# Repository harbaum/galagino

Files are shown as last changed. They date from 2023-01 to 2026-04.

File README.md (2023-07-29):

# Galagino - ESP32 Arcade Emulator

Play Galaga, Pac-Man, Donkey Kong, Frogger, Digdug and 1942 on the ESP32

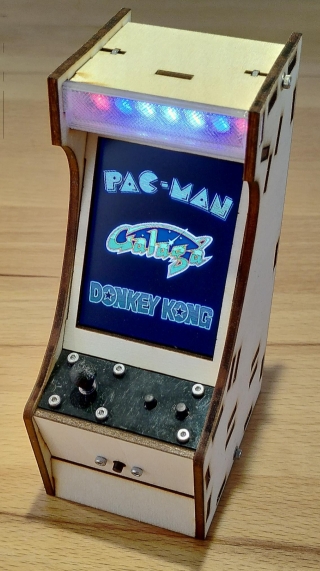
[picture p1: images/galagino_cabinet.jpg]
Cabinet


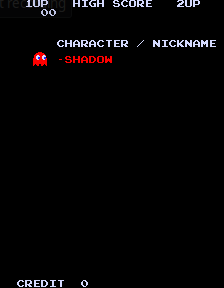
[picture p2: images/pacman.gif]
Pac-Man screenshot

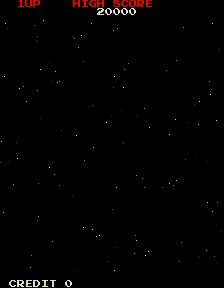
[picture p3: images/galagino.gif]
Galaga screencast

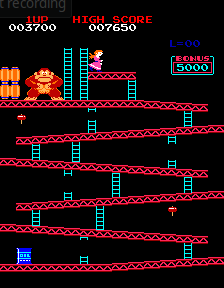
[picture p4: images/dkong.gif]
Donkey Kong screenshot

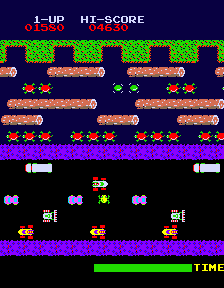
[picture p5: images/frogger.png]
Frogger screenshot

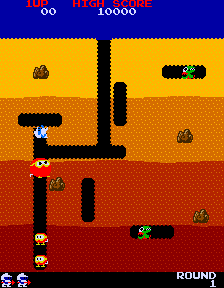
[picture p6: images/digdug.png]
Digdug screenshot

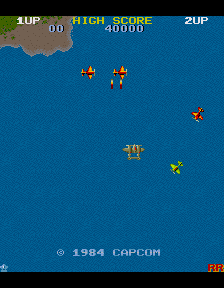
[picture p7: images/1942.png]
1942 screenshot


[Pac-Man](https://en.wikipedia.org/wiki/Pac-Man),
[Galaga](https://en.wikipedia.org/wiki/Galaga) and
[Donkey Kong](https://en.wikipedia.org/wiki/Donkey_Kong_(video_game)) are three of the most
iconic arcade machines of all times and are listed on places #1 to #3
on the [Killer List of Video Games](http://www.klov.net).

Especially Pac-Man and Galaga have been remade and emulated many
times. So far the cheapest and smallest system able to do a faithful
emulation of the original arcade machines was the raspberry pi. But
even the much cheaper ESP32 should be able to easily emulate a machine
from the early ’80s, shouldn't it?

Well, things are not that easy. The Galaga arcade was driven by three
Z80 CPUs, each running at 3Mhz. Additionally the arcade machine
included two more CPUs, one for button and coin handling and one for audio
support. And finally the hardware itself had dedicated support
for simple wavetable audio, tilemap graphics and up to 64 sprites.
The video resultion was 224 by 288 pixels.

The ESP32 on the other hand
comes with two cores running at 240MHz. But it lacks dedicated video
hardware. Emulating the various CPUs as well as the handling of
audio and graphics turned out to be challenging for the ESP32.

Cheap TFT screens with a resolution of 320 by 240 pixels are avaialable
in various sizes from 2.0 inch to 3.2 inch allowing for a very small
and cheap *galagino* setup.

These small displays usually allow for SPI clock rates of up to 40MHz
allowing for a max screen refresh rate of ~30Hz. This is exactly half
the refresh rate of the original arcade machine. 30Hz is sufficient
for a very fluid gameplay. However, with displays coping with 80MHz
SPI clock, Galagino will run at full 60Hz refresh.

## Youtube videos

* [First Galaga Emulation test ](https://www.youtube.com/shorts/LZRI6izM8XM)
* [Sound and Starfield working](https://www.youtube.com/shorts/8uNSv0aRtgY)
* [Galaga is finally playable](https://www.youtube.com/shorts/wqnJzOAAths)
* [Pac-Man on Galagino](https://www.youtube.com/shorts/F4-XiiPwG1c)
* [Donkey Kong on Galagino](https://www.youtube.com/shorts/KROFJ0Rtj0w)
* [Boot menu](https://www.youtube.com/shorts/_PJyn06yrtg)
* [Cardboard cabinet prototype](https://youtube.com/shorts/vverV4NphlQ)
* [Finished plywood cabinet](https://youtube.com/shorts/a3-wctRAIds)
* [John Bradnam's 3D printed case](https://www.youtube.com/watch?v=p29Yvht4jSI)
* [Frogger on Galagino](https://youtube.com/shorts/LrBkN1pu7yE)
* [Digdug on Galagino](https://youtube.com/shorts/fmQmfKEhVy4)

## Hardware

### Original Hardware
The hardware is built around one of those cheap ESP32 development
boards like the ESP32 Devkit V4 depicted in the images below. The
components needed for the breadboard setup are listed below. If you
plan to build the [cabinet](hardware/cabinet) instead you might want
to make sure you [order the exact parts](./hardware) that
aren't only electrically compatible but also mechanically.

* ESP32 development board (e.g. [Devkit V4](https://www.espressif.com/en/products/devkits/esp32-devkitc))
* A 320x240 SPI TFT screen (no touch needed)
  * Either a ILI9341 based screen as depicted, or
  * a ST7789 based screen with 320x240 pixels
* An audio amplifier and speaker
  * e.g. a [PAM8302A](https://www.adafruit.com/product/2130) and a 3W speaker (as seen in the photos), or
  * a [Keyestudio SC8002B](https://www.keyestudio.com/products/keyestudio-sc8002b-audio-power-amplifier-speaker-module-for-arduino-player), or similar 
* five push buttons, or
* one push button and a five way joystick breakout (for Pac-Man and Donkey Kong)
* breadboard and wires

The entire setup should be connected as depicted below. The Devkit is
too wide for the breadboard leaving no space above it to connect
wires. Thus the wires going to the top pin row of the Devkit are
placed underneath the DevKit with the connections done as shown in the
image below. See [galagino/config.h](galagino/config.h) for the button
mappings.

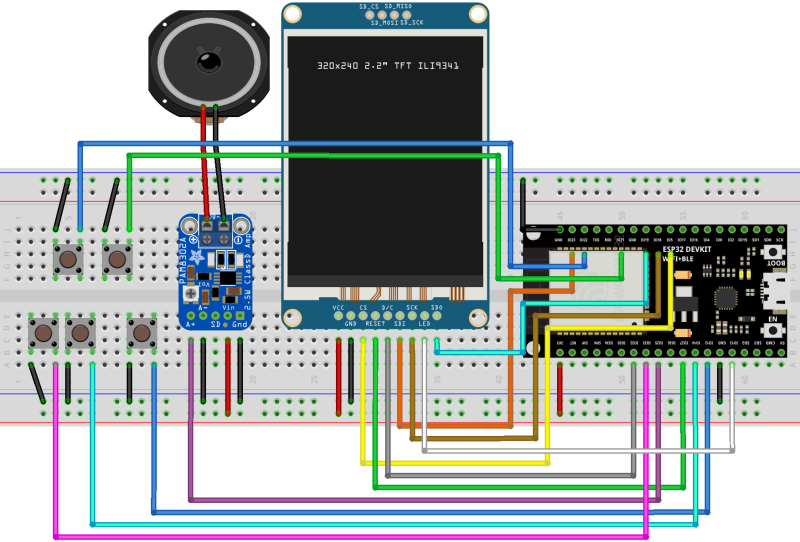
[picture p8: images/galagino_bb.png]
Breadboard scheme


[PDF](images/galagino_bb.pdf)

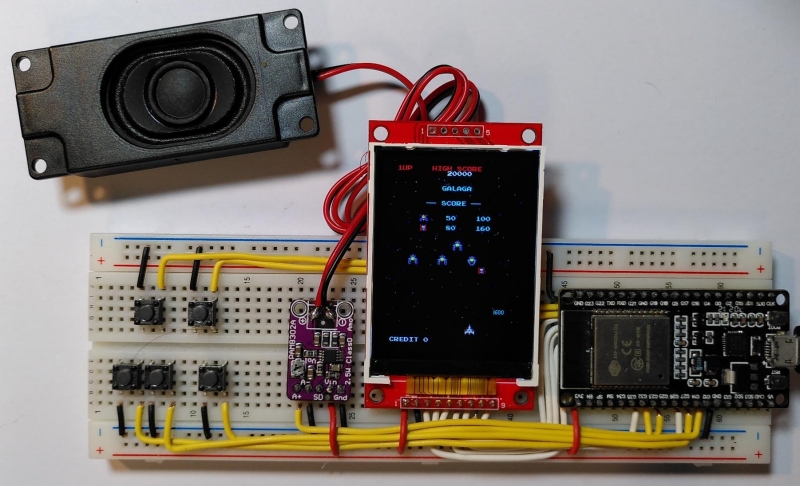
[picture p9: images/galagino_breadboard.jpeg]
Breadboard photo


This setup with five buttons works fine for Galaga since there is no
vertical movement in the game that requires a joystick. A joystick is
needed for Pac-Man and Donkey Kong. The joystick based setup would
then be wired in the following way:

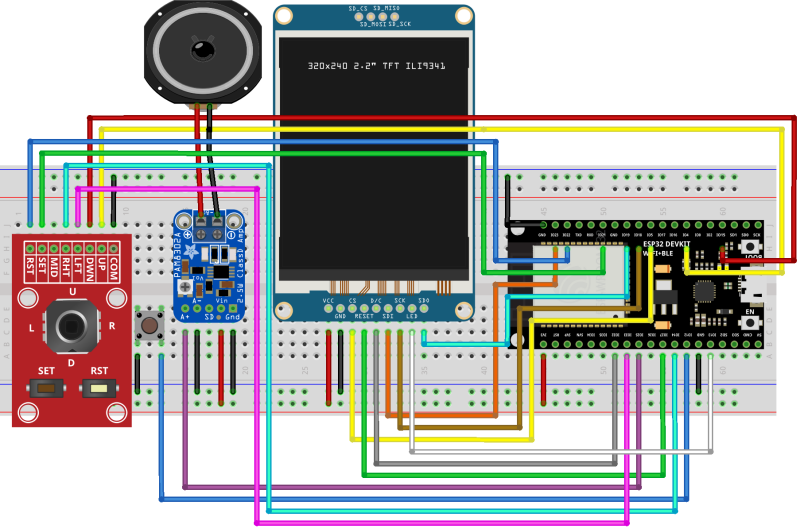
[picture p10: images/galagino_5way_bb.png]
Breadboard scheme with 5 way joystick


[PDF](images/galagino_5way_bb.pdf)

### "Cheap Yellow Display"
The ESP32-2432S028R A.K.A. the [Cheap Yellow Display](https://github.com/witnessmenow/ESP32-Cheap-Yellow-Display) is an ESP32 Board that comes with the majority of hardware required to build a Galagino device.

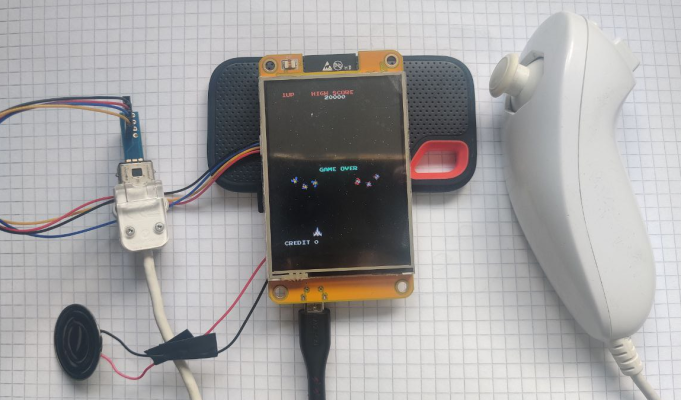
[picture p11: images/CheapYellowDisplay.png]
Cheap Yellow Display


Hardware Needed:
- Cheap Yellow Display
- [A Nintendo Wii nunchuck and adaptor](hardware/NUNCHUCK.MD) - This can be connected to the JST connector labled "CN1" with the cable included with the display
- A speaker - This can be attached to the display with a 1.25mm JST connector to the connector labled "SPEAK" (or soldered)

Note: The `Start` button is connected to the "boot" button on the board.

To get the project working on the Cheap Yellow Display, just uncomment the `#define CHEAP_YELLOW_DISPLAY_CONF` line in [galagino/config.h](galagino/config.h)

## Software

**Important notice 1:** You really need to use the Arduino IDE as it
provides the optimization settings required for sufficient
perfgormance of Galaga and Digdug by default. E.g. PlatformIO doesn't
seem to enable enough optimization.

**Important notice 2:** I2S/DAC support seems to be [broken in the
ESP32 board package version 2.0.10 and
up](https://github.com/espressif/arduino-esp32/issues/8467). Please
use ESP32 board package 2.0.9 or older for a clean sound.

The software consists of three parts:

* The [Galagino specific code](galagino/) contained in this repository
* The orignal ROM files
    * [Galaga (Namco Rev. B ROM)](https://www.bing.com/search?q=galaga+namco+b+rom)
    * [Pac-Man (Midway)](https://www.bing.com/search?q=pacman+midway+arcade+rom)
    * [Donkey Kong (US set 1)](https://www.bing.com/search?q=donkey+kong+arcade+rom)
    * [Frogger](https://www.bing.com/search?q=frogger+arcade+rom)
    * [Digdug](https://www.bing.com/search?q=digdug+arcade+rom)
    * [1942](https://www.bing.com/search?q=1942+arcade+rom)	
* A [Z80 software emulation](https://fms.komkon.org/EMUL8/Z80-081707.zip) by [Marat Fayzullin](https://fms.komkon.org/)

Galagino uses code that is not freely available and thus not included in this
repository. Preparing the firmware thus consists of a few additional steps:

* The ROM files have to be placed in the [roms directory](roms/), together with the ZIP file containing the Z80 emulator.
* A set of [python scripts](romconv/) is then being used to convert and
 patch the ROM data and emulator code and to include the resulting code into the
galagino sketch directory.
* The same scripts are afterwards being used to convert [audio sample files](./samples) into the desired format.

The [ROM conversion](./romconv) as well as the [audio sample
conversion](./samples) create a whole bunch of additional files in the
[galagino directory](./galagino). Please check the README's in the
[romconv](./romconv) and [samples](./samples) directories for further
instructions.

With all these files in place, the galagino.ino sketch can be loaded
into the [Arduino IDE](https://docs.arduino.cc/software/ide-v2). The
Arduino IDE must have the [ESP32 board support](https://docs.espressif.com/projects/arduino-esp32/en/latest/installing.html)
installed and the appropriate board like e.g. the
*ESP32 Dev Module* should be selected. Finally the default core used
by Arduino should be 1 (this is the default) as Galagino will use core 0
for audio and video emulation. Furthermore the FastLED library should
be installed to support the LEDs in the [cabinets marquee](./hardware/cabinet).
LED support can be disabled in the configuration if no LEDs are going to be installed.

## Configuration

The Galagino code can be configured through the [galagino/config.h](galagino/config.h)
file. This is also the place where it's possible to choose between the ILI9341
controller (default) and the ST7789.

Also the pin assignment can be adjusted as well as the TFT SPI clock or the
use of LEDs for the marquee.

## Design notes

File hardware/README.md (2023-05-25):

# Galagino cabinet

This is a list of all parts required to build a complete Galagino
[cabinet from plywood](./cabinet). Further instructions are linked below.

If you don't have access to a laser cutter or prefer a fully 3d
printed case then you should have a look at [John Bradnam's great
Galagino case](https://www.hackster.io/john-bradnam/galagino-esp32-arcade-355dde).

## Electric and electronic parts

* [38 pin ESP32 Devkit](https://www.espressif.com/en/products/devkits/esp32-devkitc)
* 2.8 inch 320x240 ILI9341 display
  * mounted on 50mm x 86mm PCB
  * no touch screen required
* [PAM8302A](https://www.adafruit.com/product/2130) amplifier
* cased 3W / 8 ohms speaker as seen e.g. in the [cabinet photos](./cabinet)
* 7 x WS2812B LED stripe
  * 7 LEDs cut from a 144 LEDs per meter stripe
* four 6mm x 6mm push buttons, through hole, height 4.3mm
* three 6mm x 6mm push buttons, through hole, height 9mm
* ~50 cm 10 wire flat ribbon cable

## Screws and nuts

* 10 pcs M2 x 8mm screws
  * 4 for the [cabinet](./cabinet), 2 for the [coin button](./coinbutton), 4 for the speaker
* 6 pcs M2 x 12mm screws
  * for the 3D printed [control board](./controlboard)
* one M2 x 16mm screw
  * for the 3D printed [control board](./controlboard)
* 14 M2 nuts
  * 6 for the control board, 4 for the cabinet, 4 for the speaker
* 8 M2 washers
  * 4 for the cabinet, 4 for the control board

## Mechanical parts

* [15 lasercut plywood parts](./cabinet)
* [3D printed coin button holder](./coinbutton)
* [3D printed black control board](./controlboard)
* [3D printed transparent marquee](./marquee)

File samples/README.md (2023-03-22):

# Samples

Some arcade machines contained special hardware to generate certain
sounds. Emulating this hardware may be tricky and the flash memory
size of the ESP32 allows to store some of these as digital sound
samples.

This directory contains one sample needed for the explosion sound
in Galaga and three more samples for Donkey Kong.

These have to be converted into C source code using the
[romconv.py](../romconv/romconv.py) tool.

```
../romconv/romconv.py galaga_sample_boom ./galaga_boom.s8 ../galagino/galaga_sample_boom.h
```

Donkey Kong does most audio via its MB8884/I8048 audio CPU. But three
sounds are generated via discrete logic including three variants of
the walk sound. These are still regenerated using samples.

```
../romconv/romconv.py dkong_sample_walk0 ./dkong_walk0.s8 ../galagino/dkong_sample_walk0.h
../romconv/romconv.py dkong_sample_walk1 ./dkong_walk1.s8 ../galagino/dkong_sample_walk1.h
../romconv/romconv.py dkong_sample_walk2 ./dkong_walk2.s8 ../galagino/dkong_sample_walk2.h
../romconv/romconv.py dkong_sample_jump ./dkong_jump.s8 ../galagino/dkong_sample_jump.h
../romconv/romconv.py dkong_sample_stomp ./dkong_stomp.s8 ../galagino/dkong_sample_stomp.h
```

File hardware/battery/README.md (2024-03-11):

# Battery powered Galagino

The Galagino by default runs from USB power supply. The cabinet
has some empty space at its very bottom which can be used to
mount a battery incl. charger and 5V supply. The parts can
be mounted to [part 8 of the cabinet](../cabinbet). 

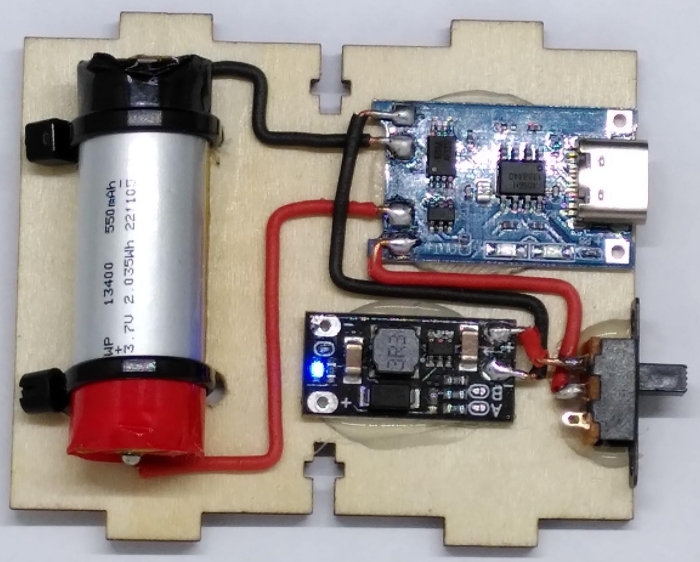
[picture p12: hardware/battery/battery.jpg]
Battery mounted


The battery in this example has been take from a Vape. Although
these are designed to be disposable they contain rechargeable
batteries which can be re-used in projects like this. The one
depicted above is a 550 mAh battery from a vape. These can
be disassembled rather easily and besides the strong sweet smell
these are easy to use.

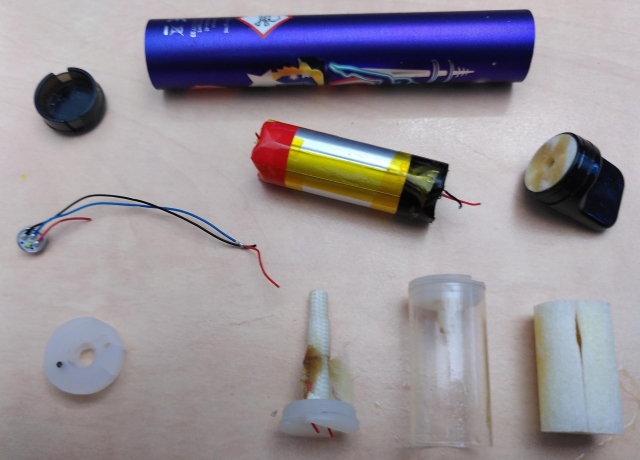
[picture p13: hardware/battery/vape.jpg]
Vape


Only few parts are needed besides the battery itself.

  - A charger board (e.g. powered via USB)
  - A battery protection circuit
  - A DC/DC converter generating 5V from the battery voltage

Various cheap charger boards contain some or all of these parts.
The setup depicted above uses the two board. The top one
combines a USB charger with the battery protection circuit.
The smaller PCB at the bottom is a DC/DC converter generating
5V from the batteries 3.7V.

A toggle switch mounted between the battery and the DC/DC
converter allows to turn the device on and off. The 5V are
then fed into the 5V input of the ESP32 board.

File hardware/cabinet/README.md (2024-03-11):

# Cabinet

The cabinet is built from 15 lasercut 3mm plywood parts and is designed to
house [common off-the-shelf electronic components](../).

## Versions

There are currently two versions of the case. 

- [lasercut_parts.svg](lasercut_parts.svg) is the original version to be
  used with a USB power supply (no battery) and with a wiring directly
  done to the board (no additional PCBs)
  
- [lasercut_parts_with_battery.svg](lasercut_parts_with_battery.svg) is
  a slightly modified version with the following changes:

    - Cutouts in part 8 to allow to mount a [small battery](../battery) using zip ties
    - Cutouts in part 12 for a power switch and the USB connector of a charging board mounted in part 8
    - Cutout in part 1 to give some room to the joystick connector of the [PCB set](../pcbs).
    - Shortended the "arm" of part 10 a little bit to make room for the cable connecting the LED stripe 
    - Cutouts in parts 11 and 13 to allow a power cable to be routed from the battery to the ESP32

The cabinet may have to be modified further if different parts are being used.

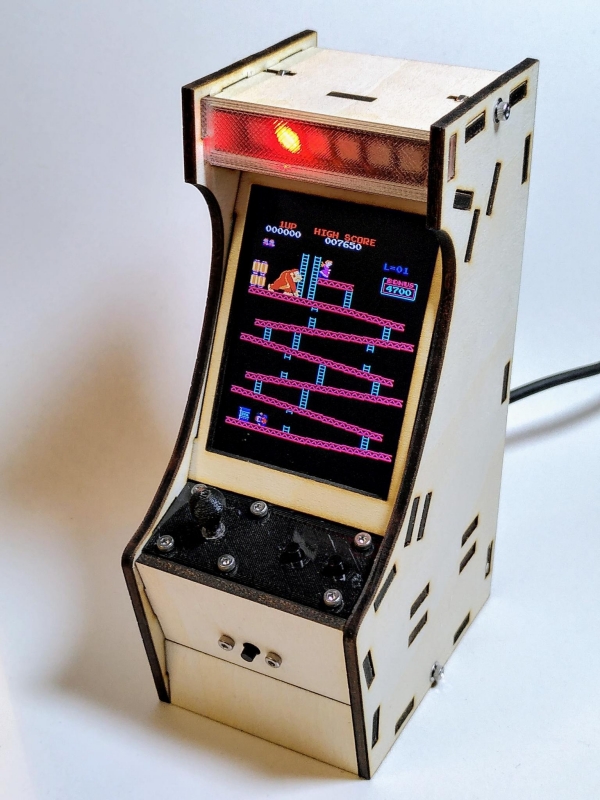
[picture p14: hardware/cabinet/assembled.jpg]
The assembled cabinet


The cabinet consists of two main side sections and 13 parts to be
mounted between both sides. The electronic parts are either secured
between two wooden parts (the display between parts 1, 5 and 10 and
the ESP32 between parts 11 and 13) or screwed to a wooden part (the
speaker to part 12 and the coin button to part 6). The LED stripe
comes with adhesive tape and sticks to its wooden part 9.

The [transparent plastic part for the marquee](../marquee) as well as
the [control board](../controlboard) and the [coin
button](../coinbutton) are 3d printed and are either screwed to the
plywood parts 6 and 12 or use the same 3mm flanges and are inserted
into the side parts just like the other wooden parts are.

If no illuminated marquee is wanted, then the plywood part 2 is used
instead of the 3D printed transparent part and the LED stripe is not
attached to part 9.

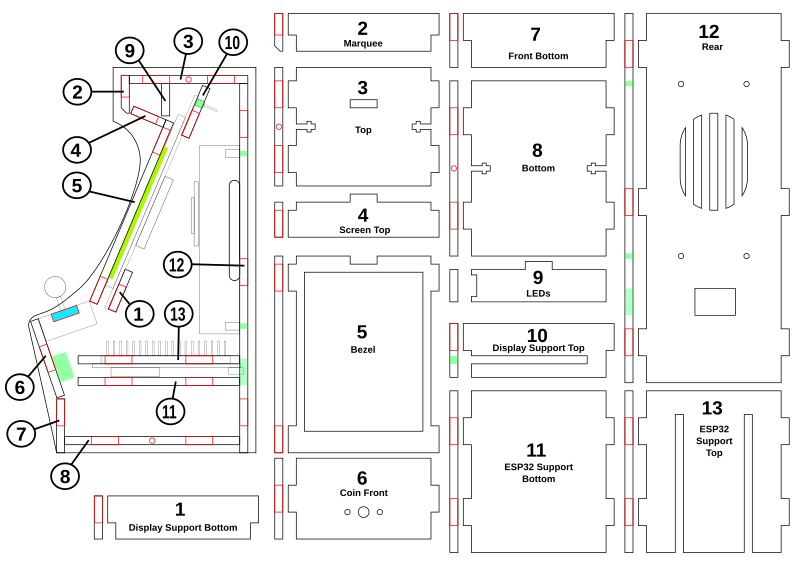
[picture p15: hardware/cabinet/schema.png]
Schema


Also available as [PDF](schema.pdf)

The following files can be used with most laser cutters. All parts fit
onto one single A4 sized piece of 3mm thick plywood.

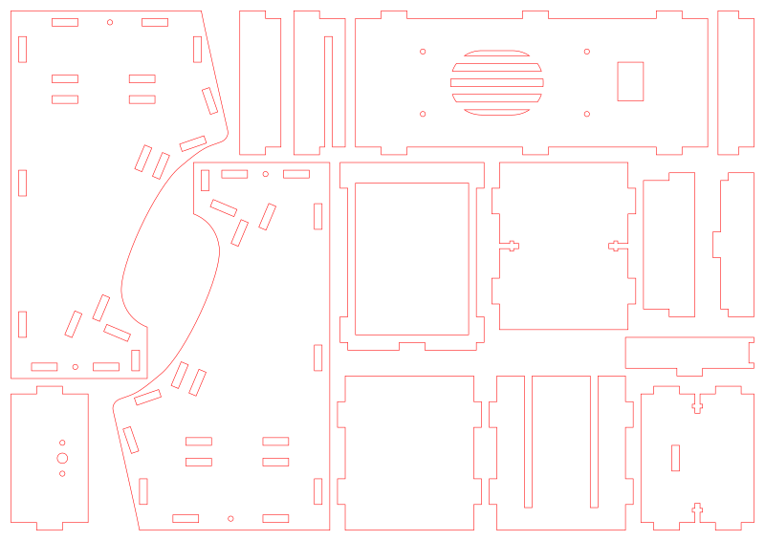
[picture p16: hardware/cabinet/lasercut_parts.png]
Lasercut Parts CAD


Also available as [SVG](lasercut_parts.svg) and [PDF](lasercut_parts.pdf)

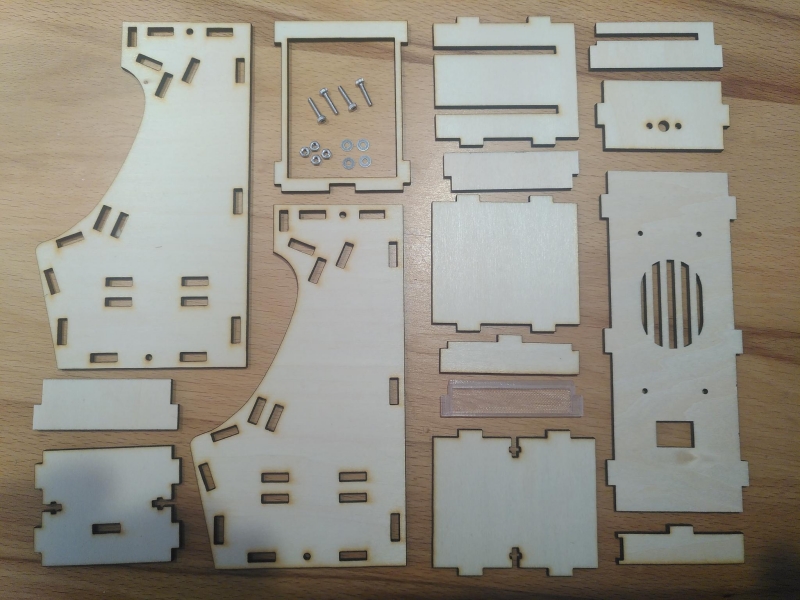
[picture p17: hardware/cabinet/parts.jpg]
Lasercut Parts


Once the electronics are [assembled and tested](../assembly) they are
mounted to their plywood parts.

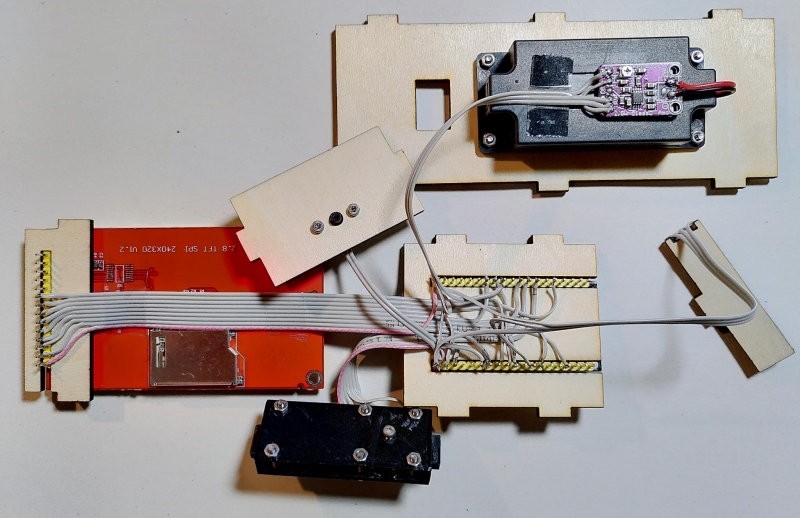
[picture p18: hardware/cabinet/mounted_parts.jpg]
Mounted parts


The LEDs are attached to plywood part 9 and inserted into the top part
3. Once the top part is secured to one side using a M2*8mm screw part
9 attaches quite firmly to the top part 3. Its cable needs to go above
the display and plywood part 10.

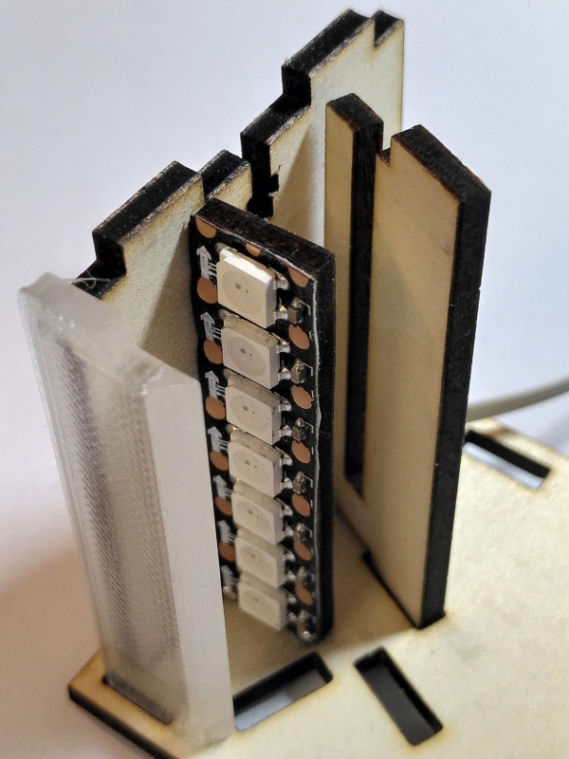
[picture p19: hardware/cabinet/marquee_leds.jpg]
Marquee LEDs detail


All parts are assembled onto one of the two identical side parts. Afterwards the second side is mounted.

It's helpful to leave the rear part 12 open while attaching the second
side. That way the other parts inside can be reached from the rear and be moved to their exact positions until both sides attach firmly.

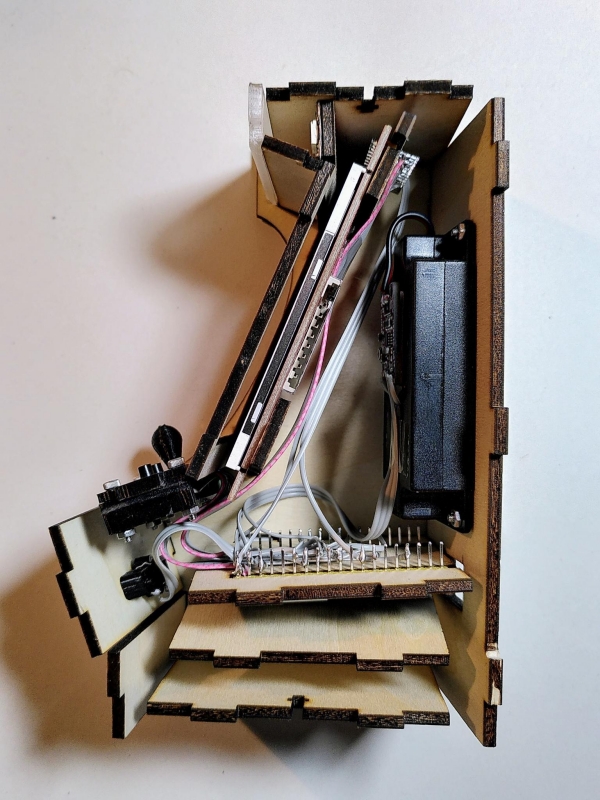
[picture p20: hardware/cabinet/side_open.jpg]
One side open


Once both sides are fully attached the rear part 12 can carefully be
inserted to finish the setup. During assembly the sides may be secured
using e.g. masking tape. Once they are done four M2 * 8mm screws and
four M2 nuts are used to secure the sides to parts 3 and 8.

Be careful not to drop the nuts into the assembled device. A piece of
tape placed at the inside of parts 3 and 8 may help keeping the nuts
from being lost during assembly.

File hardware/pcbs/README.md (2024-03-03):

# Galagino PCB set

The Galagino PCB set is meant to make assembly much easier.
It consists of three PCBs. One is for the display, one for the
ESP32 and one for the joystick. 

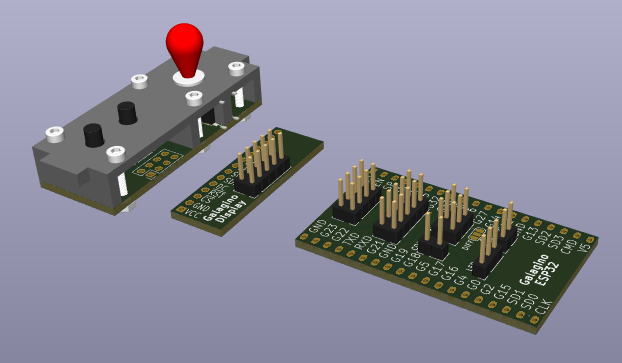
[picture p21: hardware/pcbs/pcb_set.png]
3D rendering of PCB set


The joystick comes with a freecad design for matching plastic parts:

- The main cover [controlboard_base.stl](controlboard_base.stl)
- The actuator that pusges against the direction buttons [controlboard_actuator.stl](controlboard_actuator.stl)
- The joystick control knob [controlboard_knob.stl](controlboard_knob.stl)
- Two raiser to be mounted below the start and fire button [btn_raiser.stl](btn_raiser.stl)

The joystick uses standard 6x6mm through-hole buttons with the legs
bent 90 deg outwards to go through the PCB and the other legs being
cut.

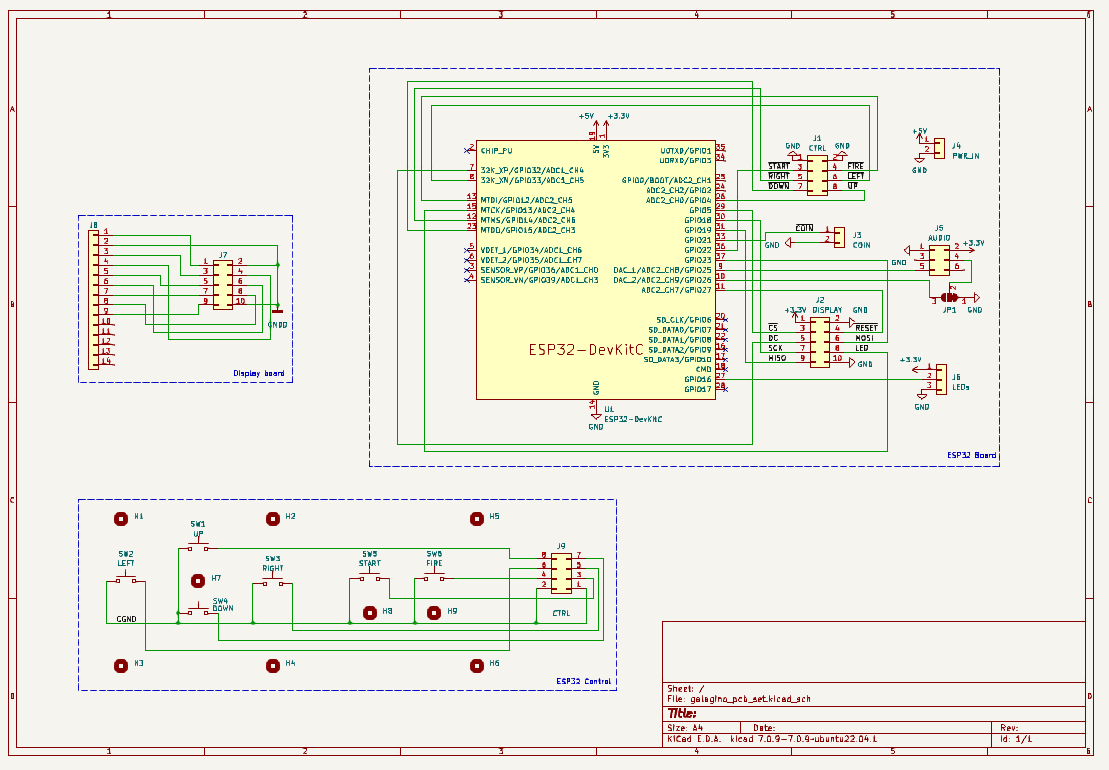
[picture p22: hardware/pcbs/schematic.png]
Schematic
[PDF](schematic.pdf)

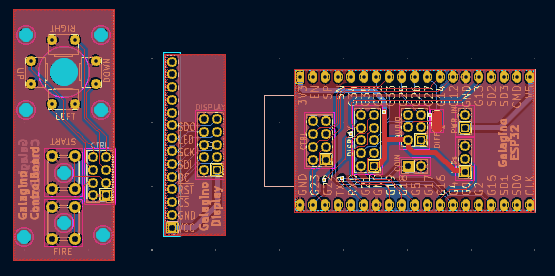
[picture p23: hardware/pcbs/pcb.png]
PCBs


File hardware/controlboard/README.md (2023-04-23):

# Galagino Control Board

The control board is a simple joystick and button compartment for
use with galagino. It consists of four 3d printed parts.

Additionally needed:

- Six screws M2x12mm
- One screw M2x16mm
- Six M2 nuts
- Four M2 washers
- Four 6x6mm push buttons, through hole, height 4.3mm
- Two 6x6mm push buttons, through hole, height 9mm

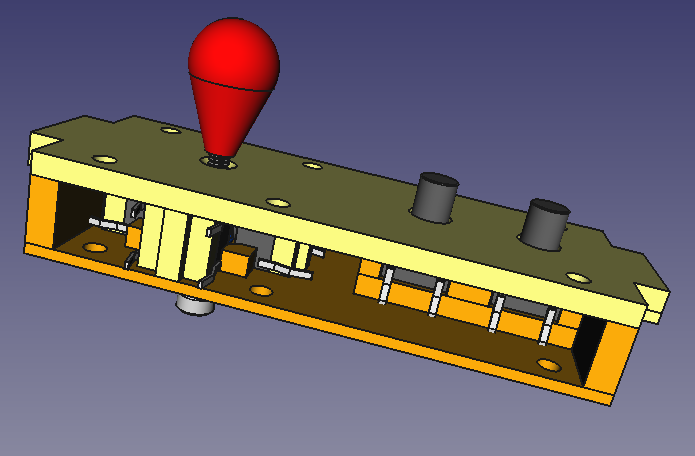
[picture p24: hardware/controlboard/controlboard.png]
CAD screenshot


The control boards surface is 50mm wide and thus matches the width
of a 2.8 inch TFT display. The control board has two 3x10mm flanges
to be used with a small laser cut cabinet.

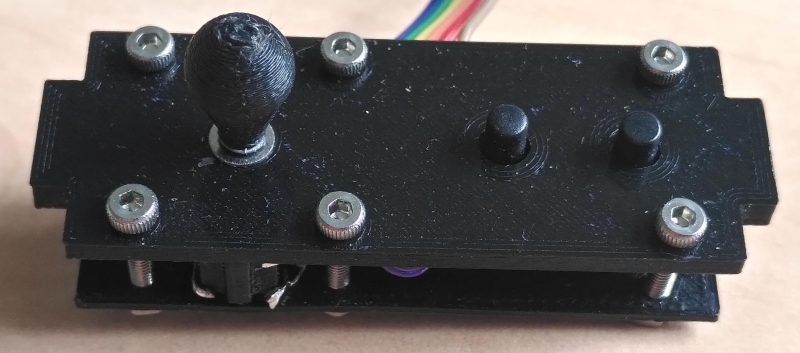
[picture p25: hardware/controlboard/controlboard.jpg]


## Wiring

The colors and order of the wires in the following schema matches the
colors and order of the wires in the [assembly instructions](../assembly).

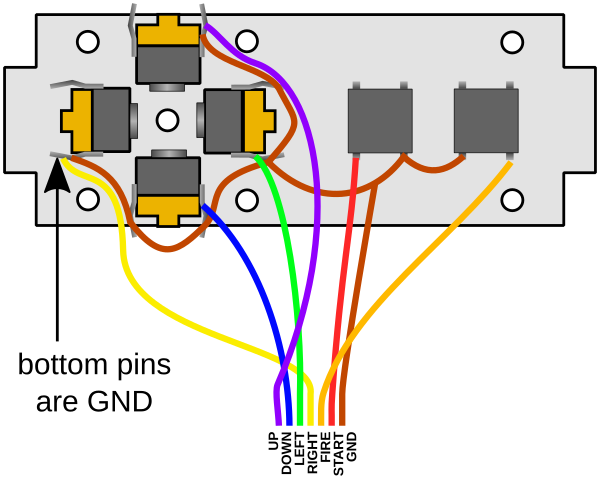
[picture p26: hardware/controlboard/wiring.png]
Wiring


The wiring of the controlboard is a little bit delicate. It starts
with a GND wire connecting one pin of each button. The wires may
protrude to the bottom as this will be inside the final cabinet. But
they must not protrude to the top as this will be the front face which
is convered by a plywood part which won't leave any space for cables.

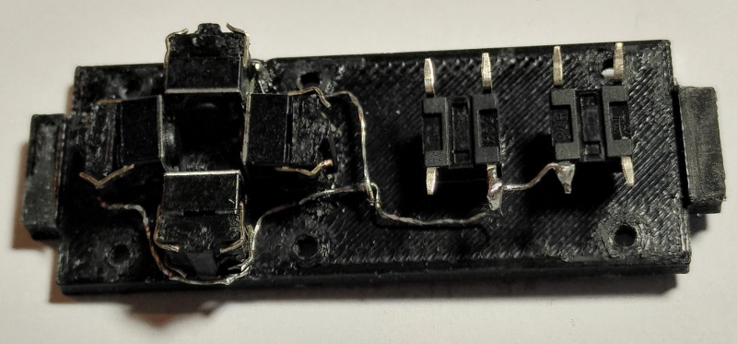
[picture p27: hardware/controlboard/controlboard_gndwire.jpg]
GND wire


Once all ground connections are done, a seven wire ribbon cable is
connected to all buttons and to the GND wire:

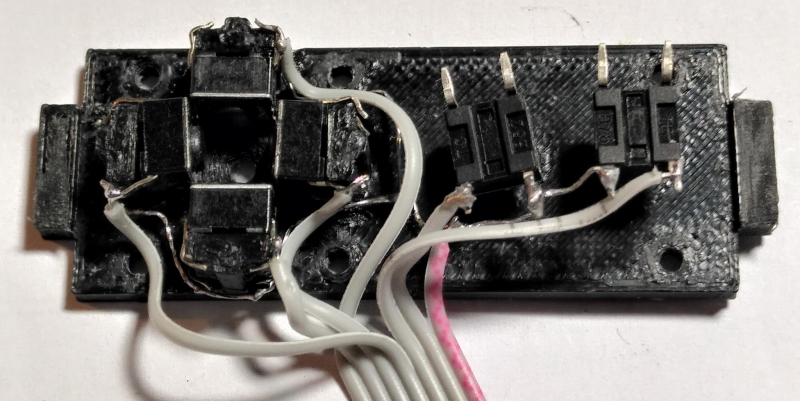
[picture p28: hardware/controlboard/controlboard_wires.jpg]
wires


## Assembly

Assembly starts with the buttons being attached to the base plate and
being soldered to the wires. The limiter and actuator are assembled
with the M2x16mm screw and one M2 washer.

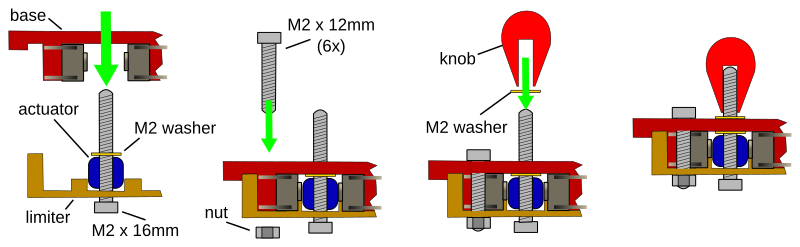
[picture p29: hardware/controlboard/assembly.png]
Assembly


Both parts are then connected using six M2x12mm screws and nuts. And
finally the knob is attached with another M2 washer.

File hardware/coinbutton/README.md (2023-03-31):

# Coin Button

This is a simple bracket needed to mount the coin button to the
[cabinet](../cabinet).

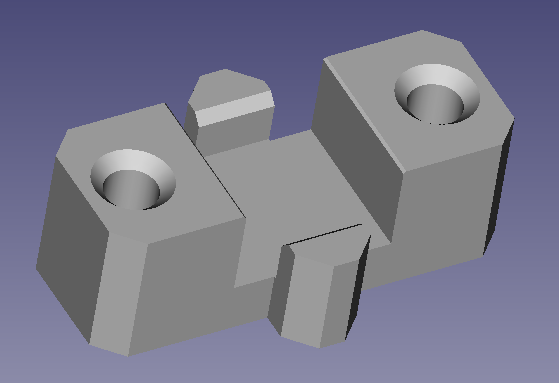
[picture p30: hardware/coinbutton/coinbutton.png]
CAD


Additionally needed:

- Two screws M2 x 8mm
- One 6x6mm push button, through hole, height 9mm

The coinbutton is screwed to part 6 of the [cabinet](../cabinet).

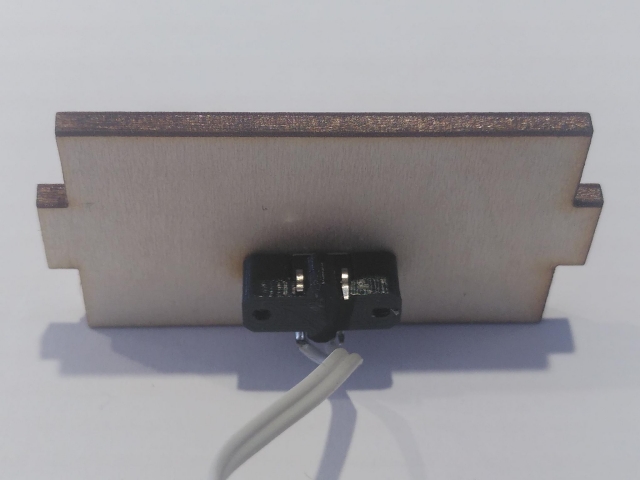
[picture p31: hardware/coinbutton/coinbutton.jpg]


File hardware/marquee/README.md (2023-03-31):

# Marquee

The marquee can optionally be equipped with seven WS2812B LEDs.
The [cabinet](../cabinet) part 2 made of plywood then needs to be
replaced by this transparent 3d printed replacement.

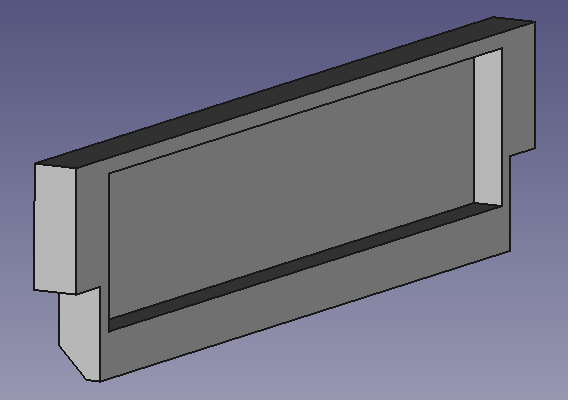
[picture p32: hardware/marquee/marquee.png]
Marquee CAD


[FreeCAD](marquee.FCStd) [STL](marquee.stl)

This part is then mounted at the cabinets top front.

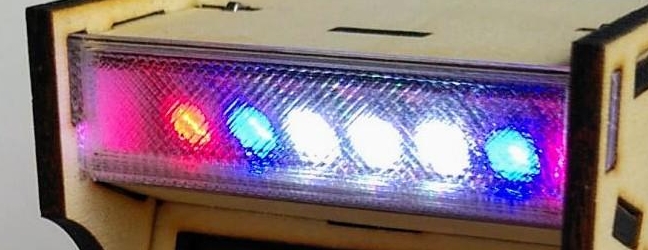
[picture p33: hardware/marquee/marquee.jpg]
Marquee photo


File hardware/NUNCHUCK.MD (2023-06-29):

# Nunchuck

A Nunchuck controller from a Nintendo Wii can be used as input device for Galagino builds. 
They are inexpensive and since they use i2c for communication, they only require 2 GPIO pins to connect them up.

## Hardware Required

- Nunchuck controller - Official Nintendo ones are generally better (maybe try second-hand options), but third-party ones also work fine.
- A Nunchuck adapter - Here is one from [Adafaruit](https://www.adafruit.com/product/4836), but there are many different options available for these, even the cheap ones from Aliexpress work perfectly.

## Wiring

- SDA and SCL of the Nunchuck can be connected to any two GPIO of the ESP32. 
- Power pins of the Nunchuck should be connected to 3.3v and Gnd

Note: I have found pull-ups resistors are not required on SDA and SCL

## Configuration

The nunchuck can be enabled in 'conf.h' as follows

```
#define NUNCHUCK_INPUT

#define NUNCHUCK_SDA 22 // The GPIO pin connected to SDA of the nunchuck
#define NUNCHUCK_SCL 27 // The GPIO pin connected to SCL of the nunchuck

#define NUNCHUCK_MOVE_THRESHOLD 30 // This is the dead-zone for where minor movements on the stick will not be considered valid movements
                                   // Increase this value if you want to increase how far you need to move the nunchuck for a valid movement
```

Note: At time of writing the Start and optional Coin button are not enabled on the nunchuck and will still need to be wired to regular GPIO buttons

## Software

The nunchuck code requires an addtional library to be installed, [NintendoExtensionCtrl](https://github.com/dmadison/NintendoExtensionCtrl). It can be installed from the library manager.

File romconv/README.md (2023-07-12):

# romconv - ROM/bin file conversion

Arcade emulation involves dealing with the original ROM files of the
machines to be emulated. Sometimes the conversion is limited to the
transcription from binary to an equivalent C source file. But in many
cases the conversion includes further data processing. E.g. all color
tables are converted into the 16 bit color format used by the ILI9341
or ST7789 displays. Sprite and tile data is converted into a format
easier to process on the ESP32.

The conversion could be done on the ESP32 target at run time. But in
Galagino it's done beforehand. This offloads these tasks from the
ESP32.

It's possible to implement only one or two of the three arcade
machines. In that case the related ROM conversion can be omitted and
the machine in question has to be disabled in the file
[config.h](../galagino/config.h).

The necessary ROM files need be placed in the [roms
directory](../roms) before these scripts can be run. Once these are
converted the [audio samples](../samples) also need to be converted.

The logo conversion for the game selection menu might require the
seperate installation of the ```imageio python module``` which can
e.g. be done by the following command. This is usually not needed as
the logos are included pre-converted. This is only needed if you intend
the change the logos.

```pip3 install imageio```

## Do-it-all script

A [shell script](conv.sh) is included that does all the conversion.
If you prefer to do everything manually, then use the instructions
below. Otherwise running the script is all you need to do.

## Generic ROM conversion

The tilemap as well as the patched Z80 emulation are need by all three
arcade machines and thus have to be converted regardless which
machines are to be emulated.

```
./tileaddr.py ../galagino/tileaddr.h
./z80patch.py
```

## Pac-Man ROM conversion

Pac-Man comes with code ROMs as well as ROMs containing graphic data,
color tables and audio waveforms. These can be converted using the
following commands:

```
./audioconv.py pacman_wavetable ../roms/82s126.1m ../roms/82s126.3m ../galagino/pacman_wavetable.h
./cmapconv.py pacman_colormap ../roms/82s123.7f 0 ../roms/82s126.4a ../galagino/pacman_cmap.h
./logoconv.py ../logos/pacman.png ../galagino/pacman_logo.h
./romconv.py pacman_rom ../roms/pacman.6e ../roms/pacman.6f ../roms/pacman.6h ../roms/pacman.6j ../galagino/pacman_rom.h
./spriteconv.py pacman_sprites pacman ../roms/pacman.5f ../galagino/pacman_spritemap.h
./tileconv.py ../roms/pacman.5e ../galagino/pacman_tilemap.h
```

## Galaga ROM conversion

Galaga is technically very similar to Pac-Man and needs very similar
files. In this case three code ROMs need to be converted as the Galaga
arcade was driven by three Z80 CPUs.

The Galaga ROM for CPU #1 will be patched when given the ```-p```
option. This will disable the RAM and ROM tests of the Galaga arcade
machine and will speed up the loading of that machine in Galagino:

```
./romconv.py -p galaga_rom_cpu1 ../roms/gg1_1b.3p ../roms/gg1_2b.3m ../roms/gg1_3.2m ../roms/gg1_4b.2l ../galagino/galaga_rom1.h
```

For the full retro-experience simply omit the option and the resulting
Galagino setup will include all the self tests of the original
machine:

```
./romconv.py galaga_rom_cpu1 ../roms/gg1_1b.3p ../roms/gg1_2b.3m ../roms/gg1_3.2m ../roms/gg1_4b.2l ../galagino/galaga_rom1.h
```

The remaining files are just converted without patching.

```
./audioconv.py galaga_wavetable ../roms/prom-1.1d ../galagino/galaga_wavetable.h
./cmapconv.py galaga_colormap_sprites ../roms/prom-5.5n 0 ../roms/prom-3.1c ../galagino/galaga_cmap_sprites.h
./cmapconv.py galaga_colormap_tiles ../roms/prom-5.5n 16 ../roms/prom-4.2n ../galagino/galaga_cmap_tiles.h
./logoconv.py ../logos/galaga.png ../galagino/galaga_logo.h
./romconv.py galaga_rom_cpu2 ../roms/gg1_5b.3f ../galagino/galaga_rom2.h
./romconv.py galaga_rom_cpu3 ../roms/gg1_7b.2c ../galagino/galaga_rom3.h
./spriteconv.py galaga_sprites galaga ../roms/gg1_11.4d ../roms/gg1_10.4f ../galagino/galaga_spritemap.h
./starsets.py ../galagino/galaga_starseed.h
./tileconv.py ../roms/gg1_9.4l ../galagino/galaga_tilemap.h
```

Additionally the sample for the Galaga explosion sound needs to be
converted as described in the [samples](../samples) directory.

## Donkey Kong ROM conversion

Donkey Kong differs slightly from Pac-Man and Galaga but it also
conists code ROMs, graphics and colormaps that need to be converted.

```
./cmapconv.py dkong_colormap ../roms/c-2k.bpr ../roms/c-2j.bpr 0 ../roms/v-5e.bpr ../galagino/dkong_cmap.h
./logoconv.py ../logos/dkong.png ../galagino/dkong_logo.h
./romconv.py dkong_rom_cpu1 ../roms/c_5et_g.bin ../roms/c_5ct_g.bin ../roms/c_5bt_g.bin ../roms/c_5at_g.bin ../galagino/dkong_rom1.h
./romconv.py dkong_rom_cpu2 ../roms/s_3i_b.bin ../roms/s_3j_b.bin ../galagino/dkong_rom2.h
./spriteconv.py dkong_sprites dkong ../roms/l_4m_b.bin  ../roms/l_4n_b.bin  ../roms/l_4r_b.bin  ../roms/l_4s_b.bin ../galagino/dkong_spritemap.h  
./tileconv.py ../roms/v_5h_b.bin ../roms/v_3pt.bin ../galagino/dkong_tilemap.h
```

Sound was implemented in two different ways in Donkey Kong. Some
sounds were generated by the 8048 CPU which is emulated in
Galagino. But some sounds were generated using discrete logic. These
are generated from samples and need to be converted as described in
the [samples](../samples) directory.

## Frogger ROM conversion

Frogger uses the same ROM for tiles and sprites. Sprite and tile
coversion thus operate on the same files using the following commands:

```
./cmapconv.py frogger_colormap ../roms/pr-91.6l ../galagino/frogger_cmap.h
./logoconv.py ../logos/frogger.png ../galagino/frogger_logo.h
./romconv.py frogger_rom_cpu1 ../roms/frogger.26 ../roms/frogger.27 ../roms/frsm3.7 ../galagino/frogger_rom1.h
./romconv.py frogger_rom_cpu2 ../roms/frogger.608 ../roms/frogger.609 ../roms/frogger.610 ../galagino/frogger_rom2.h
./spriteconv.py frogger_sprites frogger ../roms/frogger.606 ../roms/frogger.607 ../galagino/frogger_spritemap.h
./tileconv.py ../roms/frogger.606 ../roms/frogger.607 ../galagino/frogger_tilemap.h
```

## Digdug ROM conversion

The Digdug hardware is very similar to Galaga. The video hardware is slightly more complex and
there are more video related ROMs to be converted.

```
./cmapconv.py digdug_colormap_tiles ../roms/136007.113 0 ../roms/136007.112 ../galagino/digdug_cmap_tiles.h
./cmapconv.py digdug_colormap_sprites ../roms/136007.113 16 ../roms/136007.111 ../galagino/digdug_cmap_sprites.h
./cmapconv.py digdug_colormaps ../roms/136007.113 ../galagino/digdug_cmap.h
./logoconv.py ../logos/digdug.png ../galagino/digdug_logo.h
./audioconv.py digdug_wavetable ../roms/136007.110 ../roms/136007.109 ../galagino/digdug_wavetable.h
./romconv.py digdug_rom_cpu1 ../roms/dd1a.1 ../roms/dd1a.2 ../roms/dd1a.3 ../roms/dd1a.4 ../galagino/digdug_rom1.h
./romconv.py digdug_rom_cpu2 ../roms/dd1a.5 ../roms/dd1a.6 ../galagino/digdug_rom2.h
./romconv.py digdug_rom_cpu3 ../roms/dd1.7 ../galagino/digdug_rom3.h
./romconv.py digdug_playfield ../roms/dd1.10b ../galagino/digdug_playfield.h
./spriteconv.py digdug_sprites digdug ../roms/dd1.15 ../roms/dd1.14 ../roms/dd1.13 ../roms/dd1.12 ../galagino/digdug_spritemap.h
./tileconv.py ../roms/dd1.9 ../galagino/digdug_tilemap.h
./tileconv.py ../roms/dd1.11 ../galagino/digdug_pftiles.h
```

## 1942 ROM conversion

1942 uses more and more colorful graphics than the other systems and thus uses more and bigger graphics ROMs. It#s also the only system on this list using banking techniques to increase the CPU code ROM sizes.

```
./cmapconv.py _1942_colormap_chars ../roms/sb-5.e8,../roms/sb-6.e9,../roms/sb-7.e10 128 ../roms/sb-0.f1 ../galagino/1942_character_cmap.h
./cmapconv.py _1942_colormap_tiles ../roms/sb-5.e8,../roms/sb-6.e9,../roms/sb-7.e10 -1 ../roms/sb-4.d6,../roms/sb-3.d2,../roms/sb-2.d1 ../galagino/1942_tile_cmap.h
./cmapconv.py _1942_colormap_sprites ../roms/sb-5.e8,../roms/sb-6.e9,../roms/sb-7.e10 64 ../roms/sb-8.k3 ../galagino/1942_sprite_cmap.h
./logoconv.py ../logos/1942.png ../galagino/1942_logo.h
./romconv.py _1942_rom_cpu1 ../roms/srb-03.m3 ../roms/srb-04.m4 ../galagino/1942_rom1.h
./romconv.py _1942_rom_cpu1_b0 ../roms/srb-05.m5 ../galagino/1942_rom1_b0.h
./romconv.py _1942_rom_cpu1_b1 ../roms/srb-06.m6 ../galagino/1942_rom1_b1.h
./romconv.py _1942_rom_cpu1_b2 ../roms/srb-07.m7 ../galagino/1942_rom1_b2.h
./romconv.py _1942_rom_cpu2 ../roms/sr-01.c11 ../galagino/1942_rom2.h
./spriteconv.py _1942_sprites 1942 ../roms/sr-14.l1 ../roms/sr-15.l2 ../roms/sr-16.n1 ../roms/sr-17.n2 ../galagino/1942_spritemap.h
./tileconv.py ../roms/sr-02.f2 ../galagino/1942_charmap.h
./tileconv.py ../roms/sr-08.a1 ../roms/sr-09.a2 ../roms/sr-10.a3 ../roms/sr-11.a4 ../roms/sr-12.a5 ../roms/sr-13.a6 ../galagino/1942_tilemap.h
```

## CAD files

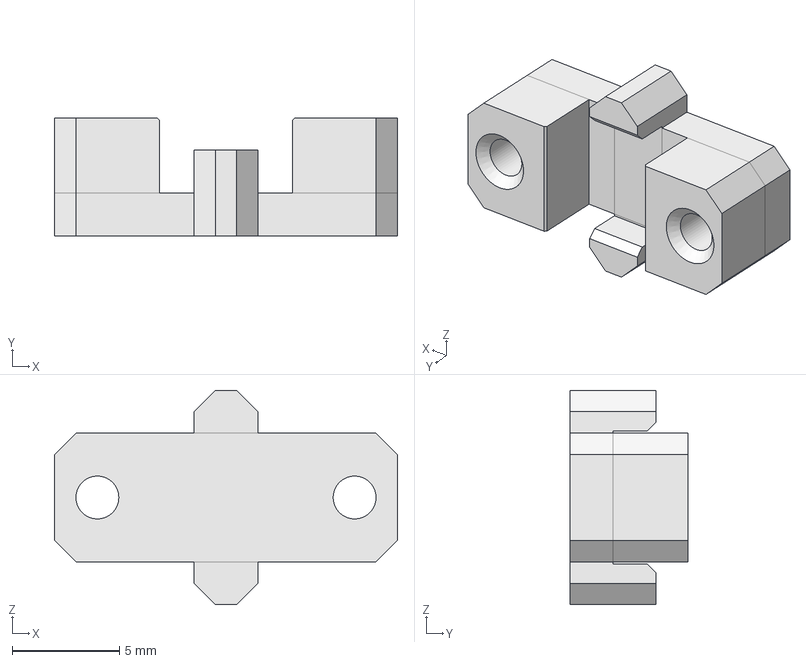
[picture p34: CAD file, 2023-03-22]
hardware/coinbutton/coinbutton.FCStd
16.0 x 5.50 x 10.0 mm

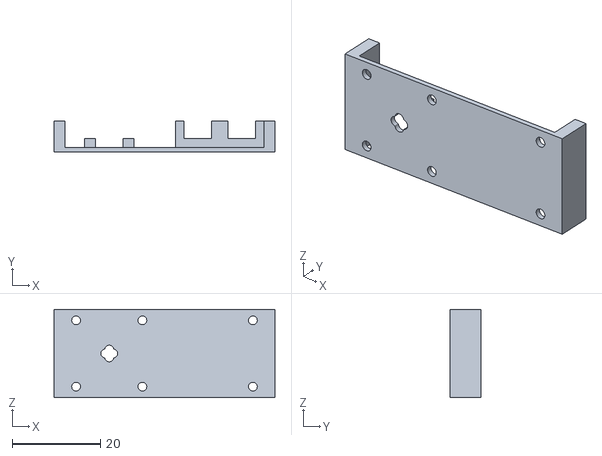
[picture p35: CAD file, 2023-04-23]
hardware/controlboard/galagino_controlboard-limiter.stl
50.0 x 7.00 x 20.0

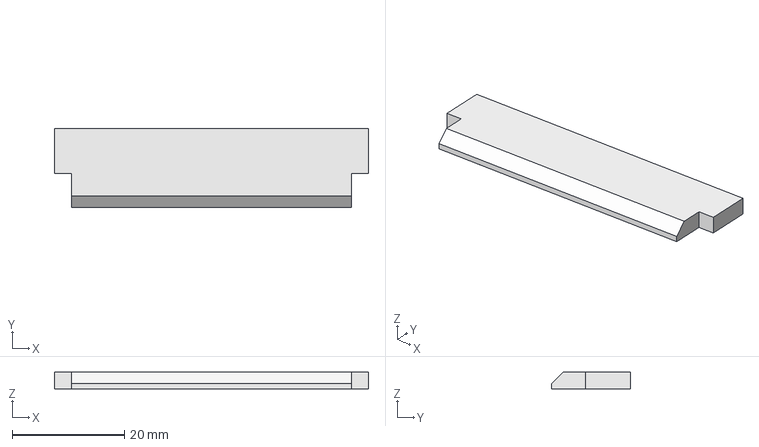
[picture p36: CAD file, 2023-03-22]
hardware/marquee/marquee.FCStd
56.0 x 14.0 x 3.00 mm

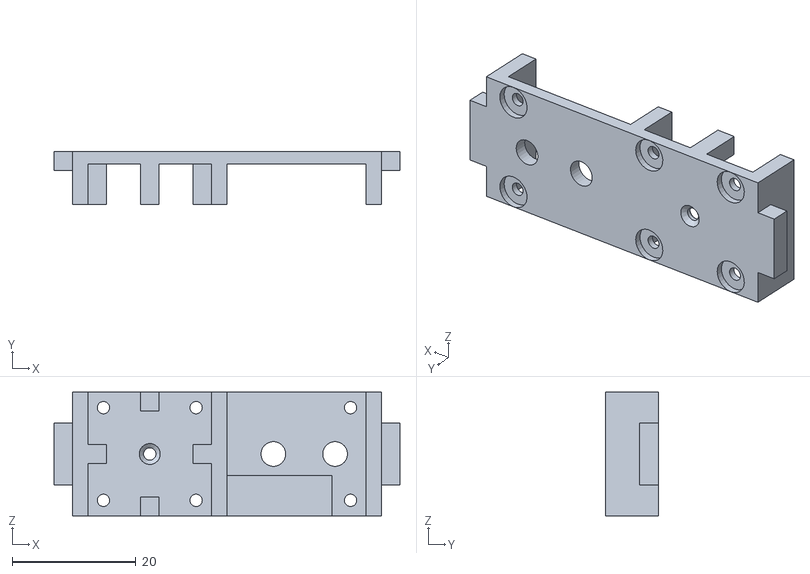
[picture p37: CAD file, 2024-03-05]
hardware/pcbs/controlboard_base.stl
56.0 x 8.50 x 20.0

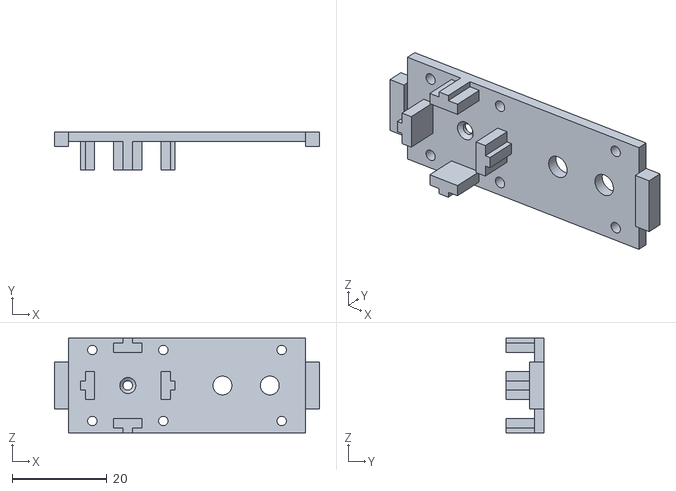
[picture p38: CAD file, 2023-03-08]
hardware/controlboard/galagino_controlboard-base.stl
56.0 x 8.00 x 20.0

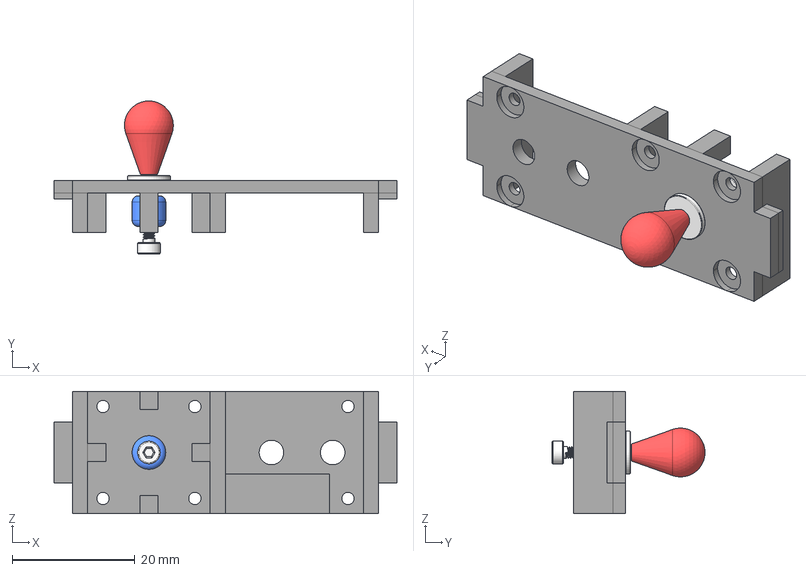
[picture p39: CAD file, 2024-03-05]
hardware/pcbs/controlboard.FCStd
56.0 x 25.0 x 20.0 mm
base
actuator
knob
screw
washer

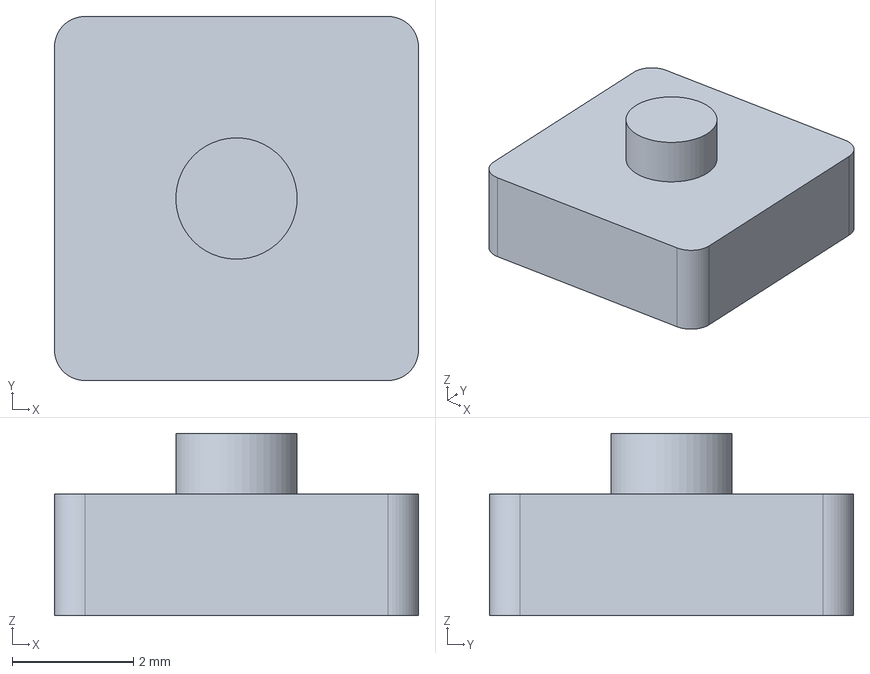
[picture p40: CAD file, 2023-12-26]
hardware/pcbs/btn_raiser.FCStd
6.00 x 6.00 x 3.00 mm

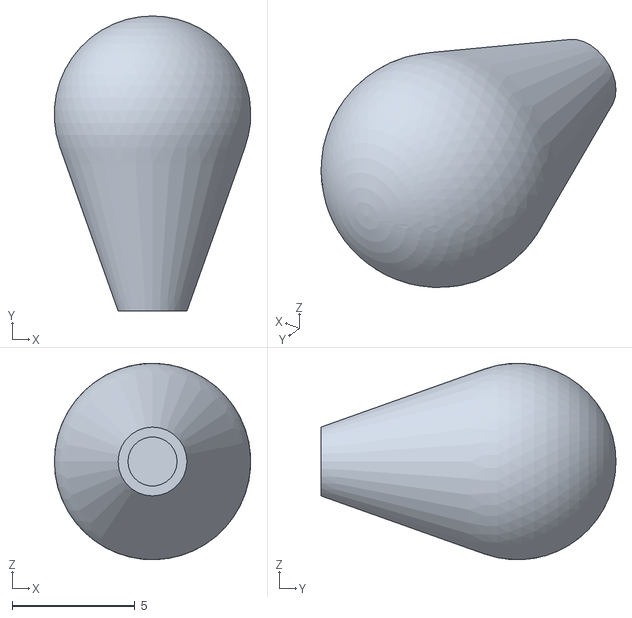
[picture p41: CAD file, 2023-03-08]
hardware/pcbs/controlboard_knob.stl
7.98 x 12.0 x 7.99

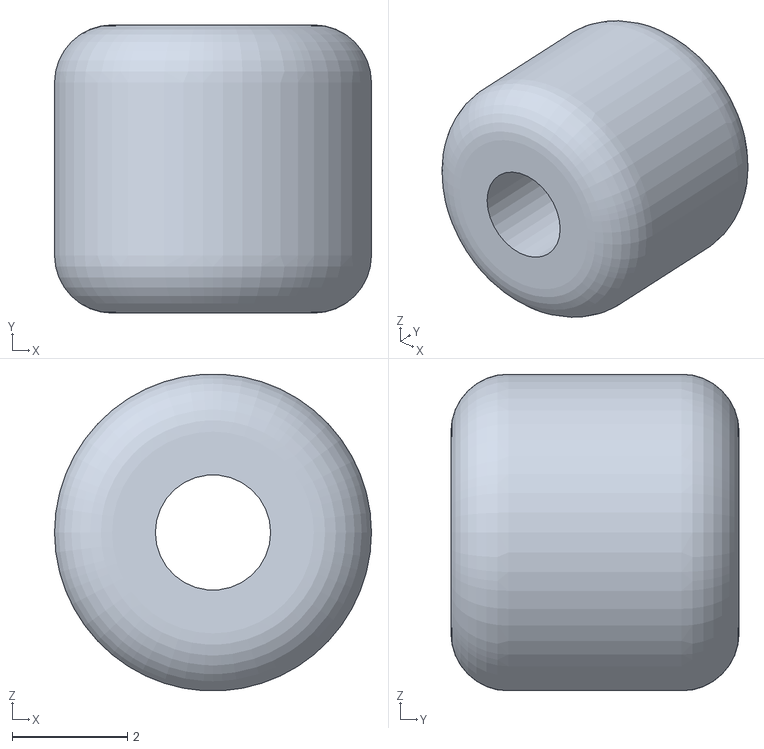
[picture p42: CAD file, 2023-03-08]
hardware/pcbs/controlboard_actuator.stl
5.50 x 5.00 x 5.49

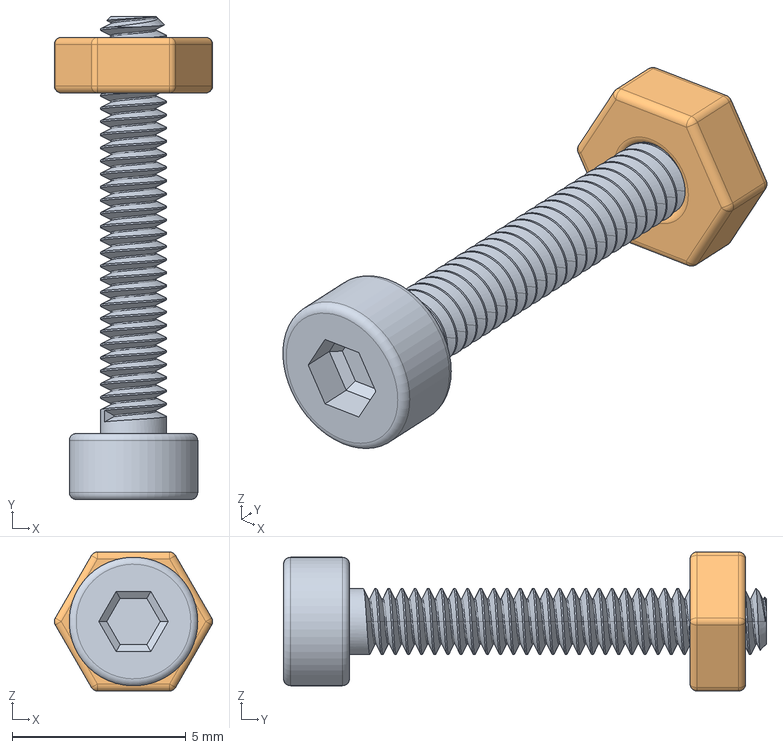
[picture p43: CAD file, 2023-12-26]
hardware/pcbs/screw_m2x12mm.FCStd
4.56 x 13.9 x 4.00 mm
screw
nut

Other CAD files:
hardware/coinbutton/coinbutton.stl
hardware/marquee/marquee.stl
hardware/pcbs/btn_raiser.stl

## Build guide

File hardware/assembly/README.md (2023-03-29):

# Electronics Assembly

If the hardware is to be placed inside a [tiny arcade cabinet](../cabinet), then it needs to be assembled more
compact than the breadboard allows.

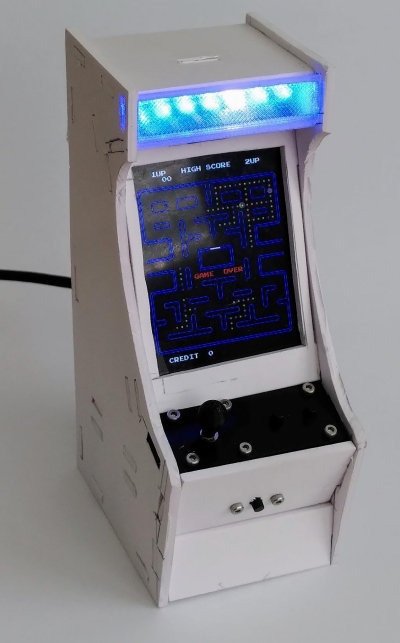
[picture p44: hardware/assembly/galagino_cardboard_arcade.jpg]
Cardboard arcade


[Video](https://youtube.com/shorts/vverV4NphlQ)

## Wiring 

Wiring takes place in a certain order and arrangement to be able to place the result nicely inside [the cabinet](../cabinet).

### Buttons

First the buttons have to be connected. These need to be wired
first as they are located right beside the ESP32 board and their wires
would interfere with the display wiring afterwards.

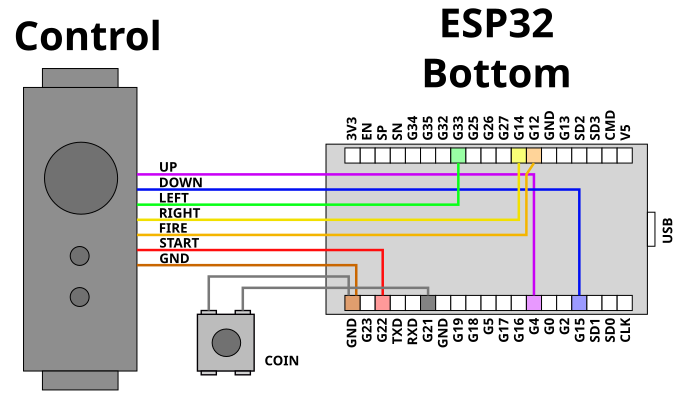
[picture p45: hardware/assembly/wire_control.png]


[PDF](wire_control.pdf)

This step connects the [controlboard](../controlboard/) and the
[coin button](../coinbutton) to the ESP32 board. You can solder the wires
directly to the ESP32 board or use female pin headers if you want to
be able to easily replace the ESP32.

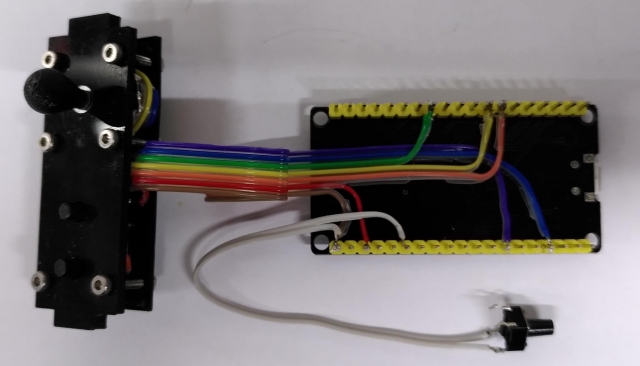
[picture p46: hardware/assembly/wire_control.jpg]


### Display

The next to wire up is the display.

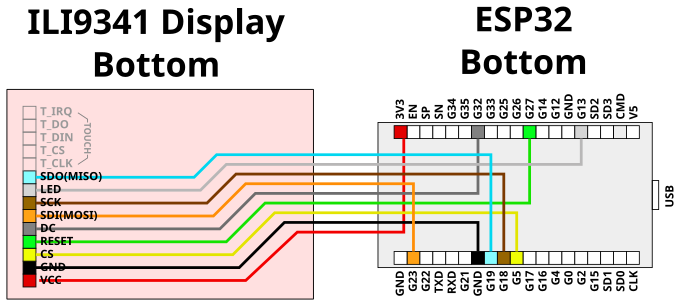
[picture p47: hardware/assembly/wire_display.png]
Display


[PDF](wire_display.pdf)

Arranging all wires in a neat way makes the soldering much easier
and robust and will later ease assembly.

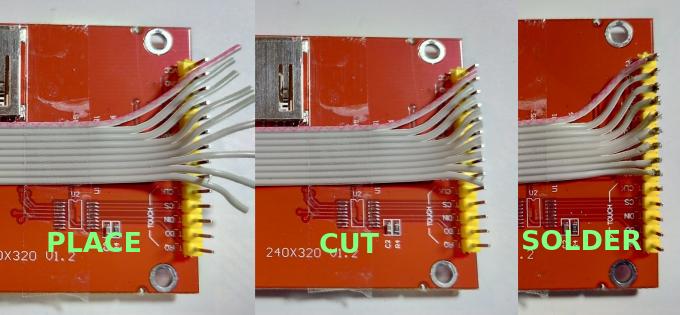
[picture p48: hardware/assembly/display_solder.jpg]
Solder


The displays connections are placed on top of the control wires so the
display can later be mounted directly above the controls.

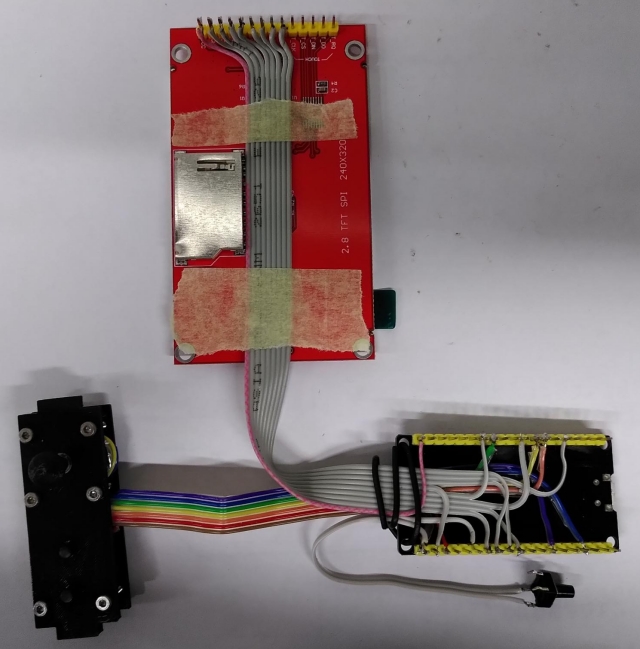
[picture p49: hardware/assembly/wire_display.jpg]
displays


The display is mounted 180° rotated compared to the breadboard setup.
This can be adjusted for in the [config.h](../../galagino/config.h) file.

The setup should be working at this point:

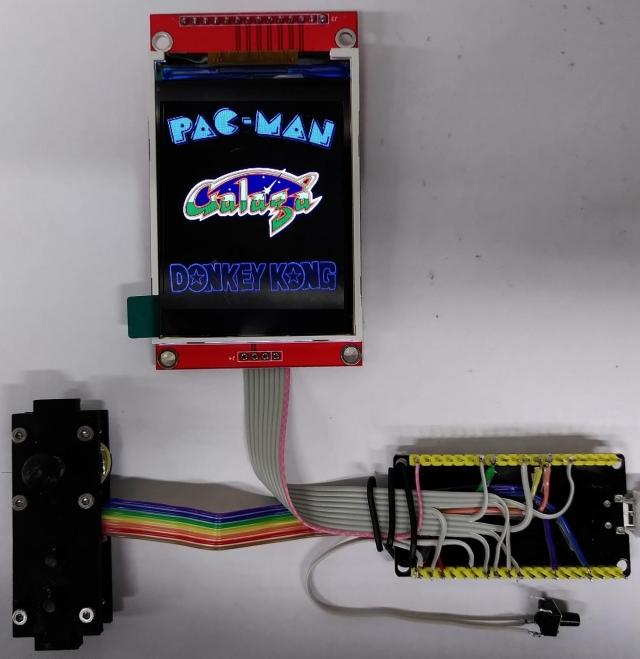
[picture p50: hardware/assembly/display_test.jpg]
test


Finally the speaker and the optional LED stripe are attached. Each of
them requires only three wires:

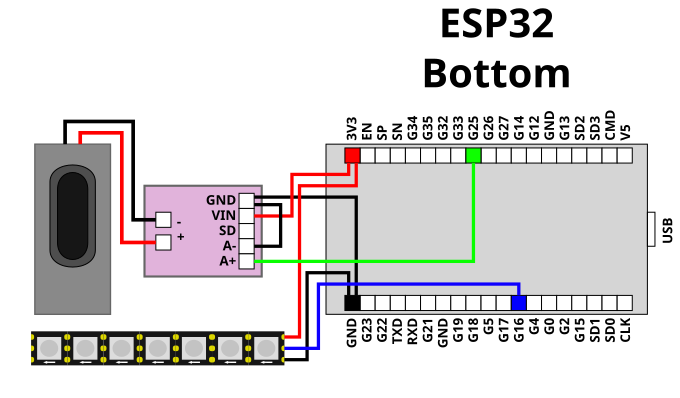
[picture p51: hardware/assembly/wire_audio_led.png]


[PDF](wire_audio_led.pdf)

The final assembly should then look like this:

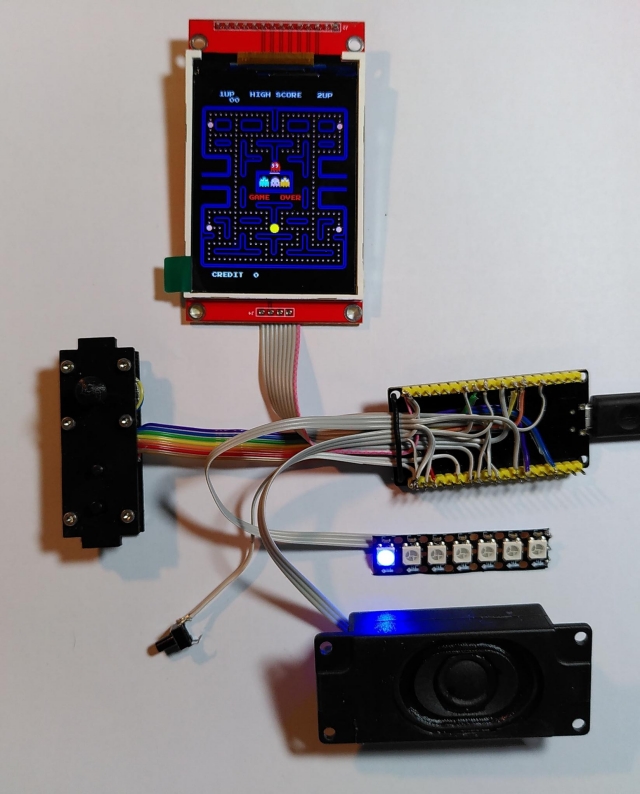
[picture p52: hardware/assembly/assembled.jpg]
assembled


The amplifier board cannot be seen as it's taped to the back of the speaker
compartment using double sided tape.

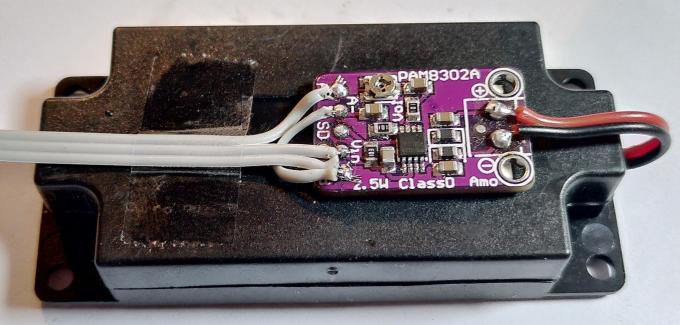
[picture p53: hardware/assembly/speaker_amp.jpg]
Speaker


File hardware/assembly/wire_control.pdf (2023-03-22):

# ESP32 Control

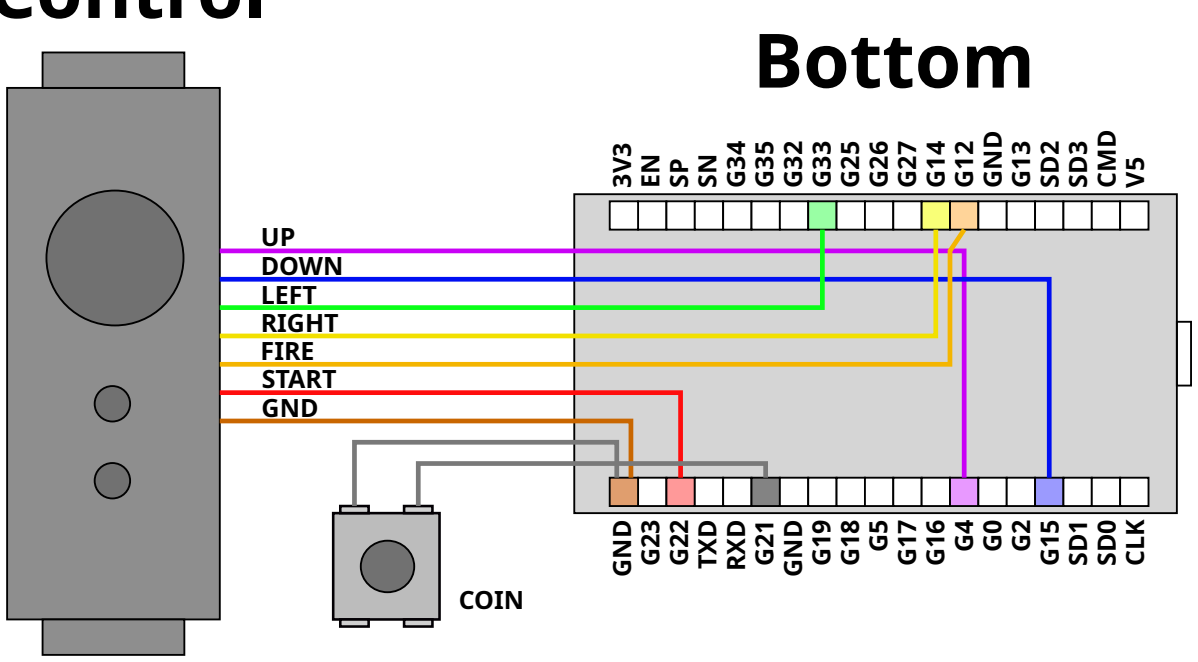
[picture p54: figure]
Bottom; GND G13 SD2; CMD; GND; G22 TXD RXD; G21 GND; CLK; UP DOWN LEFT RIGHT FIRE START GND; COIN

## USB

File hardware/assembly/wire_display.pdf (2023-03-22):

# ESP32 Bottom

# ILI9341 Display Bottom

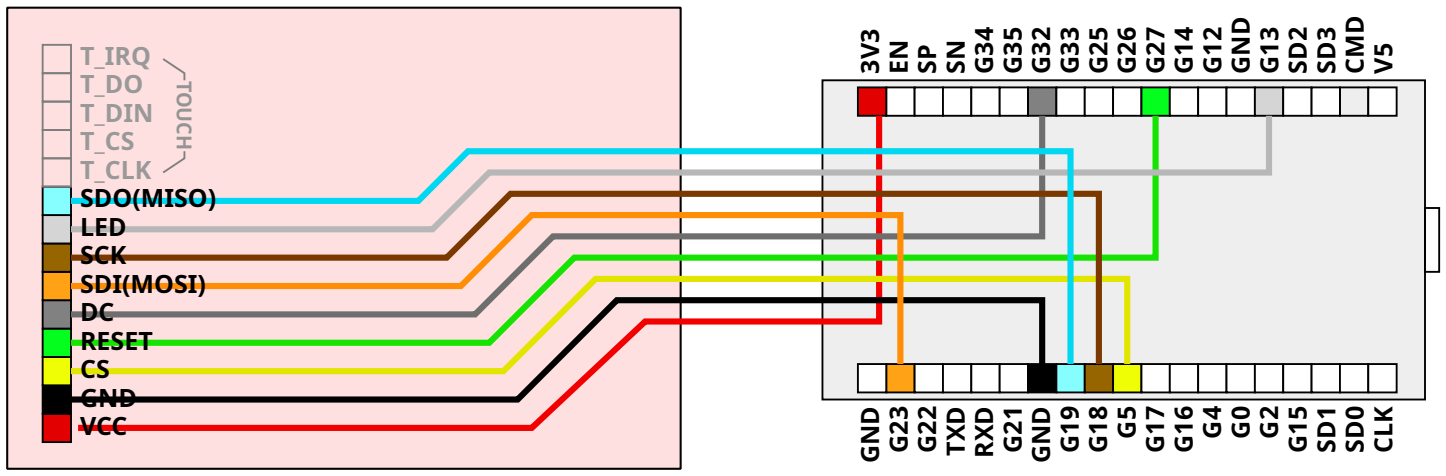
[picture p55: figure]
GND G13 SD2; CMD; GND; G22 TXD RXD; G21 GND; CLK; T_IRQ T_DO T_DIN T_CS T_CLK SDO(MISO) LED SCK SDI(MOSI) DC RESET CS GND VCC; TOUCH

## USB

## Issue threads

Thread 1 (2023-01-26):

Did you ever see these failures?

danjulio, 2023-01-26:
Hi Till,

First, thanks for this wonderful project.  I have ported it to my board with a WROVER and 320x480 pixel ILI9488 display.  It works but with a few failures I am wondering if you can shed some light on (for example you saw this during your development).

1. I get no sound.  Nothing coming out of the DAC pins (25 & 26) even when viewed with an oscilloscope.
2. The emulator (or at least parts of it) seem to freeze on occasion.
  - If I press COIN after it has displayed the attract screen for a while movement of the sprites stops and I can add no more coins but the starry background keeps moving.  However if I hold COIN down through the startup then I immediate get a coin and can others and can start the play.
  - After a game it freezes after displaying the statistics.  The statistics go away and the the entire game freezes (starry background freezes too).

I am compiling on Arduino 1.8.19 (Mac) with ESP Arduino package 2.0.6.  I downloaded my ROMs from https://wowroms.com/en/roms/mame-0.139u1/download-galaga-namco-rev.-b/3699.html.  All your python scripts seemed to work just fine on the Mac.  Board is https://github.com/danjulio/gCore.

  Changes I made include
  1. I display a background image instead of blanking the LCD as you can see to make use of the extra LCD real-estate (seems to work fine).
  2. I used different IO pins for the buttons (33, 34, 35, 36, 39) and used external 10k-ohm pull-ups (seems to work fine).
  3. I used the TFT_eSPI library to drive the LCD (80 MHz VSPI native pins).  Seems to work fine and I did  a little playing with your code to try out 60 Hz.  Seems to work - starry background scrolls a lot faster - but didn't get an actual FPS yet.

I realize it is really hard to debug someone else's setup but just curious if you had seen any of these issues or had a pointer where I might go debugging.

 Thanks, Dan

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

harbaum, 2023-01-26:
Great that you are having fun with it.

And no, I have not seen any of these issues. Actually my kids just yesterday stress tested the current version for over an hour with no complaints at all.

I would suggest that you go step-by-step from my hw setup to yours to see where things start to break. But I assume you already had your setup lying around. Interestingly your button layout matches the one required for Galaga. What was you board designed for?

One thing that comes to mind the the WROVER. Do you select a WROVER board in the Arduino IDE? If yes, the code may actually use the external RAM instead of the internal one. As the external RAM is much slower this may be related to your problems. Try to select a WROOM based board which should make the code just ignore the extra RAM of the WROVER.

I have done some major modifications in the meantime and in a few days I'll release a new version with options to include *PACMAN* and *Donkey Kong* as together with a game select screen. This is optional. If you prefer a bare Galaga you can still set it up as a single machine.

danjulio, 2023-01-26:
Thank you for your quick response!  I got it running.  And as we all know that kids are the perfect stress test for anything, I'm sure it's golden now :-)

1. You were right, it has to be compiled for WROOM.  Something must have been getting malloc'd in PSRAM.
2. I replaced your call to i2s_set_pin() with i2s_set_dac_mode(I2S_DAC_CHANNEL_BOTH_EN) to get audio working.  I also found that i2s_driver_install() starts the driver as well so technically the i2s_start() call is not needed.  The only thing I can think is that we're using different versions of the ESP32 Arduino package and Espressif changed something in between.

Thank you again.  I look forward to your updates.  I spent some time researching how the galaga console worked and how you implemented the emulation.  Don't understand it all but I think it is very cool.

Regards, Dan

harbaum, 2023-01-30:
> The only thing I can think is that we're using different versions of the ESP32 Arduino package and Espressif changed something in between.

I am running ESP32 board package 1.0.6 on a windows box as well as a linux box and it compiles with that.

danjulio, 2023-01-30:
It's all good!  I got it running.  And I see you're making progress with the other games.  Very cool.  Thanks again for helping me.

harbaum, 2023-01-31:
I changed to version 2.0.6 as well and lost the audio. Just replacing  i2s_set_pin() with i2s_set_dac_mode(I2S_DAC_CHANNEL_BOTH_EN) does not give me audio back.

harbaum, 2023-01-31:
It seems the magic is not calling ```i2s_set_dac_mode(I2S_DAC_CHANNEL_BOTH_EN)``` but removing the setting of ```.communication_format = (i2s_comm_format_t)I2S_COMM_FORMAT_I2S_MSB``` from ```i2s_config```.

danjulio, 2023-01-31:
Interesting.  And I have to apologize.  In fact I changed that too but forgot to mention it.  I saw there was an incorrect cast after looking at the driver code.  Here's my setup that's working.  I set ```.communication_format = I2S_COMM_FORMAT_STAND_MSB,```  without the cast, but as you found out, it isn't necessary.

```
// init audio
  // 24 kHz @ 16 bit = 48000 bytes/sec = 800 bytes per 60hz game frame =
  // 1600 bytes per 30hz screen update = ~177 bytes every four tile rows
  static const i2s_config_t i2s_config = {
    .mode = (i2s_mode_t)(I2S_MODE_MASTER | I2S_MODE_TX | I2S_MODE_DAC_BUILT_IN),
    .sample_rate = 24000,
    .bits_per_sample = I2S_BITS_PER_SAMPLE_16BIT,
#ifdef SND_DIFF
    .channel_format = I2S_CHANNEL_FMT_RIGHT_LEFT,
#else
    .channel_format = I2S_CHANNEL_FMT_ONLY_LEFT,
#endif
//    .communication_format = (i2s_comm_format_t)I2S_COMM_FORMAT_I2S_MSB,
    .communication_format = I2S_COMM_FORMAT_STAND_MSB,
    .intr_alloc_flags = 0,
    .dma_buf_count = 4,
    .dma_buf_len = 64,   // 64 samples
    .use_apll = false
  };

  snd_prepare();
  snd_render_buffer();
  i2s_driver_install(I2S_NUM_0, &i2s_config, 0, NULL);
  // use dac on default gpio25/26
//  i2s_set_pin(I2S_NUM_0, NULL);
  i2s_set_dac_mode(I2S_DAC_CHANNEL_BOTH_EN);
//  i2s_start(I2S_NUM_0);
```

harbaum, 2023-01-31:
I just checked in an updated version after I updated to 2.0.6 as well. This should now work for you as well.

harbaum, 2023-02-04:
FYI: The latest code runs the video at full 60Hz if SPI clock is configured to 80Mhz. This might also work with your display.

danjulio, 2023-02-04:
Thanks Till!  I gotta make a new button board now :-)

Closed 2023-01-30.

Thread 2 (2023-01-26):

80Hz SPI on ILI9341

gingerbeardman, 2023-01-26:
I read 80Hz SPI is possible on ILI9341:

https://www.esp32.com/viewtopic.php?t=6627

harbaum, 2023-01-27:
Some display do. But in general they don't. But there's imho no visible benefit, anyways. The video is very fluid at 30Hz.

gingerbeardman, 2023-01-27:
Appreciate your reply.

My goal would be the same refresh rate as the original arcade hardware. I'll keep looking!

harbaum, 2023-01-27:
The st7789 displays I have tested work fine at 80Mhz and one of my ili9143 also copes with that.

Just give it a try. You'll have to do some minor adjustments in the rest of the code as well to e.g. make sure that the code execution will still get 60 VBL interrupts per second to make the game run at the correct speed.

Also be aware that being able to write data at the full rate into the display controller doesn't guarantee that the display is actually refreshed at that rate. You'll probably need to study the data sheets of the display controllers in more detail to verify that these refresh those small screens at the desired rate.

However, why don't you just give it a try?

gingerbeardman, 2023-01-27:
Thanks again.

Oh, also, I added this to Hacker News and there's some discussion there: https://news.ycombinator.com/item?id=34539811

harbaum, 2023-01-27:
Regarding that discussion: Doing partial screen updates for Galaga is difficult as the starfield background basically affects the entire screen the whole time. That combined with the three z80 utilizes the ESP32 to ~90%. At least with my C code. Using assembly would sure relax things.

Pacman and Donkey Kong are a different thing. They are both single Z80 machines and the screen content is rather static. So yes, these run easily on the ESP32 and may even be possible with the ESP8266.

Closed 2023-02-04.

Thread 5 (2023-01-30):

I2S_MODE_DAC_BUILT_IN was not declared in void audio_init

famiclone6502, 2023-01-30:
I've been trying/failing to compile/verify the .ino while I am waiting for my ESP32 to arrive.

Right now I've got an error in void audio_init() that I2S_MODE_DAC_BUILT_IN was not declared. Do I need a specific version of the ESP32 libraries? Can you provide which versions you are using?

On another note, I saw that the readme is now missing the section for using the other .py scripts, which I was able to find to get past the tileaddr.h error. While it did not mention the game logo python script, I was able to figure out the usage and run that command too.

Thank you and I look forward to building this project!

harbaum, 2023-01-31:
Issues with I2S have also been reported in #1. I'll check that. I am using ESP32 board support 1.0.6 which comes from https://dl.espressif.com/dl/package_esp32_index.json . Where does 2.06 come from?

The main [README.md](README.md) now has links to the romconv and samples directory. These now have their own [romconv/README.md](romconv/README.md) [samples/README.md](samples/README.md). But I have added another sentence to the main README which points to these. This should be more obvious now.

harbaum, 2023-01-31:
It seems 2.0.6 comes from [here](https://docs.espressif.com/projects/arduino-esp32/en/latest/installing.html). I'll have a look at that.

harbaum, 2023-01-31:
You need the latest 2.0.6 ESP32 board support as described e.g. here: https://docs.espressif.com/projects/arduino-esp32/en/latest/installing.html

famiclone6502, 2023-01-31:
I was able to downgrade to 1.0.6 and successfully verify the build. I don't have the board yet so I can't check if everything else went correctly. Thanks for updating the readme and letting me know which version to try. I recommend adding which libraries have been tested with the project to the readme, as even future updates could break compatibility further. Are you planning on updating it to work with the current latest version?

harbaum, 2023-01-31:
I just updated it to work with 2.0.6 which is the latest. I actually haven't tested if this still works with 1.0.6 but I don't expect it to work. So you might have to update to 2.0.6

famiclone6502, 2023-01-31:
Thank you for clarifying, I was able to start from scratch and successfully compile using the updated readme instructions and latest versions of your project with the 2.0.6 esp32 library.

I forgot to mention another dependency you may want to add to the readme, which is using "pip3 install imageio" before converting the logos with Python.

Thanks again!

famiclone6502, 2023-02-02:
Thank you for updating the documentation. I was able to complete my project. (The original screen was broken and the board was corroded).
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

The only other documentation issue I had was figuring out the buttons, which is listed in the code but unlabeled on the breadboard schematic. I did end up flipping the screen, so that feature was a perfect inclusion.

But you can close this issue, now. Thank you for making this! It was a very fun and easy project to build! I look forward to any future updates!

Closed 2023-02-02.

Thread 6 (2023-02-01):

Master attract mode

harbaum, 2023-02-01:
All three games come with an "attract mode" where the game runs short game sequences to attract paying users. With the galagino menu these don't show up until one machine is selected in the menu.

Add a timer to implement a "master attract mode" where the esp32 randomly starts machines after some time into attract mode while it sits idle in the menu. This "master attract mode" ends once the user presses a button.

Closed 2023-06-17.

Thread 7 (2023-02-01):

Master reset

harbaum, 2023-02-01:
Currently the only way to "return" to the main menu is to hard reset the esp32. This requires to have the reset pin exposed.

Implement a "master reset" e.g. via pressing "coin" and "start" simultaneously.

harbaum, 2023-02-12:
Implemented by pressing "coin" for > 1 sec. If no coin button is present, then the start button will do.

Closed 2023-02-12.

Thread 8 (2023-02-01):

Combine coin and start button function

harbaum, 2023-02-01:
On a real arcade machine inserting a coin and starting a game are two different things. On the emulator inserting a virtual coin and starting always happen in a sequence.

Implement a automatic that is triggered by the start button and automatically inserts a coin before. The coin button can then be totally omitted.

May collide with #7

famiclone6502, 2023-02-03:
I agree, but also would also like to combine the action button, too. For my project, I used a second joystick for these buttons with left being coin, right as start, and down is action (jump/fire).  It's a little awkward, so I would prefer to remove this joystick and just replace it with a single button if it's feasible.

harbaum, 2023-02-04:
How would this work? Combining coin and start works as the user never uses these buttons for other purposes. But how would you wire the fire button into this? Mapping one single button onto "fire" and "coin" and "start" would cause you to constantly insert coins while playing and hitting fire.

famiclone6502, 2023-02-04:
Sorry, I meant more of a freeplay mode where you only need one button to start the game, and use the same button for action.

harbaum, 2023-02-04:
Freeplay can already be enabled in the config. That reminds me that I have only implemented that for galaga and Pacman. Does the Donkey Kong allow for Freeplay as well? I need to check that.

However, you can enable this and this should remove the need for the coin button. Then you can simply wire fire and start to one single button. That should already allow you to do a single button setup.

famiclone6502, 2023-02-06:
I do think this is an interesting way to add freeplay to combine the buttons, but like you said it still adds coins while playing. This is more scalable than finding patches for each individual game (if you plan on adding more), but if any credits remain after a game, the attract mode won't work.

Patches are out there to give these games better freeplay without disabling the attract mode. I tried one for Pacman (from Cam's Pacman page) that doesn't add credits if you press a button (and says "FREEPLAY"), but randomly it seems to get halfway stuck on the attract screen when starting. Another good page for patches covering the games supported so far would be the ones on SouzaOnline, like the 4-in-1 that lets you choose fast/slow along with adding Ms Pacman. But, I wasn't sure how to incorporate these since they didn't have normal ROM names/sizes.  There's also a freeplay patch for Donkey Kong there, too.

I think most true freeplay patches would allow a single button for action and starting without hearing credits being added, but it's understandable if this does not align with your goals for this project.

Closed 2023-02-05.

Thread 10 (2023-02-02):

Use DMA to transfer data to display

harbaum, 2023-02-02:
The pure data transfer to the display has a theoretical limit of 224*288*16/40000000 = 25,8 ms per frame. In the current implementation the transfer is blocking and all video and audio calculations need to take place in the remaining 7,5ms per 30Hz display frame.

Using DMA for the data transfer would allow to compute video and audio data while video data is being transferred. This would significantly relax the load on the esp32 core responsible for audio and video.

harbaum, 2023-02-04:
Done

Closed 2023-02-04.

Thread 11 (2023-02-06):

Emulate Donkey Kong audio CPU

harbaum, 2023-02-06:
Currently Donkey Kong uses sampled audio and it's an ugly endeavor to find/create/convert matching sound bits . But on the real arcade machine most of the audio is actually generated by a program running in a intel 8049 compatible CPU.

Emulating the audio CPU itself would make Donkey Kong audio be "correct". At least for those sounds generated by the audio CPU. This means we have to implement a 8048 emulator as none matching this project seem to exist.

harbaum, 2023-02-09:
The 8048 derived audio CPU in donkey kong runs at twice the clock as the main z80 cpu. The single main z80 of donkey kong is no problem at all for the esp32. The combination of the main z80 @ 3Mhz together with the 8048 @ 6Mhz is definitely more challenging.

harbaum, 2023-02-11:
Done

Closed 2023-02-11.

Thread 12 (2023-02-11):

driver/spi_master.h

sandorkrisz, 2023-02-11:
Please upload the sound driver library.

galagino:12:10: fatal error: driver/i2s.h: No such file or directory
 #include "driver/i2s.h"
          ^~~~~~~~~~~~~~
compilation terminated.
exit status 1

In file included from D:\galagino\galagino-main\galagino\galagino.ino:13:0:
video.h:7:10: fatal error: driver/spi_master.h: No such file or directory
 #include <driver/spi_master.h>
          ^~~~~~~~~~~~~~~~~~~~~
compilation terminated.
exit status 1
driver/spi_master.h: No such file or directory

harbaum, 2023-02-11:
These files are part of the ESP32 board package. What board do you have selected? And what ESP32 board support do you have installed?

Closed 2023-03-08.

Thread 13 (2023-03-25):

missing tileaddr.h: No such file

C64fan, 2023-03-25:
Hi,
great project, respect.
I cannot find tileaddr.h , where to get this file ?

harbaum, 2023-03-25:
You generate it together with many other files using the python scripts in  the romconv directory.

There's a readme that should give you all the details.

C64fan, 2023-03-25:
My bad,
Ordered hardware and will build this project.
Indeed very detailed manual, very appreciated.

harbaum, 2023-03-25:
This is still a work in progress and the next will be a laser cut plywood case.

And the instructions will get a major update then to include the mechanical, electrical and programming related tasks in one consistent document.

Do you plan to put everthing into a case?

Closed 2023-03-25.

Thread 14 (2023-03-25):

galaga_starseed.h

C64fan, 2023-03-25:
Hi,
progressing on the project.
All the python scripts succeeded on the roms but with compile of the project the galaga_starseed.h is throwing struct errors.
I read the how-to, do i fail with this file ?
Thanks in advance

harbaum, 2023-03-25:
What are those errors?

C64fan, 2023-03-25:
<!--
/* Font Definitions */
@font-face
	{font-family:"Cambria Math";
	panose-1:2 4 5 3 5 4 6 3 2 4;}
@font-face
	{font-family:Calibri;
	panose-1:2 15 5 2 2 2 4 3 2 4;}
/* Style Definitions */
p.MsoNormal, li.MsoNormal, div.MsoNormal
	{margin:0cm;
	margin-bottom:.0001pt;
	font-size:11.0pt;
	font-family:"Calibri",sans-serif;}
a:link, span.MsoHyperlink
	{mso-style-priority:99;
	color:blue;
	text-decoration:underline;}
.MsoChpDefault
	{mso-style-type:export-only;}
@page WordSection1
	{size:612.0pt 792.0pt;
	margin:70.85pt 70.85pt 70.85pt 70.85pt;}
div.WordSection1
	{page:WordSection1;}
-->Hi Till,  In file galagino\galagino.ino:41:galagino\galaga_starseed.h:1:1: error: expected primary-expression before 'struct' struct galaga_star { unsigned char x, y; unsigned short col; }; ^~~~~~galagino\galaga_starseed.h:1:1: error: expected '}' before 'struct'In file galagino\galagino.ino:40:galagino\galaga_sample_boom.h:1:44: note: to match this '{' const unsigned char galaga_sample_boom[] = {                                            ^In file galagino\galagino.ino:41:galagino\galaga_starseed.h:2:26: error: elements of array 'const galaga_star galaga_star_set [][63]' have incomplete type const struct galaga_star galaga_star_set[][63] = {                          ^~~~~~~~~~~~~~~galagino\galaga_starseed.h:2:26: error: storage size of 'galaga_star_set' isn't knowngalagino\galagino.ino: In function 'void render_stars_set(short int, const galaga_star*)':galagino\galagino.ino:218:38: error: invalid use of incomplete type 'struct galaga_star'     const struct galaga_star *s = set+star_cntr;                                   ~~~^~~~~~~~~~In file galagino\galagino.ino:41:galagino\galaga_starseed.h:2:14: note: forward declaration of 'struct galaga_star' const struct galaga_star galaga_star_set[][63] = {              ^~~~~~~~~~~\galagino.ino:220:32: error: invalid use of incomplete type 'const struct galaga_star'     unsigned short x = (244 - s->x) & 0xff;                                ^~In file galagino\galagino.ino:41:galagino\galaga_starseed.h:2:14: note: forward declaration of 'struct galaga_star' const struct galaga_star galaga_star_set[][63] = {              ^~~~~~~~~~~galagino\galagino.ino:221:27: error: invalid use of incomplete type 'const struct galaga_star'     unsigned short y = ((s->y + stars_scroll_y) & 0xff) + 16 - row * 8;                           ^~In file galagino\galagino.ino:41:galagino\galaga_starseed.h:2:14: note: forward declaration of 'struct galaga_star' const struct galaga_star galaga_star_set[][63] = {              ^~~~~~~~~~~galagino\galagino.ino:224:34: error: invalid use of incomplete type 'const struct galaga_star'       frame_buffer[224*y + x] = s->col;                                  ^~In file galagino\galagino.ino:41:galagino\galaga_starseed.h:2:14: note: forward declaration of 'struct galaga_star' const struct galaga_star galaga_star_set[][63] = {              ^~~~~~~~~~~ Compilation error: expected primary-expression before 'struct' A snip of the file  Thank you for your help and time, really nice project. GreetsC64fan Van: Till HarbaumVerzonden: zaterdag 25 maart 2023 21:21Aan: harbaum/galaginoCC: C64fan; AuthorOnderwerp: Re: [harbaum/galagino] galaga_starseed.h (Issue #14) What are those errors? 

C64fan, 2023-03-26:
Hi,
I will close this question to not "spoil" this great project, really great effort.
Question is still open, i will wait for your answer or tip to solve the scruct error.
It can be related to Arduino Ide, or library or used setting only galaga in config.
Thank you Till for this nice project.
C64fan

harbaum, 2023-03-26:
I just did a build from scratch and it worked as it should. So there's something different in your setup.

My assumption is that one of the files was not created properly. It seems the first line if `galaga_starseed.h` is not parsed properly and thus the following second line in `galaga_starseed` fails.

My guess is that the file `galaga_sample_boom.h` is broken as it's included right before `galaga_starseed.h` . Can you have a look at that file? It shouls start with `const unsigned char galaga_sample_boom[] = {` and end with `};` in the last line.

BTW: Where and how did you run the python scripts? Under Linux or Windows?

If everything else fails, please zip your entire galagino directory containing the sketch and send it to me via email, so i can have a look and try to figure out which file differs and why.

C64fan, 2023-03-26:
<!--
/* Font Definitions */
@font-face
	{font-family:"Cambria Math";
	panose-1:2 4 5 3 5 4 6 3 2 4;}
@font-face
	{font-family:Calibri;
	panose-1:2 15 5 2 2 2 4 3 2 4;}
/* Style Definitions */
p.MsoNormal, li.MsoNormal, div.MsoNormal
	{margin:0cm;
	margin-bottom:.0001pt;
	font-size:11.0pt;
	font-family:"Calibri",sans-serif;}
a:link, span.MsoHyperlink
	{mso-style-priority:99;
	color:#0563C1;
	text-decoration:underline;}
.MsoChpDefault
	{mso-style-type:export-only;}
@page WordSection1
	{size:612.0pt 792.0pt;
	margin:70.85pt 70.85pt 70.85pt 70.85pt;}
div.WordSection1
	{page:WordSection1;}
-->Hi Till, Thank you, i have succeeded.Rebuild whole sketch and run the scripts 2nd time and it worked, the sampe_boom was indeed the culprit. I ordered a LiliGo T4 esp with 2.2 inch display for this project, it will be in a arcade casing, like Atari mini cabinet. On my YouTube channel I have some of my little projects, Mame Arcade cabinet with leds in the buttons.LiliGo Esp display with clock feed by ntp over wifi and ghost and pacman sprite running on background.Video and shorts ,  ***@***.*** I am interested in running 6502, z80 and 8088 games running natively in emulators, like, https://paoloseverini.wordpress.com/2016/02/13/galaga-an-arcade-machine-emulator-for-windows-and-html5/ and https://github.com/djyt/cannonball/wiki Thanks for this wonderfull project, a masterpiece. C64Fan

C64fan, 2023-03-31:
Hi Till,
Little progress, the project compliles but the display stays dark/gray.
Are you happy with sharing your TFT_eSPI User_Setup.h and User_Setup_Select.h config files ?
Greets,

harbaum, 2023-03-31:
I am not using any TFT library and thus no config files like that.

If you apply power and have the LED pin connected correctly then the ili9341 based display will light up bright white. If you have VCC (3.3V), GND and LED connected correctly then the screen should be white.

If that doesn't work and you are using a different setup than mine then you need to figure out how to configure Galagino for that specific board. You need to control the Backlight, drive the displays reset line correctly and finally setup the correct SPI pins.

I don't own one of the boards you use and can't easily help you with that.

C64fan, 2023-04-05:
Hi Till,
your answer was magic, many thanks.
Managed to resolve the pinning, all working ok.
#define TFT_CS  27, #define TFT_DC  32, #define TFT_RST 5, #define TFT_BL  4 for LilyGO TTGO T4 V1.3 ESP32.

harbaum, 2023-04-05:
Great. How about audio and the controls? How did you solve that?

I'll add your findings to the repository somehow so other TTGO T4 users can find tem.

C64fan, 2023-04-07:
Hi Till,
making the cabinet out of thin wood with smd audio amplifier, it will be only attraction mode in a pacman collection.
I tested the new attraction mode, splashscreen Pacman/Galaga  was ok, but the games give disturbed video on my Liligo T4.
The old project files function ok for the display.  (noticed the display rotation was changed in the new config file)
I will follow the progress.
Greets,

C64fan, 2023-04-07:
Pinned it down to the led routine, pin 16 on Liligo T4 needs to be disabled.
Master attrack only shows Pacman and splashscreen, not Galaga in next sequence.

C64fan, 2023-04-08:
Hi Till,
the define MASTER_ATTRACT_GAME_TIMEOUT  works fine for pacman, but not for galaga.
With define MASTER_ATTRACT_GAME_TIMEOUT  95000 , pacman is indeed 95 secondes but galaga only 37 seconds.
I will sent a picture when the mini cabinet is ready, will take some weeks to finish.

harbaum, 2023-04-08:
The game timeout part is not finished yet. This needs some major changes as the current solution of resetting the ESP32 in order to return to the main menu causes some crackling noise which I'd like to avoid if the system is supposed to be sitting quietly in master attract mode without bothering anyone.

Closed 2023-03-26.

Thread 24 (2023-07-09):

redefinition of 'OpZ80_INL'

jf1452, 2023-07-09:
Apologies, I seem to be finding a few today.

When converting the galagino.ino into VSCode, then trying to compile, I get the message:

redefinition of 'OpZ80_INL'

Looking at the code, it's defined in emulation.h:

static inline byte OpZ80_INL(register word Addr) {
#ifndef SINGLE_MACHINE
  static const unsigned char *rom_table[][3] = {
    { NONE, NONE, NONE },
#define ROM_ENDL ,
#else
  static const unsigned char *rom_table[3] =
#define ROM_ENDL ;
#endif
#ifdef ENABLE_PACMAN
    { pacman_rom, NONE, NONE } ROM_ENDL
#endif
#ifdef ENABLE_GALAGA
    { galaga_rom_cpu1, galaga_rom_cpu2, galaga_rom_cpu3 } ROM_ENDL
#endif
#ifdef ENABLE_DKONG
    { dkong_rom_cpu1, NONE, NONE } ROM_ENDL
#endif
#ifdef ENABLE_FROGGER
    { frogger_rom_cpu1, frogger_rom_cpu2, NONE } ROM_ENDL
#endif
#ifdef ENABLE_DIGDUG
    { digdug_rom_cpu1, digdug_rom_cpu2, digdug_rom_cpu3 } ROM_ENDL
#endif
#ifndef SINGLE_MACHINE
  };
  return rom_table[machine][current_cpu][Addr];
#else
  return rom_table[current_cpu][Addr];
#endif
}

and in z80.h:

static inline byte OpZ80_INL(register word Addr) {
#ifdef ENABLE_PACMAN
PACMAN_BEGIN
    return pacman_rom[Addr];
PACMAN_END
#endif

#ifdef ENABLE_GALAGA
GALAGA_BEGIN
    if(current_cpu == 1)       return galaga_rom_cpu2[Addr];
    else if(current_cpu == 2)  return galaga_rom_cpu3[Addr];
    return galaga_rom_cpu1[Addr];
GALAGA_END
#endif

#ifdef ENABLE_DKONG
DKONG_BEGIN
    return dkong_rom_cpu1[Addr];
DKONG_END
#endif

#ifdef ENABLE_FROGGER
FROGGER_BEGIN
   if(current_cpu == 0) return frogger_rom_cpu1[Addr];
   else                 return frogger_rom_cpu2[Addr];
FROGGER_END
#endif
}

If I delete the version in z80.h (because it seems the less complete version, all games run except DigDug which starts playing and digs halfway through the screen, then crashes.

harbaum, 2023-07-09:
Please re-run the z80 patch python script. If this shows up in two places then you probably updated your source tree from an older version but did not run these python scripts again.

I also encountered the digdug lockup during development. These were performance issues but they have been addressed.

Please make sure you have all files updated.

Did you try the using the Arduino IDE? If the problems only show up with Vscode, you may need to figure out the differences like e.g.compiler options or the like.

jf1452, 2023-07-09:
Thank you, running the scripts again fixed the duplicated definition... My bad!

DigDug still crashes just before Player 1 start. I installed Arduino 2.1.1 and can't get it to compile at all...

C:\Software\Arcade\galagino-main\galagino\video.cpp:52:1: sorry, unimplemented: non-trivial designated initializers not supported
 };
 ^
C:\Software\Arcade\galagino-main\galagino\video.cpp:52:1: sorry, unimplemented: non-trivial designated initializers not supported
C:\Software\Arcade\galagino-main\galagino\video.cpp: In constructor 'Video::Video()':
C:\Software\Arcade\galagino-main\galagino\video.cpp:127:43: error: 'SPI_DMA_CH_AUTO' was not declared in this scope
   spi_bus_initialize(VSPI_HOST, &bus_cfg, SPI_DMA_CH_AUTO);
                                           ^
In file included from c:\Users\jonfu\Documents\Arduino\libraries\FastLED\src/FastLED.h:75:0,
                 from C:\Software\Arcade\galagino-main\galagino\leds.h:8,
                 from C:\Software\Arcade\galagino-main\galagino\galagino.ino:14:
c:\Users\jonfu\Documents\Arduino\libraries\FastLED\src/fastspi.h:157:23: note: #pragma message: No hardware SPI pins defined.  All SPI access will default to bitbanged output
 #      pragma message "No hardware SPI pins defined.  All SPI access will default to bitbanged output"
                       ^
C:\Software\Arcade\galagino-main\galagino\galagino.ino: In function 'void dkong_trigger_sound(char)':
C:\Software\Arcade\galagino-main\galagino\galagino.ino:488:23: error: no matching function for call to 'random()'
     char rnd = random() % 3;
                       ^
In file included from C:\Users\jonfu\AppData\Local\Temp\arduino\sketches\8B6F6113B00CD58F3E8954C7FE93A26A\sketch\galagino.ino.cpp:1:0:
C:\Users\jonfu\AppData\Local\Arduino15\packages\esp32\hardware\esp32\1.0.6\cores\esp32/Arduino.h:121:6: note: candidate: long int random(long int, long int)
 long random(long, long);
      ^
C:\Users\jonfu\AppData\Local\Arduino15\packages\esp32\hardware\esp32\1.0.6\cores\esp32/Arduino.h:121:6: note:   candidate expects 2 arguments, 0 provided
In file included from C:\Users\jonfu\AppData\Local\Temp\arduino\sketches\8B6F6113B00CD58F3E8954C7FE93A26A\sketch\galagino.ino.cpp:1:0:
C:\Users\jonfu\AppData\Local\Arduino15\packages\esp32\hardware\esp32\1.0.6\cores\esp32/Arduino.h:179:6: note: candidate: long int random(long int)
 long random(long);
      ^
C:\Users\jonfu\AppData\Local\Arduino15\packages\esp32\hardware\esp32\1.0.6\cores\esp32/Arduino.h:179:6: note:   candidate expects 1 argument, 0 provided
C:\Software\Arcade\galagino-main\galagino\galagino.ino: In function 'void audio_init()':
C:\Software\Arcade\galagino-main\galagino\galagino.ino:551:3: sorry, unimplemented: non-trivial designated initializers not supported
   };
   ^
C:\Software\Arcade\galagino-main\galagino\galagino.ino:551:3: sorry, unimplemented: non-trivial designated initializers not supported
C:\Software\Arcade\galagino-main\galagino\galagino.ino:551:3: sorry, unimplemented: non-trivial designated initializers not supported
C:\Software\Arcade\galagino-main\galagino\galagino.ino:551:3: sorry, unimplemented: non-trivial designated initializers not supported

exit status 1

Compilation error: 'SPI_DMA_CH_AUTO' was not declared in this scope

Should I be using the legacy Arduino?

harbaum, 2023-07-09:
I  just checked and everything still works fine for me.

Are you sure you selected the correct esp32-dev board?

jf1452, 2023-07-10:
Thank you, your last message pointed me in the direction which allowed me to ask Google the right questions.

It turned out that Additional Boards Manager URLs picked up my config from when I last used it (years ago before I switched to VSCode). The Espressif links have been updated since then and now needs to point to https://espressif.github.io/arduino-esp32/package_esp32_index.json That done, it now compiles.

And the cherry on the top is that DigDug now runs. What the difference is, that will take a lot more investigation.

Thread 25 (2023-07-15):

Feature request

snakebyte69, 2023-07-15:
Versions that run on
- Agon Light
https://www.olimex.com/Products/Retro-Computers/AgonLight2/open-source-hardware
- ESP32-SBC-fabGL
https://www.olimex.com/Products/Retro-Computers/AgonLight2/open-source-hardware
- TTGO VGA
https://www.tindie.com/products/lilygo/lilygo-ttgo-vga-v14-controller/

harbaum, 2023-07-15:
These are all devices with VGA out. I don't think a ESP32 can handle VGA _and_ Galagino at the time.

snakebyte69, 2023-07-16:
Check out our Discord we have a channel for Galagino
https://discord.gg/yZXPAF56kX
I will send you each of those ESP32 SBCs

harbaum, 2023-07-16:
As I said, I am not sure the ESP32 can handle VGA and all the emulation stuff at the same time. So I am not even sure it's possible at all.

Thanks for the offer, but there's no need to send me anything. If I decide to give it a go, I'll just order some board that seems to fit the bill.

snakebyte69, 2023-07-17:
It wouldn't have to be full VGA resolution

snakebyte69, 2023-07-17:
https://github.com/rpsubc8/ESP32TinyPAC/tree/main/esp32/TinyPACttgovga32
This is a MAME PacMan port with VGA 6 bit colour

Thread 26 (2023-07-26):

Watchdog reboots DigDug and Galaga

KlausMu, 2023-07-26:
In "Dig Dug" and "Galaga" I get after some seconds:

`E (45312) task_wdt: Task watchdog got triggered. The following tasks did not reset the watchdog in time:
E (45312) task_wdt:  - IDLE (CPU 0)
E (45312) task_wdt: Tasks currently running:
E (45312) task_wdt: CPU 0: emulation task
E (45312) task_wdt: CPU 1: IDLE
E (45312) task_wdt: Aborting.

abort() was called at PC 0x400f1021 on core 0
Backtrace:0x40083aed:0x3ffbe8ec |<-CORRUPTED
ELF file SHA256: 0000000000000000
Rebooting...
`
The other games work great.

harbaum, 2023-07-26:
Works here. Which version of the Arduino IDE do you use? Which version of the ESP32 board support? Are you using a ESP32 with or without PSRAM?

KlausMu, 2023-07-26:
I gave PlatformIO in Visual Studio Code a try. To me PlatformIO has a lot of advantages compared to the ArduinoIDE.
But as advised I also tried with the ArduinoIDE. Here all the games work (including DigDug and Galaga) - but unfortunately without sound.

Here the setup:

ArduinoIDE:
  IDE version 2.1.1
  ESP32 board support: esp32 [v 2.0.11]
  selected board: ESP32 dev board

PlatformIO:
  PlatformIO version 6.1.9
  PLATFORM: Espressif 32 (5.2.0) > Espressif ESP32 Dev Module
    framework-arduinoespressif32 @ 3.20005.220925 (2.0.5)
  board = esp32dev

ESP32 hardware:
HARDWARE: ESP32 240MHz, 320KB RAM, 4MB Flash

harbaum, 2023-07-26:
It seems platformio produces slower code. Galagino really needs all performance for Galaga and Digdug. You might want to compare the compiler optimization settings both setups use.

With platformio you had sound? At least on the games that were working?

KlausMu, 2023-07-26:
Yes, with PlatformIO I had sound.

I will try to compare the compiler settings and see if I can finetune them. I will come back here and let you know if I was successfull.

KlausMu, 2023-07-27:
Ok, it really seems to be related to the ESP32 arduino version.
First I used v2.0.5 in PlatformIO. But there was an update available to version 2.0.9. With that it is running better, Galaga is running at least for lets say 10 seconds, but then it crashes again.
The arduino IDE is using v 2.0.11

I also tried some additional build flags seen in the Arduino IDE when having verbose output, but with no effect:
    -DHAVE_CONFIG_H
    -DUNITY_INCLUDE_CONFIG_H
    -DWITH_POSIX
    -D_GNU_SOURCE
    -DESP_PLATFORM
    -D_POSIX_READER_WRITER_LOCKS

I would use the Arduino IDE for compiling and flashing if I had sound there ...

harbaum, 2023-07-27:
I had the esp32 support version 2.0.6 installed in the Arduino IDE. I have now upgraded to 2.0.11 and indeed I only get what sounds like static noise and no game sound at all. Unfortunately, the 2.0.6 is not available, anymore. So I need to figure out what's the problem and try to fix that.

harbaum, 2023-07-27:
Edit: 2.0.10 is still available but has the same crackling noise ... annoying ...

KlausMu, 2023-07-27:
As a workaround, you can make 2.0.6 available again:
File - preferences - Additional boards managers URLs - add
https://espressif.github.io/arduino-esp32/package_esp32_index.json

Then
Tools - Board - Boards Manager
Now you can select version 2.0.6 for "esp32 by Espressif Systems"

No I have sound and Galaga running.

Good luck for finding the issue and thanks a lot for this amazing project.

harbaum, 2023-07-29:
Please use the Arduino IDE

rlueckl, 2023-10-20:
Had the same crashing issue with VS Code **and** Arduino IDE with 2.0.11.

Downgrading Arduino IDE esp32 Espressif to 2.0.6 fixed it for me also.

Closed 2023-07-29.

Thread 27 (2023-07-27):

Crackling sound with ESP32 board support >= 2.0.10

harbaum, 2023-07-27:
While sound was working fine with ESP board support 2.0.6 it only gives a crackling noise in the 2.0.10 and the latest 2.0.11

harbaum, 2023-07-27:
Works up to 2.0.9 and is broken since 2.0.10

The following sketch gives a clean rectangular signal up to 2.0.9 and the crackling noise on later versions.

```
#include "driver/i2s.h"

unsigned short snd_buffer[64];

void setup() {
  // put your setup code here, to run once:

  static const i2s_config_t i2s_config = {
    .mode = (i2s_mode_t)(I2S_MODE_MASTER | I2S_MODE_TX | I2S_MODE_DAC_BUILT_IN),
    .sample_rate = 24000,
…  printf("BytesOut: %d\n", bytesOut);
}

```

harbaum, 2023-07-27:
See https://github.com/espressif/arduino-esp32/issues/8467

harbaum, 2023-07-29:
Please try the latest commit. The donkey kong sounds are the most critical ones and may be affected most by the implemented work around.

Still unclear what's causing the apll to generate the crackling noise.

bjotos, 2023-08-01:
I started with this project after reading about it in the latest Make and ran in exact the issue with crackling noise from the speakers w/o this fix (cloned repo last week). And this commit solved it.

But I was getting this noise also in game select screen where it should be silent, which makes me wonder if that's because I'm using single-wire SC8002B, while PAM8302A uses differential audio signal, or some other difference with these solutions (different amps, different filters, ...)

P.S.: Thanks for the great work, love it ;)

harbaum, 2023-08-02:
The crackling sound even happens when there's silence at a signal level != zero. So yes, it was expected to happen in the menu as well.

Closed 2023-08-02.

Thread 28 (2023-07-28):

upload is not executed

Moritz24503, 2023-07-28:
Hey, when I want to upload the code via the Arduino IDE, the following error message always comes up. What can I do about it?`

`/Users/benutzer/Desktop/galagino-main3/galagino/video.cpp:52:1: sorry, nicht implementiert: nicht-triviale designierte Initialisierer werden nicht unterstützt }; ^ /Users/benutzer/Desktop/galagino-main3/galagino/video.cpp:52:1: sorry, nicht implementiert: nicht-triviale designierte Initialisierer werden nicht unterstützt /Users/benutzer/Desktop/galagino-main3/galagino/video.cpp: Im Konstruktor 'Video::Video()': video.cpp:131:22: Fehler: 'SPI1_HOST' wurde in diesem Bereich nicht deklariert spi_bus_initialize(SPI1_HOST, &bus_cfg, SPI_DMA_CH_AUTO); ^ video.cpp:131:43: Fehler: 'SPI_DMA_CH_AUTO' wurde in diesem Bereich nicht deklariert spi_bus_initialize(SPI1_HOST, &bus_cfg, SPI_DMA_CH_AUTO); ^ In der Datei enthalten von /Users/benutzer/Documents/Arduino/libraries/FastLED/src/FastLED.h:75:0, von /Users/benutzer/Desktop/galagino-main3/galagino/leds.h:8, von /Users/benutzer/Desktop/galagino-main3/galagino/leds.cpp:7: /Users/benutzer/Documents/Arduino/libraries/FastLED/src/fastspi.h:157:23: Hinweis: #pragma-Nachricht: Keine Hardware-SPI-Pins definiert. Alle SPI-Zugriffe werden standardmäßig auf Bitbang-Ausgaben gesetzt # pragma-Nachricht "Keine Hardware-SPI-Pins definiert. Alle SPI-Zugriffe werden standardmäßig auf bitbanged-Ausgaben gesetzt" ^ In der Datei enthalten von /Users/benutzer/Documents/Arduino/libraries/FastLED/src/FastLED.h:75:0, von /Users/benutzer/Desktop/galagino-main3/galagino/leds.h:8, von /Users/benutzer/Desktop/galagino-main3/galagino/galagino.ino:14: /Users/benutzer/Documents/Arduino/libraries/FastLED/src/fastspi.h:157:23: Hinweis: #pragma-Nachricht: Keine Hardware-SPI-Pins definiert. Alle SPI-Zugriffe werden standardmäßig auf Bitbang-Ausgaben gesetzt # pragma-Nachricht "Keine Hardware-SPI-Pins definiert. Alle SPI-Zugriffe werden standardmäßig auf bitbanged-Ausgaben gesetzt" ^ /Users/benutzer/Desktop/galagino-main3/galagino/galagino.ino: In der Funktion 'void dkong_trigger_sound(char)': galagino:555:23: Fehler: keine Matching-Funktion für den Aufruf von 'random()' char rnd = random() % 3; ^ In der Datei enthalten von /var/folders/6c/04z3f_2j7kvd7nx0xxnjn3g40000gn/T/arduino_build_284766/sketch/galagino.ino.cpp:1:0: /Users/benutzer/Library/Arduino15/packages/esp32/hardware/esp32/1.0.6/cores/esp32/Arduino.h:121:6: Hinweis: Kandidat: long int random(long int, long int) lang zufällig (lang, lang); ^ /Users/benutzer/Library/Arduino15/packages/esp32/hardware/esp32/1.0.6/cores/esp32/Arduino.h:121:6: Hinweis: Der Kandidat erwartet 2 Argumente, 0 zur Verfügung gestellt In der Datei enthalten von /var/folders/6c/04z3f_2j7kvd7nx0xxnjn3g40000gn/T/arduino_build_284766/sketch/galagino.ino.cpp:1:0: /Users/benutzer/Library/Arduino15/packages/esp32/hardware/esp32/1.0.6/cores/esp32/Arduino.h:179:6: Hinweis: Kandidat: long int random(long int) lang zufällig (lang); ^ /Users/benutzer/Library/Arduino15/packages/esp32/hardware/esp32/1.0.6/cores/esp32/Arduino.h:179:6: Hinweis: Kandidat erwartet 1 Argument, 0 zur Verfügung gestellt /Users/benutzer/Desktop/galagino-main3/galagino/galagino.ino: In der Funktion 'void audio_init()': /Users/benutzer/Desktop/galagino-main3/galagino/galagino.ino:618:3: sorry, nicht implementiert: nicht-triviale designierte Initialisierer nicht unterstützt }; ^ /Users/benutzer/Desktop/galagino-main3/galagino/galagino.ino:618:3: sorry, nicht implementiert: nicht-triviale designierte Initialisierer nicht unterstützt /Users/benutzer/Desktop/galagino-main3/galagino/galagino.ino:618:3: sorry, nicht implementiert: nicht-triviale designierte Initialisierer nicht unterstützt /Users/benutzer/Desktop/galagino-main3/galagino/galagino.ino:618:3: sorry, nicht implementiert: nicht-triviale designierte Initialisierer nicht unterstützt Bibliothek FastLED in Version 3.6.0 im Ordner: /Users/benutzer/Documents/Arduino/libraries/FastLED wird verwendet Ausstiegsstatus 1 'SPI1_HOST' wurde in diesem Bereich nicht deklariert`

harbaum, 2023-07-29:
What version of the Arduino IDE are you using? Which version of the ESP32 board package? What board type did you select?

Moritz24503, 2023-07-31:
Arduino Ide: 1.8.19
ESP32 Package: 1.0.6
Board Type: ESP32 Wrover Module

harbaum, 2023-07-31:
Please use esp32 bosrd support 2.0.9

And don't enable the PSRAM of the wrover.

harbaum, 2023-08-14:
Does it work now?

Moritz24503, 2023-08-15:
Yes, thanks.

Closed 2023-08-15.

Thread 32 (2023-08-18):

Feature Request: Bluetooth Gamepad support

OHacks, 2023-08-18:
The ESP32 supports bluetooth.
May be it is possible to add bluetooth gamepad support, that would keep the device as cool as it is and would improve the playability a lot.

harbaum, 2023-10-02:
I am afraid Bluetooth (and also WLAN) Support will generate frequent Background processing load. This may interfere with the pretty tight performance demands of the emulation itself.

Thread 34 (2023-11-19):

Feature request - Use c button on nunchuck for coin/start

mothra78, 2023-11-19:
Thanks for this great project. I have compiled and installed on CYD and works great.
It seems I have an extra "c" button on the nintendo wii nunchuck which does not seem to be used.

I would love for it to allow to start the game and avoid using the boot button on the back of the board.

I will see if I can implement this feature...

mothra78, 2023-11-19:
Made a quick an dirty implementation  by updating nunchuck.h with :

    return ((joyX < 127 - NUNCHUCK_MOVE_THRESHOLD) ? BUTTON_LEFT : 0) | //Move Left
           ((joyX > 127 + NUNCHUCK_MOVE_THRESHOLD) ? BUTTON_RIGHT : 0) | //Move Right
           ((joyY > 127 + NUNCHUCK_MOVE_THRESHOLD) ? BUTTON_UP : 0) | //Move Up
           ((joyY < 127 - NUNCHUCK_MOVE_THRESHOLD) ? BUTTON_DOWN : 0) | //Move Down
           (nchuk.buttonZ() ? BUTTON_FIRE : 0) | // Fire
           (nchuk.buttonZ() ? BUTTON_START : 0) | // Start
           (nchuk.buttonC() ? BUTTON_COIN : 0); // Coin

and  galagino.ino with buttons_get(void) {:

#ifdef NUNCHUCK_INPUT
      return getNunchuckInput();
#else

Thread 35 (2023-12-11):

Missing i2s libs in the sources

purehunter1, 2023-12-11:
When trying to compile the galagino.ino I encounter an error message, that the file "driver/i2s.h" is missing. Due to the statement
#include "driver/i2s.h"
it has to be part of the project-files, but it isn't.

I tried to collect this and other missing files from espressif and place it in the respective subdirectory of the sourcefiles but this is a never-ending story.
Is there a simpler and safe soution in place?

Regards purehunter

purehunter1, 2023-12-12:
It seems, it has to do with the actual ESP32 Board Manager 2.0.11. After downgrading to Rev. 2.0.10 and modification of the #include statement to
`#include <driver/i2s.h>`
I got the compilation completed.
But I'm waiting for the display, so I cannot test it right now.

I don't want to miss to say: Absolutely great project! I'm really happy that I found it. Thanks for all the work!

Regards purehunter

harbaum, 2023-12-26:
If you figure out how to use this with the newer versions, then please feel free to open a PR.

purehunter1, 2024-01-04:
I just tried to reproduce this problem, but after upgrading the board-manager to 2.0.11 again, it still worked.
But only with the modification mentioned above: replace `#include "driver/i2s.h"` by `#include <driver/i2s.h>`

As I got some questionable error-messages and warnings (only) at the first compilation after upgrading, I think it is a kind of instability of the IDE.

harbaum, 2024-01-04:
Thanks. Please open a PR for this.

Closed 2024-01-04.

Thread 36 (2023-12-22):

Gerber Files for cabling

AxelAhlborn, 2023-12-22:
Hello Mr. Harbaum, in your YouTube video https://www.youtube.com/watch?v=s7kZmB4fsLA you show circuit boards for the cabling from 42:30 onwards. I'm very interested in this. Prototype on breadboard is already running, joystick is also ready. Housing parts created with the 3D printer. The wiring is a horror because I'm currently unable to keep my hand as steady as I should for soldering. Can you please include the Gerber files in the project. Thank you ! Many greetings from the Wolfenbüttel district. Axel Ahlborn

harbaum, 2023-12-22:
Indeed, I never uploaded these. I have to admit that I also never tested them as I had enough devices built the ordinary way. Will upload them asap ...

AxelAhlborn, 2023-12-23:
Hello Mr. Harbaum, I would be happy to support you with the tests. Even if I have to place further orders with JLCPCB, it won't be a big hassle.

AxelAhlborn, 2023-12-23:
axel.ahlborn@googlemail.com

harbaum, 2023-12-26:
Added: https://github.com/harbaum/galagino/tree/main/hardware/pcbs

Closed 2023-12-26.

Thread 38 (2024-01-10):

Feature request: more ROM options

giobbino, 2024-01-10:
Absolutely amazing! Awesome! I was looking for some fun projects with ESP32, and after some failures with other projects, I found this one, that works like a charm with great and very complete instructions. Instead of a cabinet, I 3D printed a console for it (I will release it on thingiverse as soon as I will reach the final version (no issues).

I was wondering: can you release other ROM packs with different games of the era? I wish make other consoles using the same hardware; actually I looked at the source code, but building a new ROM pack is beyond my skills, unfortunately.

I would love to see Gyruss in this pack, that was quite famous (at least in some part of Europe) and has an amazing music.
Other classic ROMs of the era with vertical display (IIRC), just as suggestion/example, could be Space Invaders, Phoenix, Xevious, Time Pilot, Quix, Q-Bert, Bomb Jack...

harbaum, 2024-01-11:
Great that you are having fun with it.

There's a general issue with adding more games. Currently, there's one CPU emulation code which decides for every instruction for which machine this is to be emulated. This gets slightly slower with every machine added and affects emulation speed of the existing machines. But this can sure be optimized with some effort.

Regarding the games you are suggesting:
- Gyruss has four CPUs of three different types and five audio chips. That's simply beyond what the ESP32 or at least my solution for it is able to handle
- Space invaders is IMHO to close to Galaga. So is Phoenix. Both are nice but "yet another old space shooter" doesn't motivate me enough to spend the time
- xevious may work and even runs on the same hardware as 1942. So that's an option
- Time Pilot may also work. But is yet another shooter like Galaga and 1942
- Quix looks "different" which is fine. But it's based on the 6809 CPU which I don't have an emulation for
- Q-Bert also is nice and also has a CPU which I don't emulate (yet): a 8086 CPU
- Bomb Jack seems to fit the bill quite well. Two Z80 CPUs and three AY sound chips are e.g. what 1942 also uses

To summarize: I have no immediate plans to work on this. But if I had to choose one game it would probably be Bomb Jack. It differs enough from the games already implemented to add something. And its hardware seems to be pretty close to what Galagino already supports. Still it's some days work to implement.

This is a nice description how Bomb Jack works: https://floooh.github.io/2018/10/06/bombjack.html

giobbino, 2024-01-11:
Hi, thanks for your prompt answer!

too bad Gyruss isn't an option, but okay, I can play it on my PC, so not a big issue  :-)

Of course all the games I mentioned were just suggestions/examples, not a real requirement; I just cited the ones that was really cool in the '80s, based on my memory.

A note about Space Invaders: I friendly disagree with you; yes it's another space shooter and it's close to Galaga, but it's an icon, so it would be really nice because of its historical relevance. Just a personal opinion, of course.

Time Pilot is actually another shoot game, but IMO it's quite different from the others because you don't move your ship from the center of the screen, so the player experience is really different and not comparable with 1942, I believe.

Other titles I didn't mentioned (yet) because I was not even sure you could be some way interested to spend more time on this project (of course I'm strongly hoping you will do LOL). I would say "Tetris" but I'm afraid it would be too much for the ESP32 too.

Maybe Burger Time? Tapper?

Bomb Jack would be awesome! I'm reading the page you cited, absolutely amazing! I've never think about what was hard for the programmers of that era to fit some incredible games in a tight hardware!

gilmod714, 2024-09-28:
I'm surprised nobody mentioned "Horizontal space shooters" like Defender and Gradius ! .. how about adding this variety to the mix ;)

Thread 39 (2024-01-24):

Constant buzzing from speaker on GPIO26 (CYD). Can an external I2S amp be used?

pinter75, 2024-01-24:
HI,

Steller work on this, it's faultless!!

Except for the sound on my CYD display. It has an amp on pin 26, but all I hear is a buzzing sound?

To be honest I have not really ever had much luck with the sound on these boards.

So can an external I2S amp (MAX98357) be used, probably overkill for the sounds generated, but a least I will hear something less annoying than a buzzing!

:-)

pinter75, 2024-01-25:
Seems I have a broken amp IC.

not-surt, 2024-01-25:
There's a known design defect with the CYD amp: https://github.com/witnessmenow/ESP32-Cheap-Yellow-Display/blob/main/Mods/README.md#audio-amp-gain-mod

harbaum, 2024-01-25:
It should be possible to use an external i2s amp with minimal changes. But I never tried that.

Closed 2024-01-25.

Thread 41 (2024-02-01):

error: 'I2S_MODE_DAC_BUILT_IN' was not declared in this scope

amishrabbit, 2024-02-01:
While attempting to compile and build the Galagino package for a ESP32-2432S028R (aka, CYD or "Cheap Yellow Display") using the Arduino IDE under Windows 10, the following error appears.

```
<path-to-repo>\galagino-main\galagino\galagino.ino: In function 'void audio_init()':
<path-to-repo>\galagino-main\galagino\galagino.ino:636:58: error: 'I2S_MODE_DAC_BUILT_IN' was not declared in this scope
     .mode = (i2s_mode_t)(I2S_MODE_MASTER | I2S_MODE_TX | I2S_MODE_DAC_BUILT_IN),
                                                          ^~~~~~~~~~~~~~~~~~~~~
<path-to-repo>\galagino-main\galagino\galagino.ino:636:58: note: suggested alternative: 'I2S_MODE_MASTER'
     .mode = (i2s_mode_t)(I2S_MODE_MASTER | I2S_MODE_TX | I2S_MODE_DAC_BUILT_IN),
                                                          ^~~~~~~~~~~~~~~~~~~~~
                                                          I2S_MODE_MASTER
<path-to-repo>\galagino-main\galagino\galagino.ino:669:20: error: 'I2S_DAC_CHANNEL_RIGHT_EN' was not declared in this scope
   i2s_set_dac_mode(I2S_DAC_CHANNEL_RIGHT_EN);
                    ^~~~~~~~~~~~~~~~~~~~~~~~
<path-to-repo>\galagino-main\galagino\galagino.ino:669:20: note: suggested alternative: 'I2S_CHANNEL_FMT_RIGHT_LEFT'
   i2s_set_dac_mode(I2S_DAC_CHANNEL_RIGHT_EN);
                    ^~~~~~~~~~~~~~~~~~~~~~~~
                    I2S_CHANNEL_FMT_RIGHT_LEFT
<path-to-repo>\galagino-main\galagino\galagino.ino:669:3: error: 'i2s_set_dac_mode' was not declared in this scope
   i2s_set_dac_mode(I2S_DAC_CHANNEL_RIGHT_EN);
   ^~~~~~~~~~~~~~~~
<path-to-repo>\galagino-main\galagino\galagino.ino:669:3: note: suggested alternative: 'i2s_set_clk'
   i2s_set_dac_mode(I2S_DAC_CHANNEL_RIGHT_EN);
   ^~~~~~~~~~~~~~~~
   i2s_set_clk

exit status 1

Compilation error: 'I2S_MODE_DAC_BUILT_IN' was not declared in this scope
```

Attempting these changes trigger additional errors to appear in the compiler log.

Is there a workaround for this issue on this model of device?

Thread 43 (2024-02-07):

Higher quality reference image?

GMDSulky, 2024-02-07:
Hey there! I just found this project and it's REALLY cool! I can't wait to make little tiny arcade machines in my own home!

I was just wondering if you had a higher quality image of the reference breadboard, I'm having trouble figuring out what wires go where as I think the pins on my ESP32 are laid out differently compared to the example. Here is the ESP32 I'm using for reference.

https://www.aliexpress.us/item/3256805517875317.html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

Thanks in advance!

- Sulky

harbaum, 2024-02-07:
There's a PDF link right below the image. This will give you a much higher resolution.

GMDSulky, 2024-02-07:
Ah. Didn't see the hyperlink. My bad. Thanks.

Closed 2024-02-07.

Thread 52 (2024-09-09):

ST7735 ?!

gilmod714, 2024-09-09:
Hello,
is it possible to add support for TFT st7735  (128x160) ?!

I know it is smaller than the recommended display, but that's what I have at the moment ;)

btw .. I was able to compile and upload the sketch fully to ESP32-dev board .. I looked at the config.h file but couldn't figure out if st7735 is supported or not ..

thank you!

harbaum, 2024-09-10:
The contents won't fit. I am sure you could add that. But I don't see the point if part of the game area will be missing.

Closed 2024-09-23.

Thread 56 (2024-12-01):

Help with a custom controller implementation on CYD.

aedile, 2024-12-01:
Greetings,

I have things working on a CYD, but I don't want to use a Wii nunchuck.  CYD doesn't have adequate GPIO pins for a proper controller, so I've worked on making my own i2c device using an Seeeduino Xiao.  I tested this i2c device using an ESP32 and it seems to work just fine when using the default i2c pins on the esp32.  Here is the slave sketch:

```
#include <Arduino.h>
#include <Wire.h>

// Define Slave I2C Address
#define SLAVE_ADDR 9

#define XPIN  0 // Arduino pin connected to VRX pin
#define YPIN  1 // Arduino pin connected to VRY pin
#define ZPIN  2  // Arduino pin connected to VRZ pin

#define APIN 3 // Arduino pin connected to button A pin
#define BPIN 6 // Arduino pin connected to button A pin

// Input values
int joystick_calibration_x = -3;
int joystick_calibration_y = 6;
int xValue = 0; // To store value of the X axis
int yValue = 0; // To store value of the Y axis
int xPinValue = 0;
int yPinValue = 0;
bool zButton = 0; // To store value of the Z button
bool aButton = 0; // To store value of the A button
bool bButton = 0; // To store value of the B button

// Banger
int bcount = 0;

// I2C Communication
void requestEvent() {
  // Define a byte to hold data
  byte bval = 0;

  // Cycle through data
  // First response is always 255 to mark beginning
  switch (bcount) {
    case 0:
      bval = 255;
      break;
    case 1:
      bval = xValue;
      break;
    case 2:
      bval = yValue;
      break;
    // Note: Buttons read high normally, so we invert them
    case 3:
      bval = zButton;
      break;
    case 4:
      bval = aButton;
      break;
    case 5:
      bval = bButton;
      break;
  }

  // Send response back to Master
  Wire.write(bval);
  Serial.printf("Sent: %d\n", bval);
  // Increment byte counter
  bcount++;
  if (bcount > 5) bcount = 0;
}

void setup() {
  Serial.begin(115200) ;
  // Joystick X and Y pins are analog
  pinMode(XPIN, INPUT);
  pinMode(YPIN, INPUT);
  pinMode(ZPIN, INPUT_PULLUP);

  // Button A and B pins are digital
  pinMode(APIN, INPUT_PULLUP);
  pinMode(BPIN, INPUT_PULLUP);

    // Initialize I2C communications as Slave
  Wire.begin(SLAVE_ADDR);

   // Function to run when data requested from master
  Wire.onRequest(requestEvent);
}

void loop() {
  // read analog X and Y analog values
  xPinValue = analogRead(XPIN) + joystick_calibration_x;
  yPinValue = analogRead(YPIN) + joystick_calibration_y;

  // Convert analog values to 8-bit values
  float xpct = (xPinValue / 1024.0);
  float ypct = (yPinValue / 1024.0);
  xValue = (floor(xpct*255)>255)?255:floor(xpct*255);
  yValue = (floor(ypct*255)>255)?255:floor(ypct*255);

  // read digital Z button value
  zButton = digitalRead(ZPIN);
  // read digital A button value
  aButton = digitalRead(APIN);
  // read digital B button value
  bButton = digitalRead(BPIN);

  // print data to Serial Monitor on Arduino IDE
  Serial.printf("x = %d, y = %d, z = %d, a = %d, b = %d   \n", xValue, yValue, zButton, aButton, bButton);
  delay(10);
}

```

And here is the master sketch:
```
#include <Arduino.h>
#include <Wire.h>
#include <vector>

// Define Slave I2C Address
#define SLAVE_ADDR 9

// Define counter to count bytes in response
int bcount;

// Define array for return data
byte controller[5];

void setup()
{
  Wire.begin();
  Serial.begin(9600);
}

byte readI2C(int address) {
  // Define a variable to hold byte of data
  byte bval ;
  long entry = millis();
  // Read one byte at a time
  Wire.requestFrom(address, 1);
  // Wait 100 ms for data to stabilize
  while (Wire.available() == 0 && (millis() - entry) < 100)  Serial.print("Waiting");
  // Place data into byte
  if  (millis() - entry < 100) bval = Wire.read();
  return bval;
}

void loop()
{

  while (readI2C(SLAVE_ADDR) < 255) {
  // Until first byte has been received print a waiting message
    Serial.print("Waiting");
  }
  for (bcount = 0; bcount < 5; bcount++) {
    controller[bcount] = readI2C(SLAVE_ADDR);
  }

  // Vector of 5 strings
  std::vector<String> labels = {"X: ", "Y: ", "Z: ", "A: ", "B: "};

  for (int i = 0; i < 5; i++) {
    Serial.printf("%s%d ", labels[i].c_str(), controller[i]);
  }
  Serial.println();
  delay(20);
}
```

As I said, this seems to be working just fine.  So I turned my hand toward modifying it to use with Galagino.

I got Galagino compiling and running on my CYD with just a few modifications to `config.h` per the instructions.  The serial is reporting `Nunchuck disconnected!` of course, but the roms load and go through the motions, I can get them to start with the button as you'd expect.

I thought the best way to try to implement my i2c controller was to just overwrite the existing `nunchuck.h` include with my own `i2c.h` include with the same functions implemented for my device.  I updated the main sketch to include my file instead of the original, confirmed it's being loaded, and got it compiling and loading just fine.  So here is my implementation:
```
#ifndef _NUNCHUCK_H_
#define _NUNCHUCK_H_

// ----------------------------
// Standard Libraries
// ----------------------------
#include <Arduino.h>
#include <Wire.h>
#include <vector>

// Define Slave I2C Address
#define SLAVE_ADDR 9

#define CTRL_SDA 22
#define CTRL_SCL 27

// Define counter to count bytes in response
int bcount;

// Define array for return data
byte controller[5];

byte readI2C(int address);

//TwoWire Wire = TwoWire(1);

void nunchuckSetup() {
  //Serial.begin(115200);
  pinMode(CTRL_SDA, INPUT_PULLUP);
  pinMode(CTRL_SCL, INPUT_PULLUP);
  Serial.println("About to begin I2C.");
  Wire.begin(CTRL_SDA, CTRL_SCL,100000);
  Serial.println("I2C begun!");
}

unsigned char getNunchuckInput() {
    //Wire.end();
    //Wire.begin(CTRL_SDA,CTRL_SCL);
    byte test = readI2C(SLAVE_ADDR);
    while (test < 255) {
      Serial.printf("Byte is currently:%d\n",test );
      test = readI2C(SLAVE_ADDR);
    // Until first byte has been received print a waiting message
      Serial.printf("Waiting to end read\n");
    }
    for (bcount = 0; bcount < 5; bcount++) {
      controller[bcount] = readI2C(SLAVE_ADDR);
    }
    //Wire.end();
    // Read a joystick axis (0-255, X and Y)
    // Roughly 127 will be the axis centered
    int joyX = controller[0];
    int joyY = controller[1];
    int joyZ = controller[2];
    int btnA = controller[3];
    int btnB = controller[4];

    Serial.printf("%d, %d, %d, %d, %d\n", joyX, joyY, joyZ, btnA, btnB);

    return ((joyX < 127 - NUNCHUCK_MOVE_THRESHOLD) ? BUTTON_LEFT : 0) | //Move Left
           ((joyX > 127 + NUNCHUCK_MOVE_THRESHOLD) ? BUTTON_RIGHT : 0) | //Move Right
           ((joyY > 127 + NUNCHUCK_MOVE_THRESHOLD) ? BUTTON_UP : 0) | //Move Up
           ((joyY < 127 - NUNCHUCK_MOVE_THRESHOLD) ? BUTTON_DOWN : 0) | //Move Down
           (btnA ? BUTTON_FIRE : 0) |
           (btnB ? BUTTON_EXTRA : 0) ;

}

byte readI2C(int address) {
  // Define a variable to hold byte of data
  byte bval ;
  long entry = millis();
  // Read one byte at a time
  Wire.requestFrom(address, 1);
  // Wait 100 ms for data to stabilize
  //while (Wire.available() == 0)  Serial.printf("Waiting for read\n");
  while (Wire.available() == 0 && (millis() - entry) < 100)  Serial.printf("Waiting for read\n");
  // Place data into byte
  if  (millis() - entry < 100) bval = Wire.read();
  return bval;
}

#endif //_NUNCHUCK_H_
```

For some reason, when I use this implementation, I can see the values I'm expecting via serial print messages, except for the start byte, which is reading as "1073429516" instead of 255.  Here is what I am getting:
```
Waiting to end read
Byte is currently:1
Waiting to end read
Byte is currently:1073429516
Waiting to end read
Byte is currently:127
Waiting to end read
Byte is currently:127
Waiting to end read
Byte is currently:1
Waiting to end read
Byte is currently:1
Waiting to end read
```
This is really strange to me, but I am new to i2c, Arduino IDE (platformio guy), and Galagino.  I have tried the following things:
1. Using TwoWire instead of wire, 0, 1, and 9 as indices for the constructor (9 just for funsies, it compiled and worked the same as 0, and 1 which behaved the same as just plain "Wire".
2. Swapping both the code and the wiring of the SDA and SCL (and NO I didn't pull a two doctors BOTH reversing the polarity when making that test). I got hung up at a different area when I did this and confirmed I am wired correctly for the CYD with my current setup.
3. Initializing the pins with pullup resistors (this seems prudent as I don't know if the Wire library will initialize the pins appropriately, but may not be necessary, I've tried it both ways and left it in for now). I realize this may be part of the issue since I have extended the wires by necessity at this point due to breadboarding needs. I will try adding pullups inline if nothing else works by tomorrow (not in my workshop rn so no resistors on hand).
4. Adding a bunch of serial debugging messages - this helped narrow down where I am going wrong.
5. Reinitializing the wire each time - this adds way too much latency and also doesn't work.

Things I haven't tried:
1. Just setting it to say if the byte is equal to "1073429516" assume it is the start byte. I don't want to do this because I don't understand why I'm getting that number and it seems like cheating. I may try this later just for funsies, but it's NOT a solution.
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
aedile, 2024-12-15:
Sorry, for the above, button presses are detected in the menu and the game, but not directions.

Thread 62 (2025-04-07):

Compilation error: implicit declaration of function 'millis' [-Wimplicit-function-declaration]

fedekrum, 2025-04-07:
Hi
I am on a Mac, using Arduino IDE Version: 2.3.5
Date: 2025-04-02T13:09:23.254Z (4 days ago)
CLI Version: 1.2.0

I am using board "ESP32-2432S028R CYD" in the board menu and have one of those plugged into the USB connector.

I can run other sketches successfully.

This is the error with Galagino.

/Volumes/Development/galagino/galagino/emulation.c: In function 'prepare_emulation':
/Volumes/Development/galagino/galagino/emulation.c:560:28: error: implicit declaration of function 'millis' [-Wimplicit-function-declaration]
  560 |   master_attract_timeout = millis();
      |                            ^~~~~~
/Volumes/Development/galagino/galagino/emulation.c: In function 'emulate_frame':
/Volumes/Development/galagino/galagino/emulation.c:573:23: error: implicit declaration of function 'micros' [-Wimplicit-function-declaration]
  573 |   unsigned long sof = micros();
      |                       ^~~~~~
/Volumes/Development/galagino/galagino/emulation.c:623:37: error: implicit declaration of function 'esp_random'; did you mean 'srandom'? [-Wimplicit-function-declaration]
  623 |       machine = 1 + ((unsigned long)esp_random()) % MACHINES;
      |                                     ^~~~~~~~~~
      |                                     srandom
/Volumes/Development/galagino/galagino/emulation.c:689:5: error: implicit declaration of function 'ulTaskNotifyTake' [-Wimplicit-function-declaration]
  689 |     ulTaskNotifyTake(1, 0xffffffffUL);
      |     ^~~~~~~~~~~~~~~~
/Volumes/Development/galagino/galagino/emulation.c:692:5: error: implicit declaration of function 'vTaskDelay' [-Wimplicit-function-declaration]
  692 |     vTaskDelay(1);
      |     ^~~~~~~~~~
exit status 1

Compilation error: implicit declaration of function 'millis' [-Wimplicit-function-declaration]

elandivar, 2025-04-13:
Include the line:

#include <Arduino.h>

At the top of emulation.c file

elandivar, 2025-04-13:
Downgrade the ESP32 board to 2.0.17. At least, it worked for me.

fedekrum, 2025-04-19:
> Or... downgrade the ESP32 board to 2.0.17. At least, it worked for me.

It compiled with 3.0.7 and 3.1.3 too.
The problem is 3.2.x

harbaum, 2025-04-19:
Thanks for the info. Even if it compiles and runs there may still be timing/performance issues.

Such problems usually manifested in the dig-dug title animation. If that runs then the overall timing and performance should be fine.

Please consider submitting a PR should you fix things for later IDF versions.

fedekrum, 2025-04-19:
> Please consider submitting a PR should you fix things for later IDF versions.

Sorry, but it is probably out of my capabilities.

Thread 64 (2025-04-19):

Audio speed and pitch (tested on frogger)

fedekrum, 2025-04-19:
Hi,
I am using a CYD with a speaker connected to its audio output.
I have noticed that the speed and pitch of the songs are faster and higher than they should be.
I could lower both things by compiling with the 160MHz option, but it is still faster than it should be.
For sure, lowering this value affects performance, so it is not a real option.

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

Has anybody commented on this issue yet?

Thanks

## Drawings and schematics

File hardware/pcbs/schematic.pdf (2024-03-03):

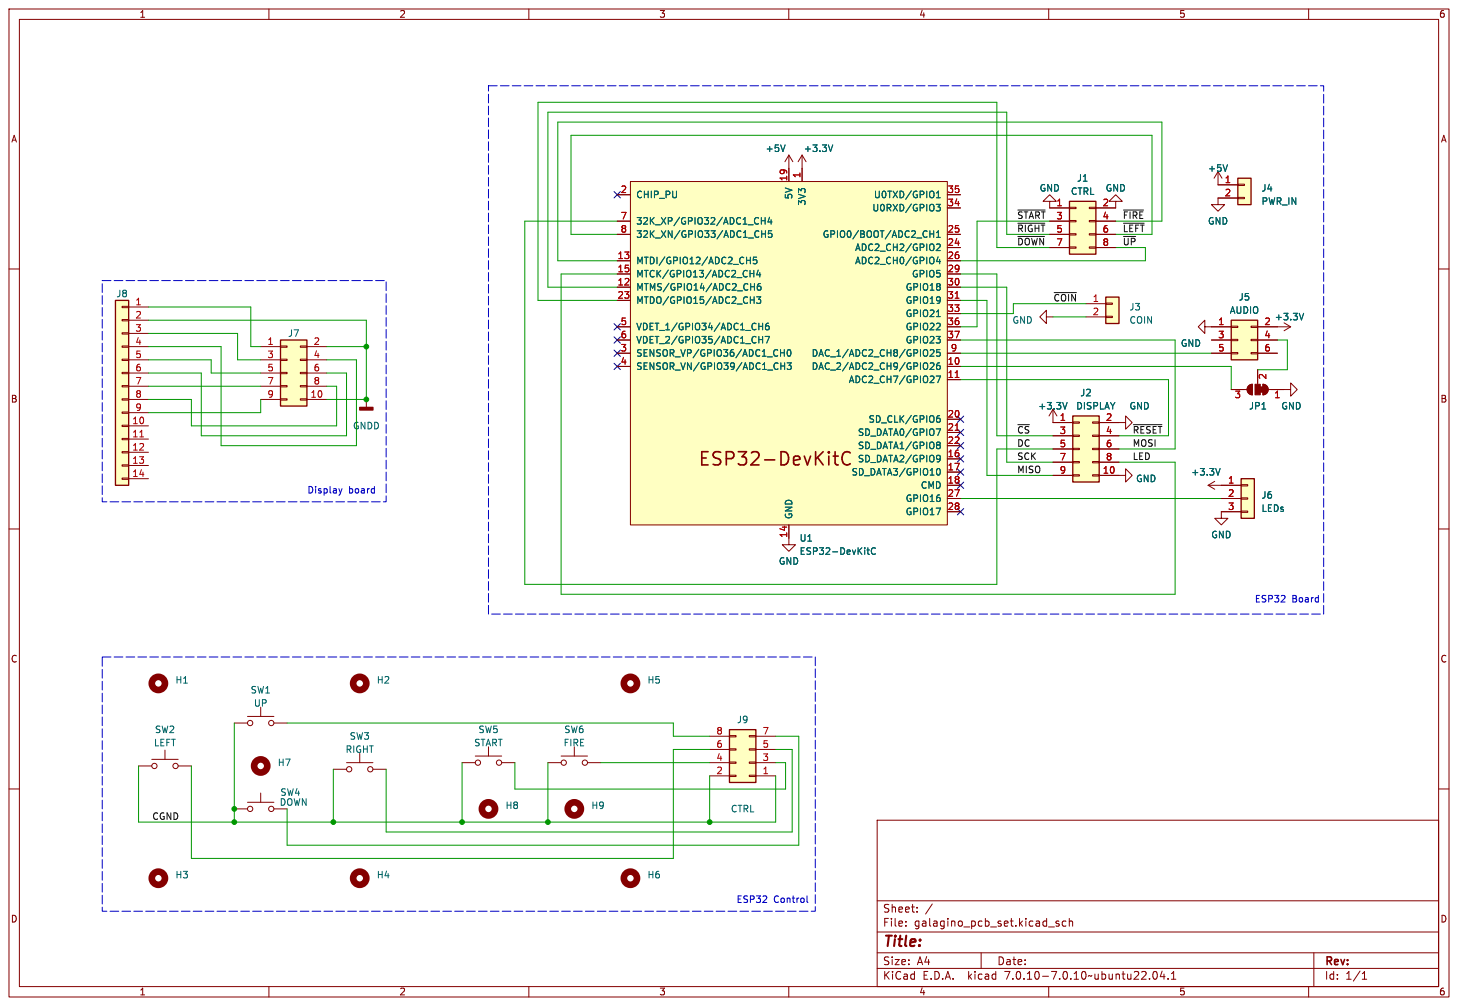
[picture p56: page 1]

1 DAC_2/ADC2_CH9/GPIO26 10 ADC2_CH7/GPIO27 11 MTMS/GPIO14/ADC2_CH6 12 MTDI/GPIO12/ADC2_CH5 13 MTCK/GPIO13/ADC2_CH4 15 SD_DATA2/GPIO9 16 SD_DATA3/GPIO10 17 CMD 18 CHIP_PU 2 SD_CLK/GPIO6 20 SD_DATA0/GPIO7 21 SD_DATA1/GPIO8 22 MTDO/GPIO15/ADC2_CH3 23 ADC2_CH2/GPIO2 24 GPIO0/BOOT/ADC2_CH1 25 ADC2_CH0/GPIO4 26 GPIO16 27 GPIO17 28 GPIO5 29 SENSOR_VP/GPIO36/ADC1_CH0 3 GPIO18 30 GPIO19 31 GPIO21 33 U0RXD/GPIO3 34 U0TXD/GPIO1 35 GPIO22 36 GPIO23 37 SENSOR_VN/GPIO39/ADC1_CH3 4 VDET_1/GPIO34/ADC1_CH6 5 VDET_2/GPIO35/ADC1_CH7 6

Id: 1/1 Title: File: galagino_pcb_set.kicad_sch Sheet: /

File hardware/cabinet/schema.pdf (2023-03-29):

789

12

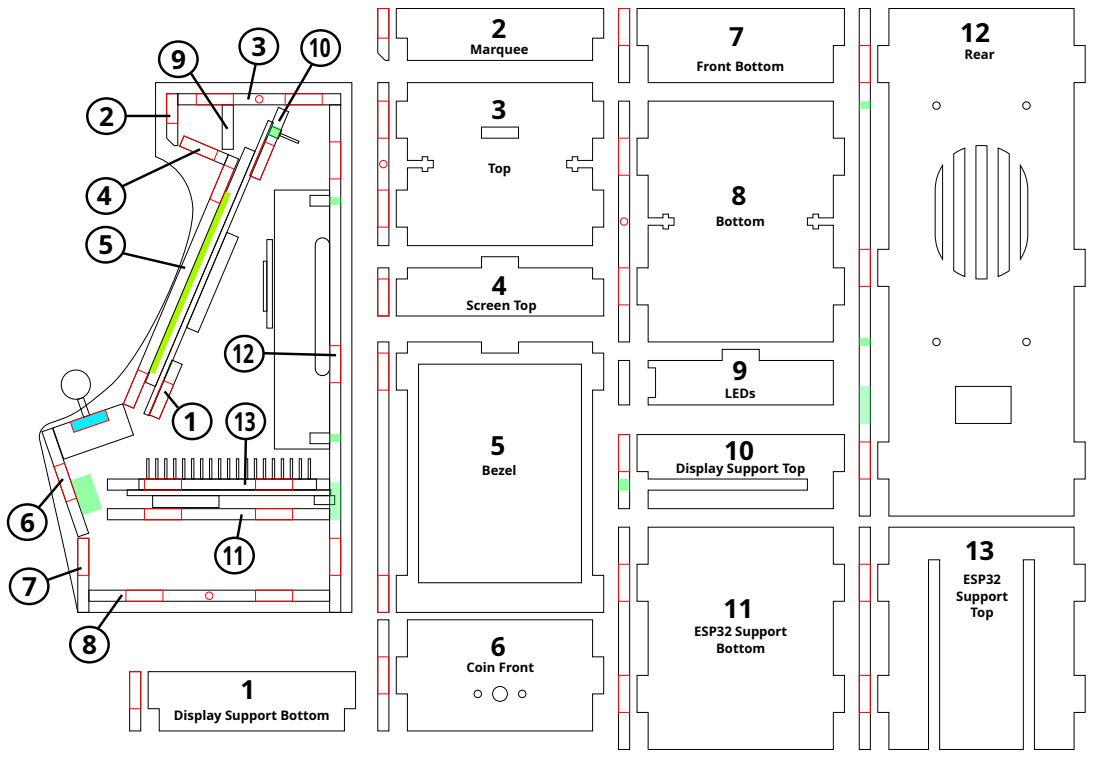
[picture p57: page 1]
Marquee; Top; Screen Top; Bezel; Coin Front; Front Bottom; Bottom; Rear; LEDs; Display Support Top; ESP32 Support Bottom; ESP32 Support Top

Display Support Bottom

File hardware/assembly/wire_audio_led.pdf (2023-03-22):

# ESP32 Bottom

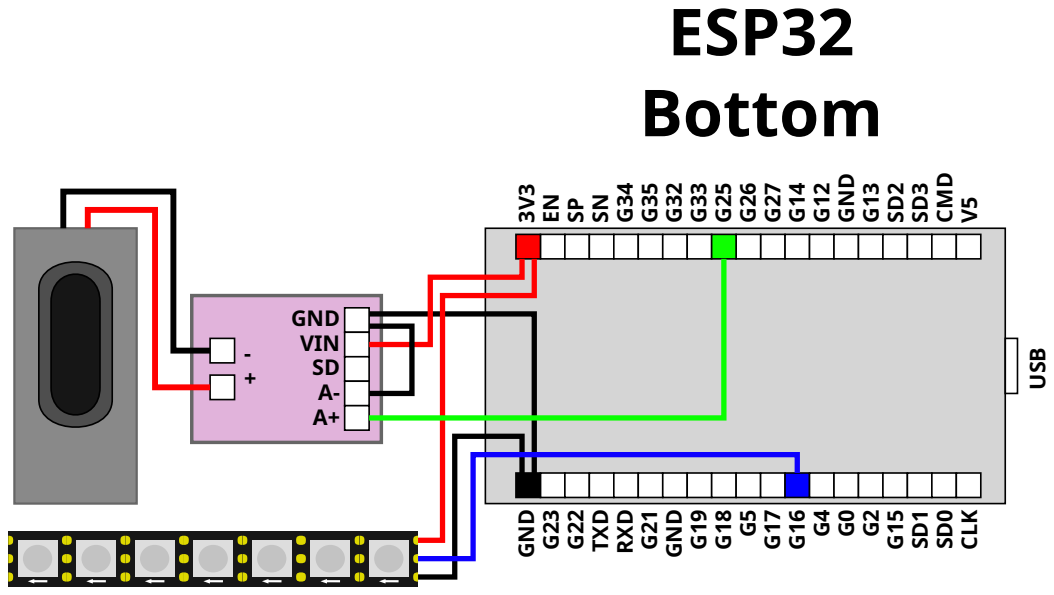
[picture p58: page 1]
GND G13 SD2; CMD; GND; G22 TXD RXD; G21 GND; CLK; USB; GND VIN SD A- A+

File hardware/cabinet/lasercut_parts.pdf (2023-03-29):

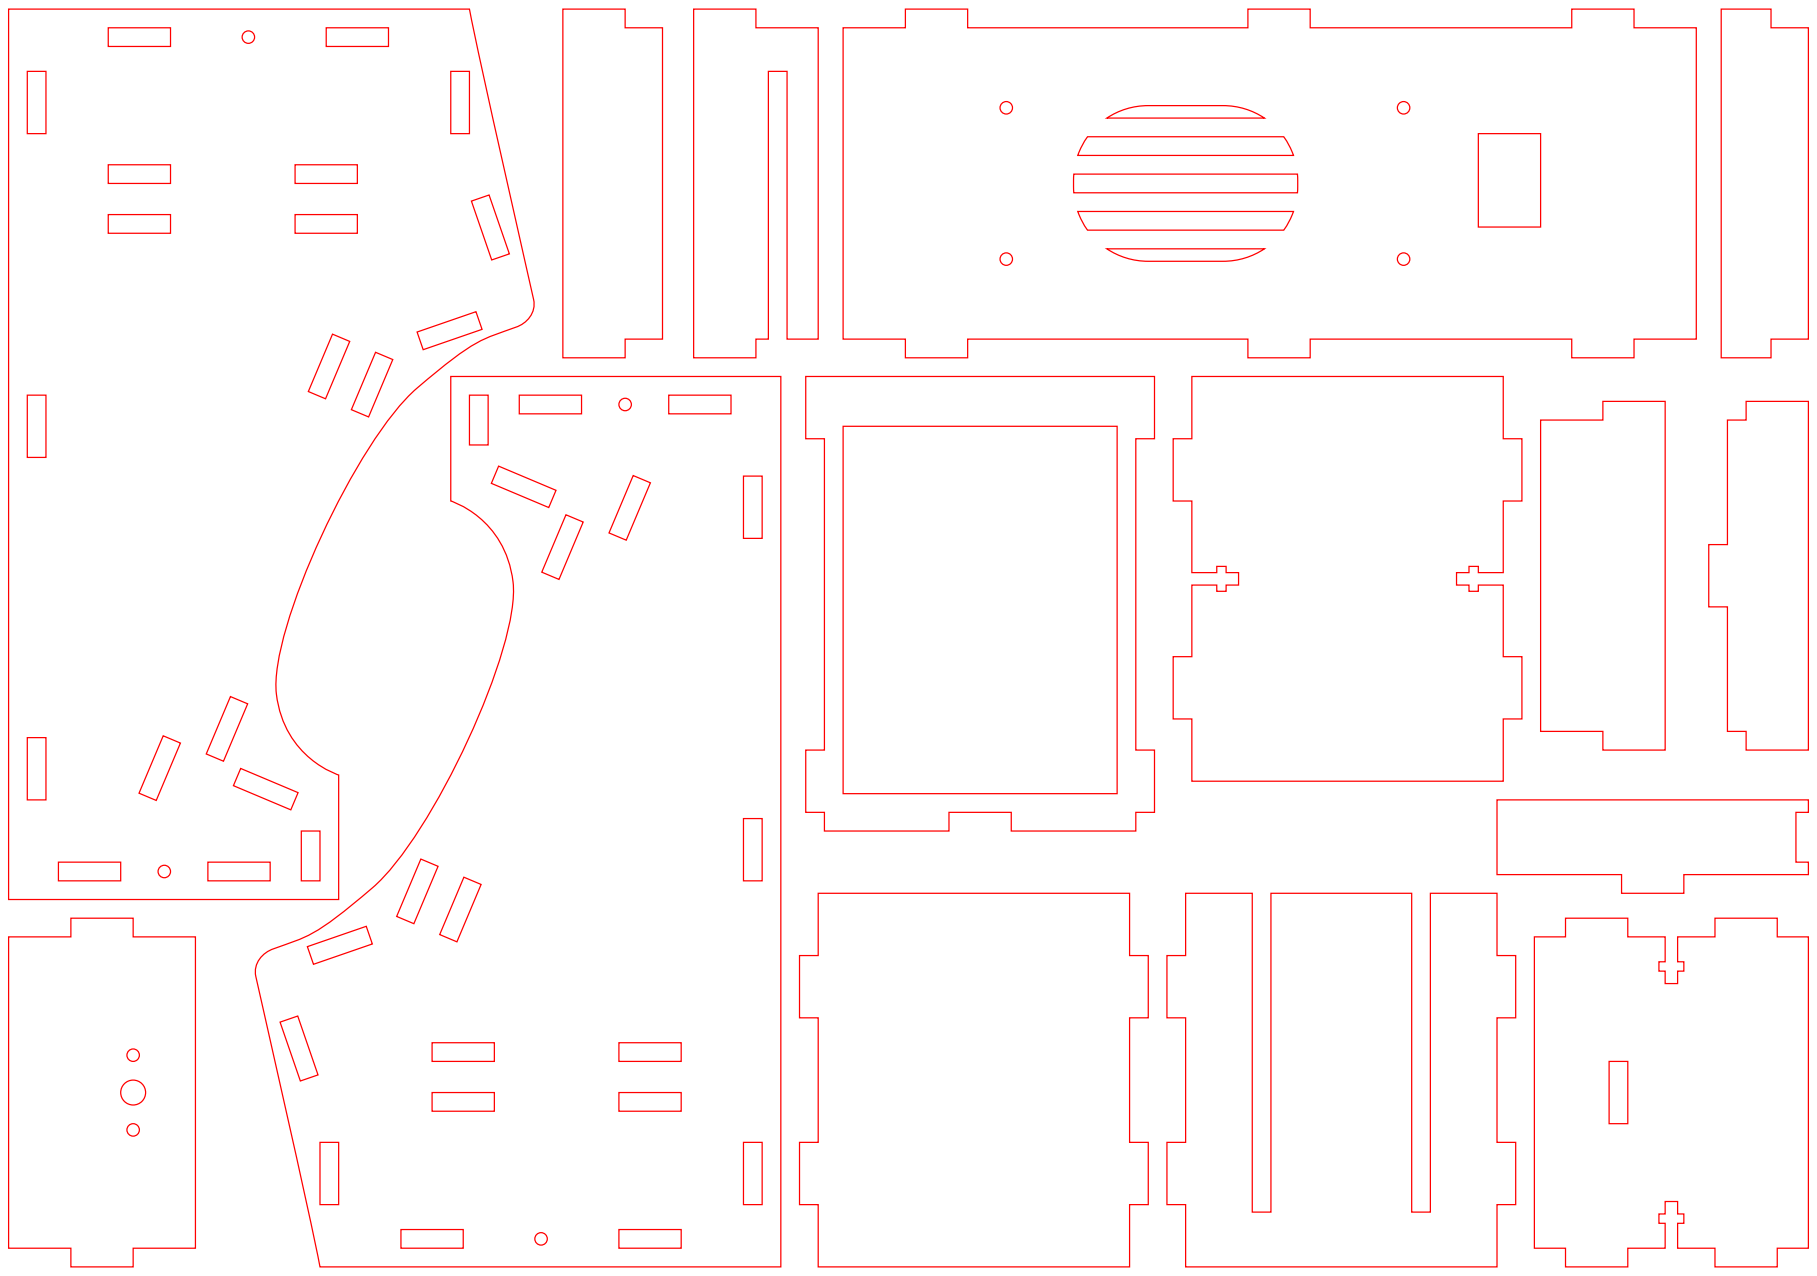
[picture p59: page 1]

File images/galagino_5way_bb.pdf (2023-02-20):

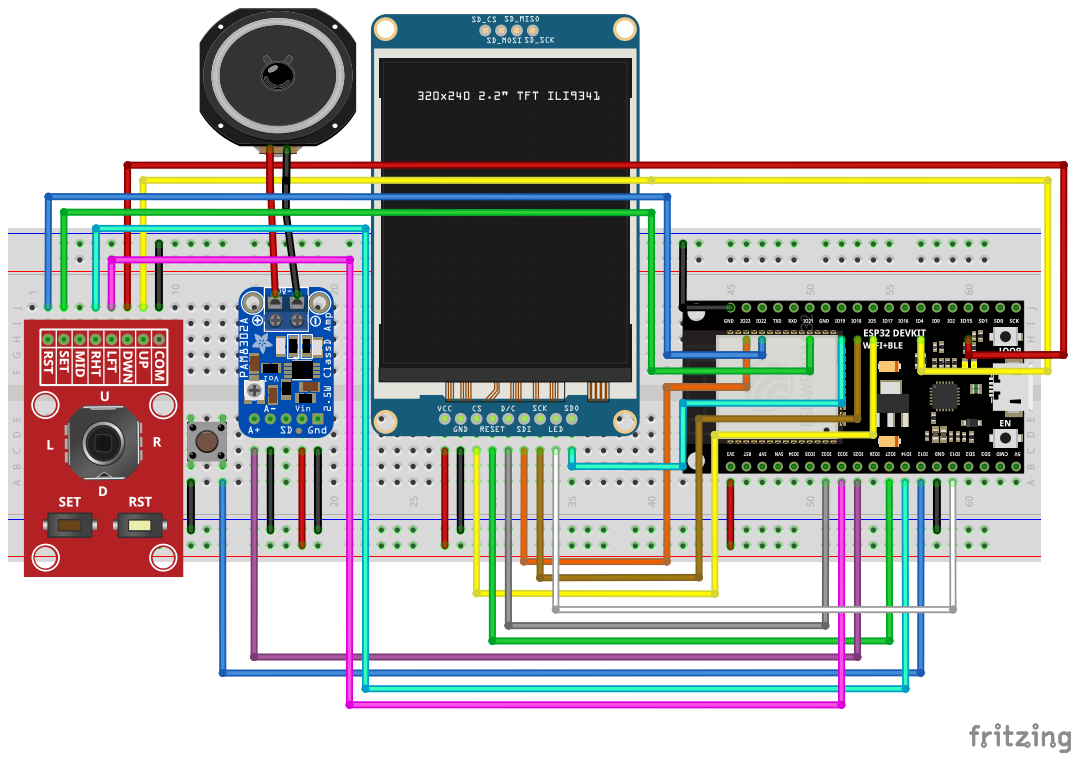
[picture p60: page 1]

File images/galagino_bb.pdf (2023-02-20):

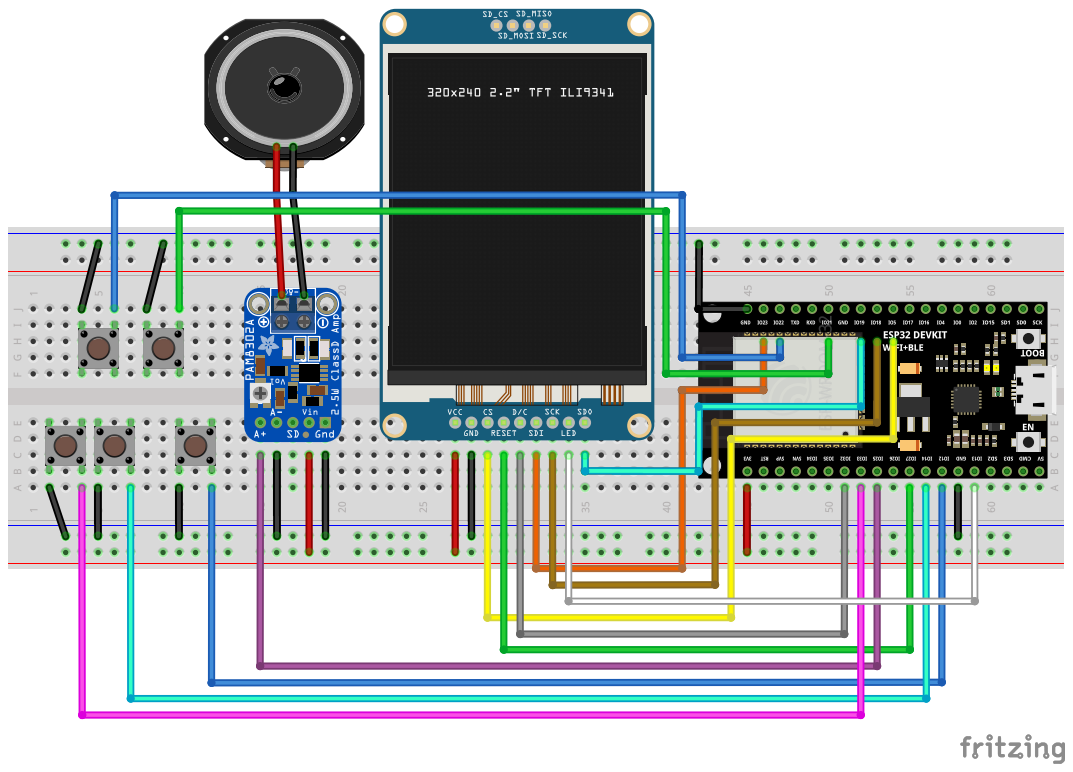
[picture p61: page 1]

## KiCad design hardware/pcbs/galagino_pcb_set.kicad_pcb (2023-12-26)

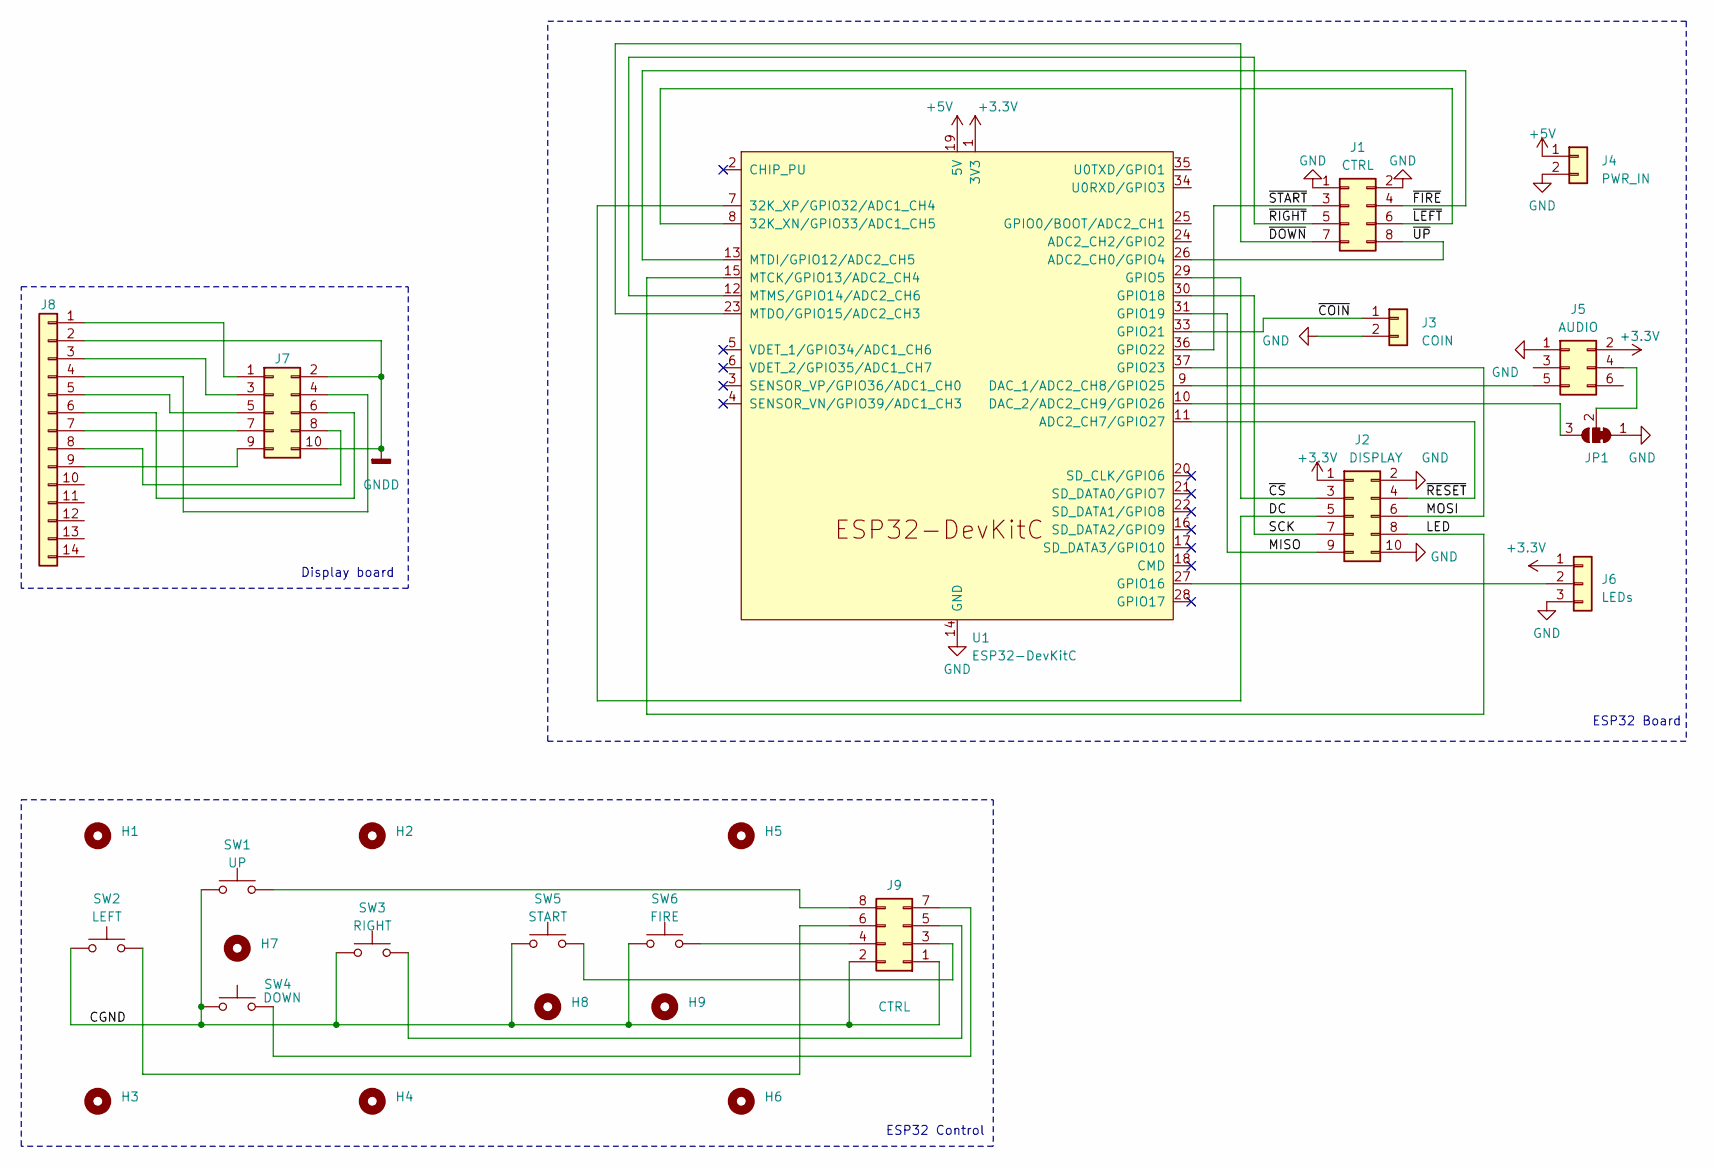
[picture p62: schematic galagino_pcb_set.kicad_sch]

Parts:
H1, H2, H3, H4, H5, H6, H8, H9: MountingHole; MountingHole_2.2mm_M2_ISO7380
H7: MountingHole; MountingHole_5mm
J1, J9: CTRL; PinHeader_2x04_P2.54mm_Vertical
J2, J7: DISPLAY; PinHeader_2x05_P2.54mm_Vertical
J3: COIN; PinHeader_1x02_P2.54mm_Vertical
J4: PWR_IN; PinHeader_1x02_P2.54mm_Vertical
J5: AUDIO; PinHeader_2x03_P2.54mm_Vertical
J6: LEDs; PinHeader_1x03_P2.54mm_Vertical
J8: Conn_01x14; PinSocket_1x14_P2.54mm_Vertical
JP1: DIFF; SolderJumper-3_P1.3mm_Open_RoundedPad1.0x1.5mm
SW1: UP; btn_4.3mm_THT
SW2: LEFT; btn_4.3mm_THT
SW3: RIGHT; btn_4.3mm_THT
SW4: DOWN; btn_4.3mm_THT
SW5: START; SW_PUSH_6mm_H9.5mm
SW6: FIRE; SW_PUSH_6mm_H9.5mm
U1: ESP32-DevKitC

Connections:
+3.3V: J2.1, J5.2, J6.1, U1.1 (3V3)
+5V: J4.1, U1.19 (5V)
/CGND: J9.1, J9.2, SW1.1, SW2.1, SW3.1, SW4.1, SW5.1, SW6.1
/DC: J2.5, U1.7 (32K_XP/GPIO32/ADC1_CH4)
/LED: J2.8, U1.15 (MTCK/GPIO13/ADC2_CH4)
/MISO: J2.9, U1.31 (GPIO19)
/MOSI: J2.6, U1.37 (GPIO23)
/SCK: J2.7, U1.30 (GPIO18)
/~COIN: J3.1, U1.33 (GPIO21)
/~CS: J2.3, U1.29 (GPIO5)
/~DOWN: J1.7, U1.23 (MTDO/GPIO15/ADC2_CH3)
/~FIRE: J1.4, U1.13 (MTDI/GPIO12/ADC2_CH5)
/~LEFT: J1.6, U1.8 (32K_XN/GPIO33/ADC1_CH5)
/~RESET: J2.4, U1.11 (ADC2_CH7/GPIO27)
/~RIGHT: J1.5, U1.12 (MTMS/GPIO14/ADC2_CH6)
/~START: J1.3, U1.36 (GPIO22)
/~UP: J1.8, U1.26 (ADC2_CH0/GPIO4)
GND: J1.1, J1.2, J2.2, J2.10, J3.2, J4.2, J5.1, J6.3, JP1.1 (A), U1.14 (GND), U1.32 (GND), U1.38 (GND)
GNDD: J7.2, J7.10, J8.2
unnamed: J5.4, JP1.2 (C)
unnamed: J5.5, U1.9 (DAC_1/ADC2_CH8/GPIO25)
unnamed: J6.2, U1.27 (GPIO16)
unnamed: J7.1, J8.1
unnamed: J7.3, J8.3
unnamed: J7.4, J8.4
unnamed: J7.5, J8.5
unnamed: J7.6, J8.6
unnamed: J7.7, J8.7
unnamed: J7.8, J8.8
unnamed: J7.9, J8.9
unnamed: J9.3, SW5.2
unnamed: J9.4, SW6.2
unnamed: J9.5, SW3.2
unnamed: J9.6, SW2.2
unnamed: J9.7, SW4.2
unnamed: J9.8, SW1.2
unnamed: JP1.3 (B), U1.10 (DAC_2/ADC2_CH9/GPIO26)

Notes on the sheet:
ESP32 Board
ESP32 Control
Display board

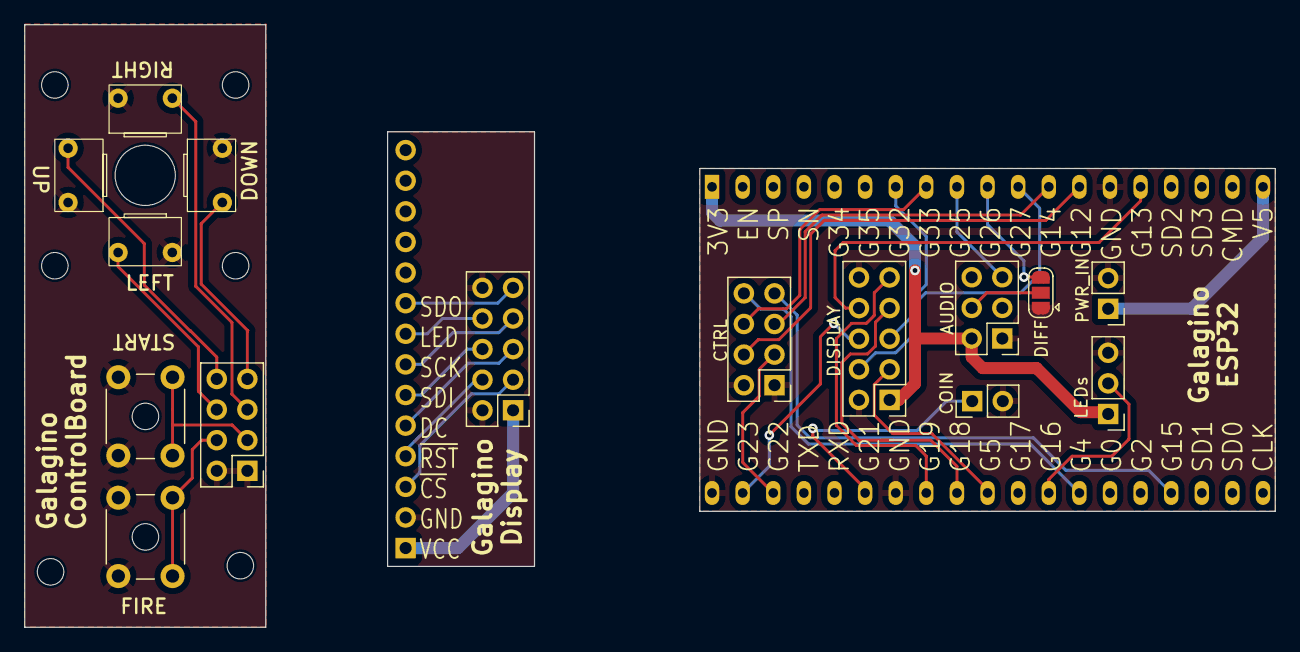
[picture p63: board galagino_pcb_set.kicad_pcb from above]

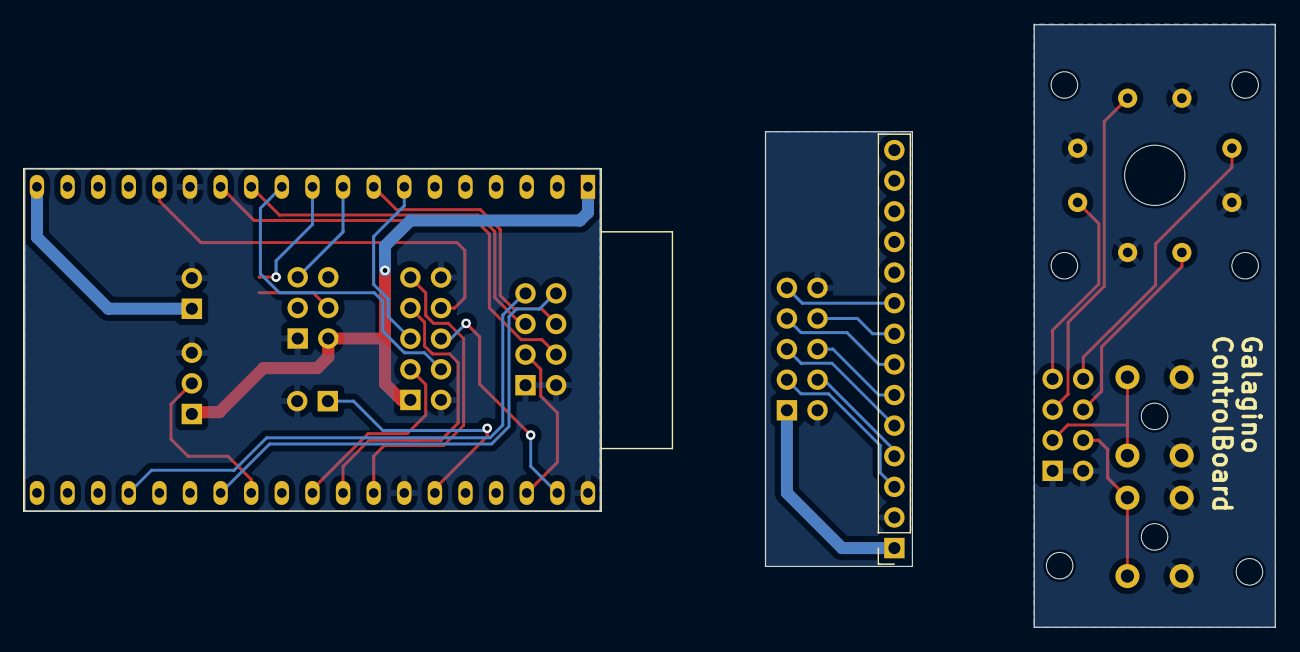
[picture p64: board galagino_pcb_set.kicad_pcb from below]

Board: 2 copper layers, 103.8 x 50.0 mm, 26 parts (2 on the bottom side), 37 nets.

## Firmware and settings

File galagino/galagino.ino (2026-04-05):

/*
 * Galagino.ino - Galaga arcade for ESP32 and Arduino IDE
 *
 * (c) 2023 Till Harbaum <till@harbaum.org>
 * 
 * Published under GPLv3
 *
 */

#include "config.h"

#include "driver/i2s.h"
#include "video.h"
#include "leds.h"

#include "emulation.h"

#include "tileaddr.h"

#if ESP_IDF_VERSION >= ESP_IDF_VERSION_VAL(4, 4, 5)
// See https://github.com/espressif/arduino-esp32/issues/8467
#define WORKAROUND_I2S_APLL_PROBLEM
// as a workaround we run dkong audio also at 24khz (instead of 11765)
// and fill the buffer at half the rate resulting in 12khz effective
// sample rate
unsigned char dkong_obuf_toggle = 0;
#endif

#define IO_EMULATION

// the hardware supports 64 sprites
unsigned char active_sprites = 0;
struct sprite_S *sprite;

// buffer space for one row of 28 characters
unsigned short *frame_buffer;

#ifdef NUNCHUCK_INPUT
#include "Nunchuck.h"
#endif

// include converted rom data
#ifdef ENABLE_PACMAN
#include "pacman.h"
#endif

#ifdef ENABLE_GALAGA
#include "galaga.h"
#endif

#ifdef ENABLE_DKONG
#include "dkong.h"
#endif

#ifdef ENABLE_FROGGER
#include "frogger.h"
#endif

#ifdef ENABLE_DIGDUG
#include "digdug.h"
#endif

#ifdef ENABLE_1942
#include "1942.h"
#endif

#ifndef SINGLE_MACHINE
signed char machine = MCH_MENU;   // start with menu
#endif

// instance of main tft driver
Video tft = Video();

TaskHandle_t emulationtask;

#ifdef ENABLE_GALAGA
// the ship explosion sound is stored as a digi sample.
// All other sounds are generated on the fly via the
// original wave tables
unsigned short snd_boom_cnt = 0;
const signed char *snd_boom_ptr = NULL;
#endif

#ifdef ENABLE_DKONG
unsigned short dkong_sample_cnt[3] = { 0,0,0 };
const signed char *dkong_sample_ptr[3];
#endif

#if defined(ENABLE_FROGGER) || defined(ENABLE_1942)
int ay_period[2][4] = {{0,0,0,0}, {0,0,0,0}};
int ay_volume[2][3] = {{0,0,0}, {0,0,0}};
int ay_enable[2][3] = {{0,0,0}, {0,0,0}};
int audio_cnt[2][4], audio_toggle[2][4] = {{1,1,1,1},{1,1,1,1}};
unsigned long ay_noise_rng[2] = { 1, 1 };
extern unsigned char soundregs[];
#endif

// one method to return to the main menu is to reset
// the entire machine. The main disadvantage is a 
// short noise from the speaker during reset
extern "C" void hw_reset(void);
void hw_reset(void) {
  ESP.restart();
}

#ifndef SINGLE_MACHINE
// convert rgb565 big endian color to greyscale
unsigned short greyscale(unsigned short in) {
  unsigned short r = (in>>3) & 31;
  unsigned short g = ((in<<3) & 0x38) | ((in>>13)&0x07);
  unsigned short b = (in>>8)& 31;
  unsigned short avg = (2*r + g + 2*b)/4;
  
  return (((avg << 13) & 0xe000) |   // g2-g0
          ((avg <<  7) & 0x1f00) |   // b5-b0
          ((avg <<  2) & 0x00f8) |   // r5-r0
          ((avg >>  3) & 0x0007));   // g5-g3
}

// render one of three the menu logos. Only the active one is colorful
// render logo into current buffer starting with line "row" of the logo
void render_logo(short row, const unsigned short *logo, char active) {
  unsigned short marker = logo[0];
  const unsigned short *data = logo+1;

  // current pixel to be drawn
  unsigned short ipix = 0;
    
  // less than 8 rows in image left?
  unsigned short pix2draw = ((row <= 96-8)?(224*8):((96-row)*224));
  
  if(row >= 0) {
    // skip ahead to row
    unsigned short col = 0;
    unsigned short pix = 0;
    while(pix < 224*row) {
      if(data[0] != marker) {
        pix++;
        data++;
      } else {
        pix += data[1]+1;
        col = data[2];
        data += 3;
      }
    }
    
    // draw pixels remaining from previous run
    if(!active) col = greyscale(col);
    while(ipix < ((pix - 224*row < pix2draw)?(pix - 224*row):pix2draw))
      frame_buffer[ipix++] = col;
  } else
    // if row is negative, then skip target pixel
    ipix -= row * 224;
    
  while(ipix < pix2draw) {
    if(data[0] != marker)
      frame_buffer[ipix++] = active?*data++:greyscale(*data++);
    else {
      unsigned short color = data[2];
      if(!active) color = greyscale(color);
      for(unsigned short j=0;j<data[1]+1 && ipix < pix2draw;j++)
        frame_buffer[ipix++] = color;

      data += 3;
    }
  }  
}
#endif

#ifndef SINGLE_MACHINE
// menu for more than three machines
const unsigned short *logos[] = {
#ifdef ENABLE_PACMAN    
  pacman_logo,
#endif
#ifdef ENABLE_GALAGA
  galaga_logo,
#endif
#ifdef ENABLE_DKONG    
  dkong_logo,
#endif
#ifdef ENABLE_FROGGER    
  frogger_logo,
#endif
#ifdef ENABLE_DIGDUG    
  digdug_logo,
#endif
#ifdef ENABLE_1942
  _1942_logo,
#endif
};
#endif

// render one of 36 tile rows (8 x 224 pixel lines)
void render_line(short row) {
  // the upper screen half of frogger has a blue background
  // using 8 in fact adds a tiny fraction of red as well. But that does not hurt
  memset(frame_buffer, 
#ifdef ENABLE_FROGGER 
    (MACHINE_IS_FROGGER && row <= 17)?8:
#endif
    0, 2*224*8);

#ifndef SINGLE_MACHINE
  if(machine == MCH_MENU) {

    if(MACHINES <= 3) {    
      // non-scrolling menu for 2 or 3 machines
      for(char i=0;i<sizeof(logos)/sizeof(unsigned short*);i++) {
      	char offset = i*12;
	      if(sizeof(logos)/sizeof(unsigned short*) == 2) offset += 6;
	
	      if(row >= offset && row < offset+12)  
	        render_logo(8*(row-offset), logos[i], menu_sel == i+1);
      }
    } else {
      // scrolling menu for more than 3 machines
    
      // valid offset values range from 0 to MACHINE*96-1
      static int offset = 0;

      // check which logo would show up in this row. Actually
      // two may show up in the same character row when scrolling
      int logo_idx = ((row + offset/8) / 12)%MACHINES;
      if(logo_idx < 0) logo_idx += MACHINES;
      
      int logo_y = (row * 8 + offset)%96;  // logo line in this row
      
      // check if logo at logo_y shows up in current row
      render_logo(logo_y, logos[logo_idx], (menu_sel-1) == logo_idx);
      
      // check if a second logo may show up here
      if(logo_y > (96-8)) {
        logo_idx = (logo_idx + 1)%MACHINES;
        logo_y -= 96;
        render_logo(logo_y, logos[logo_idx], (menu_sel-1) == logo_idx);
      }
      
      if(row == 35) {
      	// finally offset is bound to game, something like 96*game:    
	      int new_offset = 96*((unsigned)(menu_sel-2)%MACHINES);
	      if(menu_sel == 1) new_offset = (MACHINES-1)*96;
	
	      // check if we need to scroll
	      if(new_offset != offset) {
	        int diff = (new_offset - offset) % (MACHINES*96);
	        if(diff < 0) diff += MACHINES*96;
	  
	        if(diff < MACHINES*96/2) offset = (offset+8)%(MACHINES*96);
	        else                     offset = (offset-8)%(MACHINES*96);
	        if(offset < 0) offset += MACHINES*96;
      	}
      }
    }
  } else
#endif  

#ifdef ENABLE_PACMAN
PACMAN_BEGIN
  pacman_render_row(row);
PACMAN_END
#endif
  
#ifdef ENABLE_GALAGA
GALAGA_BEGIN
  galaga_render_row(row);
GALAGA_END
#endif

#ifdef ENABLE_DKONG
DKONG_BEGIN
  dkong_render_row(row);
DKONG_END
#endif

#ifdef ENABLE_FROGGER
FROGGER_BEGIN
  frogger_render_row(row);
FROGGER_END
#endif
  
#ifdef ENABLE_DIGDUG
DIGDUG_BEGIN
  digdug_render_row(row);
DIGDUG_END
#endif

#ifdef ENABLE_1942
_1942_BEGIN
  _1942_render_row(row);
_1942_END
#endif
}
  
#ifdef ENABLE_GALAGA
void galaga_trigger_sound_explosion(void) {
  if(game_started) {
    snd_boom_cnt = 2*sizeof(galaga_sample_boom);
    snd_boom_ptr = (const signed char*)galaga_sample_boom;
  }
}
#endif

#ifdef USE_NAMCO_WAVETABLE
static unsigned long snd_cnt[3] = { 0,0,0 };
static unsigned long snd_freq[3];
static const signed char *snd_wave[3];
static unsigned char snd_volume[3];
#endif

#ifdef SND_DIFF
static unsigned short snd_buffer[128]; // buffer space for two channels
#else
static unsigned short snd_buffer[64];  // buffer space for a single channel
#endif

void snd_render_buffer(void) {
#if defined(ENABLE_FROGGER) || defined(ENABLE_1942)
  #ifndef ENABLE_1942        // only frogger
    #define AY        1      // frogger has one AY
    #define AY_INC    9      // and it runs at 1.78 MHz -> 223718/24000 = 9,32
    #define AY_VOL   11      // min/max = -/+ 3*15*11 = -/+ 495
  #else
    #ifndef ENABLE_FROGGER   // only 1942
      #define AY      2      // 1942 has two AYs
      #define AY_INC  8      // and they runs at 1.5 MHz -> 187500/24000 = 7,81
      #define AY_VOL  4      // min/max = -/+ 6*15*4 = -/+ 360 (must fit in short after *64)
    #else
      // both enabled
      #define AY ((machine == MCH_FROGGER)?1:2)
      #define AY_INC ((machine == MCH_FROGGER)?9:8)
      #define AY_VOL ((machine == MCH_FROGGER)?11:4)
    #endif
  #endif
  
  if(
#ifdef ENABLE_FROGGER
     MACHINE_IS_FROGGER ||
#endif
#ifdef ENABLE_1942
     MACHINE_IS_1942 ||
#endif
     0) {

    // up to two AY's
    for(char ay=0;ay<AY;ay++) {
      int ay_off = 16*ay;

      // three tone channels
      for(char c=0;c<3;c++) {
	ay_period[ay][c] = soundregs[ay_off+2*c] + 256 * (soundregs[ay_off+2*c+1] & 15);
	ay_enable[ay][c] = (((soundregs[ay_off+7] >> c)&1) | ((soundregs[ay_off+7] >> (c+2))&2))^3;
	ay_volume[ay][c] = soundregs[ay_off+8+c] & 0x0f;
      }
      // noise channel
      ay_period[ay][3] = soundregs[ay_off+6] & 0x1f;
    }
  }
#endif

  // render first buffer contents
  for(int i=0;i<64;i++) {
    short v = 0;

#if defined(ENABLE_PACMAN) || defined(ENABLE_GALAGA)
  #ifndef SINGLE_MACHINE
    if(0
    #ifdef ENABLE_PACMAN
        || (machine == MCH_PACMAN)
    #endif
    #ifdef ENABLE_GALAGA
        || (machine == MCH_GALAGA)
    #endif
    #ifdef ENABLE_DIGDUG
        || (machine == MCH_DIGDUG)
    #endif
    ) 
  #endif
    {
      // add up to three wave signals
      if(snd_volume[0]) v += snd_volume[0] * snd_wave[0][(snd_cnt[0]>>13) & 0x1f];
      if(snd_volume[1]) v += snd_volume[1] * snd_wave[1][(snd_cnt[1]>>13) & 0x1f];
      if(snd_volume[2]) v += snd_volume[2] * snd_wave[2][(snd_cnt[2]>>13) & 0x1f];

  #ifdef ENABLE_GALAGA
      if(snd_boom_cnt) {
        v += *snd_boom_ptr;
        if(snd_boom_cnt & 1) snd_boom_ptr++;
        snd_boom_cnt--;
      }
  #endif
    }
#endif    

#ifdef ENABLE_DKONG
DKONG_BEGIN
    {
      v = 0;  // silence

      // no buffer available
      if(dkong_audio_rptr != dkong_audio_wptr)
        // copy data from dkong buffer into tx buffer
        // 8048 sounds gets 50% of the available volume range
#ifdef WORKAROUND_I2S_APLL_PROBLEM
        v = dkong_audio_transfer_buffer[dkong_audio_rptr][(dkong_obuf_toggle?32:0)+(i/2)];
#else
        v = dkong_audio_transfer_buffer[dkong_audio_rptr][i];
#endif
      // include sample sounds
      // walk is 6.25% volume, jump is at 12.5% volume and, stomp is at 25%
      for(char j=0;j<3;j++) {
        if(dkong_sample_cnt[j]) {
#ifdef WORKAROUND_I2S_APLL_PROBLEM
          v += *dkong_sample_ptr[j] >> (2-j); 
          if(i & 1) { // advance read pointer every second sample
            dkong_sample_ptr[j]++;
            dkong_sample_cnt[j]--;
          }
#else
          v += *dkong_sample_ptr[j]++ >> (2-j); 
          dkong_sample_cnt[j]--;
#endif
        }
      }
    }
DKONG_END
#endif

#if defined(ENABLE_FROGGER) || defined(ENABLE_1942)
    if(
#ifdef ENABLE_FROGGER
     MACHINE_IS_FROGGER ||
#endif
#ifdef ENABLE_1942
     MACHINE_IS_1942 ||
#endif
     0) {
    v = 0;  // silence
    
    for(char ay=0;ay<AY;ay++) {

      // frogger can acually skip the noise generator as
      // it doesn't use it      
      if(ay_period[ay][3]) {
	      // process noise generator
	      audio_cnt[ay][3] += AY_INC; // for 24 khz
	      if(audio_cnt[ay][3] > ay_period[ay][3]) {
	        audio_cnt[ay][3] -=  ay_period[ay][3];
	        // progress rng
	        ay_noise_rng[ay] ^= (((ay_noise_rng[ay] & 1) ^ ((ay_noise_rng[ay] >> 3) & 1)) << 17);
	        ay_noise_rng[ay] >>= 1;
	      }
      }
	
      for(char c=0;c<3;c++) {
	      // a channel is on if period != 0, vol != 0 and tone bit == 0
	      if(ay_period[ay][c] && ay_volume[ay][c] && ay_enable[ay][c]) {
	        short bit = 1;
	        if(ay_enable[ay][c] & 1) bit &= (audio_toggle[ay][c]>0)?1:0;  // tone
	        if(ay_enable[ay][c] & 2) bit &= (ay_noise_rng[ay]&1)?1:0;     // noise
	  
	        if(bit == 0) bit = -1;
	        v += AY_VOL * bit * ay_volume[ay][c];
	  
	        audio_cnt[ay][c] += AY_INC; // for 24 khz
	        if(audio_cnt[ay][c] > ay_period[ay][c]) {
	          audio_cnt[ay][c] -= ay_period[ay][c];
	          audio_toggle[ay][c] = -audio_toggle[ay][c];
	        }
	      }
      }
    }
    }
#endif
    // v is now in the range of +/- 512, so expand to +/- 15 bit
    v = v*MASTER_VOLUME;

#ifdef SND_DIFF
    // generate differential output
    snd_buffer[2*i]   = 0x8000 + v;    // positive signal on GPIO26
    snd_buffer[2*i+1] = 0x8000 - v;    // negatve signal on GPIO25 
#else
    // work-around weird byte order bug, see 
    // https://github.com/espressif/arduino-esp32/issues/8467#issuecomment-1656616015
    snd_buffer[i^1]   = 0x8000 + v;
#endif
      
#if defined(ENABLE_PACMAN) || defined(ENABLE_GALAGA)
    snd_cnt[0] += snd_freq[0];
    snd_cnt[1] += snd_freq[1];
    snd_cnt[2] += snd_freq[2];
#endif
  }
  
#ifdef ENABLE_DKONG
  #ifndef SINGLE_MACHINE
  if(machine == MCH_DKONG)
  #endif
  {
#ifdef WORKAROUND_I2S_APLL_PROBLEM
    if(dkong_obuf_toggle)
#endif
      // advance write pointer. The buffer is a ring
      dkong_audio_rptr = (dkong_audio_rptr+1)&DKONG_AUDIO_QUEUE_MASK;
#ifdef WORKAROUND_I2S_APLL_PROBLEM
    dkong_obuf_toggle = !dkong_obuf_toggle;
#endif
  }
#endif
}

#ifdef USE_NAMCO_WAVETABLE
void audio_namco_waveregs_parse(void) {
#ifndef SINGLE_MACHINE
  if(
#ifdef ENABLE_PACMAN
    MACHINE_IS_PACMAN ||
#endif    
#ifdef ENABLE_GALAGA    
    MACHINE_IS_GALAGA ||
#endif
#ifdef ENABLE_DIGDUG    
    MACHINE_IS_DIGDUG ||
#endif
  0) 
#endif  
  {
    // parse all three wsg channels
    for(char ch=0;ch<3;ch++) {  
      // channel volume
      snd_volume[ch] = soundregs[ch * 5 + 0x15];
    
      if(snd_volume[ch]) {
        // frequency
        snd_freq[ch] = (ch == 0) ? soundregs[0x10] : 0;
        snd_freq[ch] += soundregs[ch * 5 + 0x11] << 4;
        snd_freq[ch] += soundregs[ch * 5 + 0x12] << 8;
        snd_freq[ch] += soundregs[ch * 5 + 0x13] << 12;
        snd_freq[ch] += soundregs[ch * 5 + 0x14] << 16;
      
        // wavetable entry
#ifdef ENABLE_PACMAN
  #if defined(ENABLE_GALAGA) || defined(ENABLE_DIGDUG)  // there's at least a second machine
        if(machine == MCH_PACMAN)
  #endif
          snd_wave[ch] = pacman_wavetable[soundregs[ch * 5 + 0x05] & 0x0f];
  #if defined(ENABLE_GALAGA) || defined(ENABLE_DIGDUG)
        else
  #endif      
#endif      
#ifdef ENABLE_GALAGA
  #ifdef ENABLE_DIGDUG
        if(machine == MCH_GALAGA)
  #endif
          snd_wave[ch] = galaga_wavetable[soundregs[ch * 5 + 0x05] & 0x07];
#endif      
#ifdef ENABLE_DIGDUG
          snd_wave[ch] = digdug_wavetable[soundregs[ch * 5 + 0x05] & 0x0f];
#endif      
      }
    }
  }
}
#endif  // MCH_PACMAN || MCH_GALAGA

#ifdef ENABLE_DKONG
void dkong_trigger_sound(char snd) {
  static const struct {
    const signed char *data;
    const unsigned short length; 
  } samples[] = {
    { (const signed char *)dkong_sample_walk0, sizeof(dkong_sample_walk0) },
    { (const signed char *)dkong_sample_walk1, sizeof(dkong_sample_walk1) },
    { (const signed char *)dkong_sample_walk2, sizeof(dkong_sample_walk2) },
    { (const signed char *)dkong_sample_jump,  sizeof(dkong_sample_jump)  },
    { (const signed char *)dkong_sample_stomp, sizeof(dkong_sample_stomp) }
  };

  // samples 0 = walk, 1 = jump, 2 = stomp

  if(!snd) {
    // walk0, walk1 and walk2 are variants
    char rnd = random() % 3;
    dkong_sample_cnt[0] = samples[rnd].length;
    dkong_sample_ptr[0] = samples[rnd].data;
  } else {
    dkong_sample_cnt[snd] = samples[snd+2].length;
    dkong_sample_ptr[snd] = samples[snd+2].data;
  }
}
#endif

void snd_transmit() {
  // (try to) transmit as much audio data as possible. Since we
  // write data in exact the size of the DMA buffers we can be sure
  // that either all or nothing is actually being written
  
  size_t bytesOut = 0;
  do {
    // copy data in i2s dma buffer if possible
    i2s_write(I2S_NUM_0, snd_buffer, sizeof(snd_buffer), &bytesOut, 0);

    // render the next audio chunk if data has actually been sent
    if(bytesOut) {
#if defined(ENABLE_PACMAN) || defined(ENABLE_GALAGA)
      audio_namco_waveregs_parse();
#endif
      snd_render_buffer();
    }
  } while(bytesOut);
}

void audio_dkong_bitrate(char is_dkong) {
  // The audio CPU of donkey kong runs at 6Mhz. A full bus
  // cycle needs 15 clocks which results in 400k cycles
  // per second. The sound CPU typically needs 34 instruction
  // cycles to write an updated audio value to the external
  // DAC connected to port 0.
  
  // The effective sample rate thus is 6M/15/34 = 11764.7 Hz
#ifndef WORKAROUND_I2S_APLL_PROBLEM
  i2s_set_sample_rates(I2S_NUM_0, is_dkong?11765:24000);
#endif
}

void audio_init(void) {  
  // init audio
#if defined(ENABLE_PACMAN) || defined(ENABLE_GALAGA)
  audio_namco_waveregs_parse();
#endif
  snd_render_buffer();

  // 24 kHz @ 16 bit = 48000 bytes/sec = 800 bytes per 60hz game frame =
  // 1600 bytes per 30hz screen update = ~177 bytes every four tile rows
  static const i2s_config_t i2s_config = {
    .mode = (i2s_mode_t)(I2S_MODE_MASTER | I2S_MODE_TX | I2S_MODE_DAC_BUILT_IN),
    .sample_rate = 24000,
    .bits_per_sample = I2S_BITS_PER_SAMPLE_16BIT,
#ifdef SND_DIFF
    .channel_format = I2S_CHANNEL_FMT_RIGHT_LEFT,
#elif defined(SND_LEFT_CHANNEL) // For devices using the left channel (e.g. CYD)
    .channel_format = I2S_CHANNEL_FMT_ONLY_LEFT,
#else
    .channel_format = I2S_CHANNEL_FMT_ONLY_RIGHT,
#endif
    .intr_alloc_flags = 0,
    .dma_buf_count = 4,
    .dma_buf_len = 64,   // 64 samples
#ifndef WORKAROUND_I2S_APLL_PROBLEM
    .use_apll = true
#else
    // APLL usage is broken in ESP-IDF 4.4.5
    .use_apll = false
#endif
  };

  i2s_driver_install(I2S_NUM_0, &i2s_config, 0, NULL);

#if defined(SINGLE_MACHINE) && defined(ENABLE_DKONG)
  // only dkong installed? Then setup rate immediately
  audio_dkong_bitrate(true);
#endif

#ifdef SND_DIFF
  i2s_set_dac_mode(I2S_DAC_CHANNEL_BOTH_EN);
#elif defined(SND_LEFT_CHANNEL) // For devices using the left channel (e.g. CYD)
  i2s_set_dac_mode(I2S_DAC_CHANNEL_LEFT_EN); 
#else
  i2s_set_dac_mode(I2S_DAC_CHANNEL_RIGHT_EN);
#endif
}

void update_screen(void) {
  uint32_t t0 = micros();

#ifdef ENABLE_PACMAN
PACMAN_BEGIN
  pacman_prepare_frame();    
PACMAN_END
#endif

#ifdef ENABLE_GALAGA
GALAGA_BEGIN
  galaga_prepare_frame();
GALAGA_END
#endif  
  
#ifdef ENABLE_DKONG
DKONG_BEGIN
  dkong_prepare_frame();
DKONG_END
#endif

#ifdef ENABLE_FROGGER
FROGGER_BEGIN
  frogger_prepare_frame();
FROGGER_END
#endif

#ifdef ENABLE_DIGDUG
DIGDUG_BEGIN
  digdug_prepare_frame();
DIGDUG_END
#endif

#ifdef ENABLE_1942
_1942_BEGIN
  _1942_prepare_frame();
_1942_END
#endif

  // max possible video rate:
  // 8*224 pixels = 8*224*16 = 28672 bits
  // 2790 char rows per sec at 40Mhz = max 38 fps
#if TFT_SPICLK < 80000000
#define VIDEO_HALF_RATE
#endif

#ifdef VIDEO_HALF_RATE
  // render and transmit screen in two halfs as the display
  // running at 40Mhz can only update every second 60 hz game frame
  for(int half=0;half<2;half++) {

    for(int c=18*half;c<18*(half+1);c+=3) {
      render_line(c+0); tft.write(frame_buffer, 224*8);
      render_line(c+1); tft.write(frame_buffer, 224*8);
      render_line(c+2); tft.write(frame_buffer, 224*8);

      // audio is refilled 6 times per screen update. The screen is updated
      // every second frame. So audio is refilled 12 times per 30 Hz frame.
      // Audio registers are udated by CPU3 two times per 30hz frame.
      snd_transmit();
    } 
 
    // one screen at 60 Hz is 16.6ms
    unsigned long t1 = (micros()-t0)/1000;  // calculate time in milliseconds
    // printf("uspf %d\n", t1);
    if(t1<(half?33:16)) vTaskDelay((half?33:16)-t1);
    else if(half)       vTaskDelay(1);    // at least 1 ms delay to prevent watchdog timeout

    // physical refresh is 30Hz. So send vblank trigger twice a frame
    // to the emulation. This will make the game run with 60hz speed
    xTaskNotifyGive(emulationtask);
  }
#else
  #warning FULL SPEED
  
  // render and transmit screen at once as the display
  // running at 80Mhz can update at full 60 hz game frame
  for(int c=0;c<36;c+=6) {
    render_line(c+0); tft.write(frame_buffer, 224*8);
    render_line(c+1); tft.write(frame_buffer, 224*8);
    render_line(c+2); tft.write(frame_buffer, 224*8);
    render_line(c+3); tft.write(frame_buffer, 224*8);
    render_line(c+4); tft.write(frame_buffer, 224*8);
    render_line(c+5); tft.write(frame_buffer, 224*8);

    // audio is updated 6 times per 60 Hz frame
    snd_transmit();
  } 
 
  // one screen at 60 Hz is 16.6ms
  unsigned long t1 = (micros()-t0)/1000;  // calculate time in milliseconds
  if(t1<16) vTaskDelay(16-t1);
  else      vTaskDelay(1);    // at least 1 ms delay to prevent watchdog timeout

  // physical refresh is 60Hz. So send vblank trigger once a frame
  xTaskNotifyGive(emulationtask);
#endif
   
#ifdef ENABLE_GALAGA
  /* the screen is only updated every second frame, scroll speed is thus doubled */
  static const signed char speeds[8] = { -1, -2, -3, 0, 3, 2, 1, 0 };
  stars_scroll_y += 2*speeds[starcontrol & 7];
#endif
}

void emulation_task(void *p) {
  prepare_emulation();

  while(1)
    emulate_frame();
}

void setup() {
  Serial.begin(115200);
  Serial.println("Galagino"); 

  Serial.print("ESP-IDF "); 
  Serial.println(ESP_IDF_VERSION, HEX);
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
void loop(void) {
  // run video in main task. This will send signals
  // to the emulation task in the background to 
  // synchronize video
  update_screen(); 

#ifdef LED_PIN
  leds_update();
#endif
}

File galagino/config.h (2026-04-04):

#ifndef _CONFIG_H_
#define _CONFIG_H_

// disable e.g. if roms are missing
#define ENABLE_PACMAN
#define ENABLE_GALAGA
#define ENABLE_DKONG
#define ENABLE_FROGGER
#define ENABLE_DIGDUG
#define ENABLE_1942

#if !defined(ENABLE_PACMAN) && !defined(ENABLE_GALAGA) && !defined(ENABLE_DKONG) && !defined(ENABLE_FROGGER) && !defined(ENABLE_DIGDUG) && !defined(ENABLE_1942)
#error "At least one machine has to be enabled!"
#endif

// check if only one machine is enabled
#if (( defined(ENABLE_PACMAN) && !defined(ENABLE_GALAGA) && !defined(ENABLE_DKONG) && !defined(ENABLE_FROGGER) && !defined(ENABLE_DIGDUG) && !defined(ENABLE_1942)) || \
     (!defined(ENABLE_PACMAN) &&  defined(ENABLE_GALAGA) && !defined(ENABLE_DKONG) && !defined(ENABLE_FROGGER) && !defined(ENABLE_DIGDUG) && !defined(ENABLE_1942)) || \
     (!defined(ENABLE_PACMAN) && !defined(ENABLE_GALAGA) &&  defined(ENABLE_DKONG) && !defined(ENABLE_FROGGER) && !defined(ENABLE_DIGDUG) && !defined(ENABLE_1942)) || \
     (!defined(ENABLE_PACMAN) && !defined(ENABLE_GALAGA) && !defined(ENABLE_DKONG) &&  defined(ENABLE_FROGGER) && !defined(ENABLE_DIGDUG) && !defined(ENABLE_1942)) || \
     (!defined(ENABLE_PACMAN) && !defined(ENABLE_GALAGA) && !defined(ENABLE_DKONG) && !defined(ENABLE_FROGGER) &&  defined(ENABLE_DIGDUG) && !defined(ENABLE_1942)) || \
     (!defined(ENABLE_PACMAN) && !defined(ENABLE_GALAGA) && !defined(ENABLE_DKONG) && !defined(ENABLE_FROGGER) && !defined(ENABLE_DIGDUG) &&  defined(ENABLE_1942)))
  #define SINGLE_MACHINE
#endif

// game config

#define MASTER_ATTRACT_MENU_TIMEOUT  20000   // start games randomly while sitting idle in menu for 20 seconds, undefine to disable

#include "dip_switches.h"

// #define CHEAP_YELLOW_DISPLAY_CONF

#ifndef CHEAP_YELLOW_DISPLAY_CONF // Config as it was before

// video config
#define TFT_SPICLK  40000000    // 40 Mhz. Some displays cope with 80 Mhz

#define TFT_CS   5
#define TFT_DC  32
#define TFT_RST 27
#define TFT_BL  13    // don't set if backlight is hard wired
#define TFT_ILI9341   // define for ili9341, otherwise st7789
#define TFT_VFLIP     // define for upside down

// x and y offset of 224x288 pixels inside the 240x320 screen
#define TFT_X_OFFSET  8
#define TFT_Y_OFFSET 16

#define LED_PIN        16   // pin used for optional WS2812 stripe
#define LED_BRIGHTNESS 50   // range 0..255

// audio config
#define MASTER_VOLUME  64   // master volume scaler, default 64 (max), range 1-64
// #define SND_DIFF   // set to output differential audio on GPIO25 _and_ inverted on GPIO26

// Pins used for buttons
#define BTN_START_PIN  22
#define BTN_COIN_PIN   21   // if this is not defined, then start will act as coin & start
#define BTN_LEFT_PIN   33
#define BTN_RIGHT_PIN  14
#define BTN_DOWN_PIN   15
#define BTN_UP_PIN      4
#define BTN_FIRE_PIN   12

#else                       // Cheap Yellow Display Conf

// video config
#define TFT_SPICLK 40000000 // 40 Mhz. Some displays cope with 80 Mhz

#define TFT_MISO 12
#define TFT_MOSI 13
#define TFT_SCLK 14

#define TFT_CS 15
#define TFT_DC 2
#define TFT_RST -1
#define TFT_BL 21   // don't set if backlight is hard wired
#define TFT_ILI9341 // define for ili9341, otherwise st7789
// #define TFT_VFLIP   // define for upside down

// #define TFT_MAC  0x20  // some CYD need this to rotate properly and have correct colors

// x and y offset of 224x288 pixels inside the 240x320 screen
#define TFT_X_OFFSET 8
#define TFT_Y_OFFSET 16

#define LED_PIN 16        // pin used for optional WS2812 stripe
#define LED_BRIGHTNESS 50 // range 0..255

// audio config (leave both commented out for GPIO 25 for Audio)
// #define SND_DIFF   // set to output differential audio on GPIO25 _and_ inverted on GPIO26
#define SND_LEFT_CHANNEL // Use GPIO 26 for audio

#define NUNCHUCK_INPUT

#define NUNCHUCK_SDA 22
#define NUNCHUCK_SCL 27

#define NUNCHUCK_MOVE_THRESHOLD 30 // This is the dead-zone for where minor movements on the stick will not be considered valid movements

// Pins used for buttons
#define BTN_START_PIN 0 //This is the "boot" button
// #define BTN_COIN_PIN 21 // if this is not defined, then start will act as coin & start

#endif // #ifndef CHEAP_YELLOW_DISPLAY_CONF

#endif // _CONFIG_H_

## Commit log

2023-01-15 Add fritzing scheme
    [galagino.fzz]
2023-01-27 typo: 80's → ’80s
2023-01-27 Add 5 way joystick setup
    [galagino.fzz]
2023-01-28 Add missing spring sample
2023-01-29 Fix colormap masking, fixes #4
    [galagino.ino]
2023-01-31 Fix i2s audio for 2.0.6
    [galagino.ino]
2023-02-04 Add some dkong spounds an implement video DMA as described in #10
2023-02-04 Allow for 60 hz video if hardware copes with that
2023-02-04 Link to VGA ESP32
2023-02-05 Add option to combine coin and start button. Implements #8
2023-02-11 Add missing Galaga sound sample
2023-02-12 Balance dkong volumes and mix samples
2023-02-12 Reset to menu when coin is pressed > 1 sec
    [galagino.ino]
2023-02-19 Disable backlight before reset
    [galagino.ino]
2023-03-08 Add control board CAD files
    [galagino_controlboard-actuator.stl, galagino_controlboard-base.stl, galagino_controlboard-knob.stl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]
2023-03-22 Marquee and coin button CAD files
    [coinbutton.FCStd, coinbutton.stl, marquee.FCStd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]
2023-03-22 Add assembly instructions
2023-03-23 Lasercut cabinet
2023-03-25 More assembly instructions
2023-03-29 Add case plan
2023-03-29 Cabinet Assembly descriptions
2023-03-31 coinbutton mounting
2023-04-23 Controlboard wireing
2023-04-23 Update controlboard files
    [galagino_controlboard-limiter.stl]
2023-04-23 more wiring instructions
2023-04-23 joystick assembly
2023-05-25 Link to 3d printed case
2023-06-27 Adding support for CYD, non standard SPI pins and nunchuck
2023-06-29 Adding info about the start button
2023-06-30 Fix for default setup
    [config.h, galagino.ino]
2023-07-27 Mention issues with PlatformIO and ESP board package > 2.0.9
2023-07-28 Fix audio channel mapping
    [galagino.ino]
2023-07-29 Workaround byte order bug in ESP IDF
    [galagino.ino]
2023-07-29 Implement workaround for #27
    [galagino.ino]
2023-11-01 Adding Pre-processor logic for left channel devices
2023-12-26 Add PCB setup
    [btn_raiser.FCStd, controlboard.FCStd, galagino_pcb_set.kicad_pcb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]
2024-02-02 Add nunchuck button C handling as COIN/START alternative.
2024-03-03 Update control board case
    [controlboard.FCStd, controlboard_actuator.stl, controlboard_base.stl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]
2024-03-03 Add btn_raiser
    [btn_raiser.stl]
2024-03-03 Update pcb readme
2024-03-05 Deepen screw head holes
    [controlboard.FCStd, controlboard_base.stl]
2024-03-06 Case variant with cuts for battery charger and switch
2024-03-06 Moved power switch up a little bit
2024-03-11 Update cabinet for use with a battery
2024-03-11 Desciption of battery usage
2026-04-04 Fix 1942 audio distortion and add master volume control
    1942 has 2 AY chips (6 channels) but AY_VOL was set to 10, producing
    a max amplitude of 900 before the *64 scaler. This overflowed the
    signed short range (32,767), causing severe clipping and distortion.
    Reduced AY_VOL to 4 to keep within range.
    Added MASTER_VOLUME define in config.h to allow tuning the overall
    audio output level (range 1-64, default 64).
    [config.h, galagino.ino]
2026-04-04 Fix Galaga fire edge detection and menu return
    Galaga: the Namco 06xx 3-byte polling cycle read buttons and updated
    prev_mask on every byte, so fire/coin/start edges were frequently
    consumed on byte 0 (credit byte) before the byte that encodes them.
    Sample buttons once at namco_cnt==0 and latch the fire edge for the
    whole cycle so byte 1 always reports it reliably.
    buttons_get: the BUTTON_EXTRA detection was wrapped in nested
    #ifndef/#ifdef BTN_COIN_PIN, making the inner branch dead code and
    leaving BUTTON_EXTRA unset whenever BTN_COIN_PIN was defined. Restored
    the intended behavior (coin pin when present, start pin otherwise) and
    raised the hold threshold to 3 seconds to avoid accidental r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
    [galaga.h, galagino.ino]
2026-04-04 Minor correctness fixes
    setCpuFrequencyMhz takes MHz, not Hz — 240000000 is rejected by the
    ESP32 core as an invalid frequency and silently does nothing. Passes
    240 so the call actually works (the CPU is already at 240MHz on boot,
    so no behavioral change).
    Pac-Man sound register write had a precedence bug: "a != b & 0x0f"
    parses as "(a != b) & 0x0f" because != binds tighter than bitwise &.
    Added parentheses to compare against the masked value as intended.
    Functionally harmless since the write value is correct either way,
    just triggers occasional redundant writes.
    Added no-op stubs in leds.h for builds without LED_PIN. galaga.h calls
    leds_state_reset() and leds_check_galaga_sprite() uncon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
    [galagino.ino, leds.h]
